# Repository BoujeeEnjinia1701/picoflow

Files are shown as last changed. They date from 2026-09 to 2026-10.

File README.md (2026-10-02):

# PicoFlow

     

**Area:** CleanTech · **TRL:** 3 of 9 (proof of concept on paper) · **Value-engineering target:** about $450 USD · **Difficulty:** 3 of 5

3D-printed Turgo runner in a printed or PVC nozzle housing, driving an off-the-shelf BLDC motor used as a generator, with an MPPT dump-load controller.

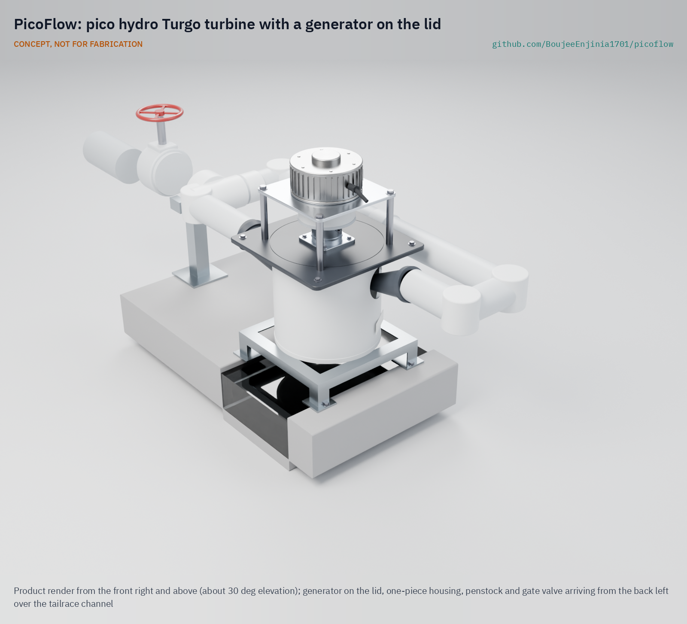
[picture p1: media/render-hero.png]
PicoFlow: pico hydro Turgo turbine with a generator on the lid, product render


[Exploded render](media/render-exploded.png) · [Detail render](media/render-detail.png) · [Interactive 3D model](media/viewer.html) · [Concept blueprint (PDF)](media/concept-blueprint.pdf) · [General arrangement (PDF)](cad/drawings/PCF-DWG-001.pdf) · [Sizing calculations](docs/04-calcs/01-sizing.md) · [Prototype build plan](docs/05-build-plan.md) · [Design decisions](docs/06-design-decisions.md) · [Review note](docs/REVIEW.md)

## Concept rationale

A Turgo runner suits the low heads and debris-laden streams that most households near water actually have. It runs in air above the tailwater, tolerates leaves and sand better than a closed propeller, and keeps its efficiency at part flow, so one runner covers 1 to 3 m of head by changing only the nozzle inserts. Putting the bearings and generator on the lid, above the spray, addresses the main reason cheap low-head units fail: bearings and windings that sit in or near the water.

The design is open and garage-buildable because the households that need it are far from spare-parts supply chains. A 200 mm runner prints on a common desktop printer in about a day, the housing and pipework are standard PVC, and the generator is an off-the-shelf low-speed motor, with a salvaged washing machine motor as the low-cost variant. A local workshop can therefore build, repair and adapt it without depending on a single supplier.

## Burning platform

About 666 million people still had no electricity in 2023, and 85 % of them live in sub-Saharan Africa ([World Bank, Tracking SDG 7: The Energy Progress Report 2025](https://www.worldbank.org/en/topic/energy/publication/tracking-sdg-7-the-energy-progress-report-2025)). Many live in hilly, well-watered areas where a stream runs past the house day and night, and pico hydro turns that flow into continuous power that solar alone cannot match after dark or in the rainy season.

The market has already shown both the demand and the failure mode. In Vietnam, 100,000 to 120,000 cheap low-head propeller units were sold over 10 to 15 years, but probably no more than 30,000 were still running, because most became unusable within 2 to 3 years as lower bearings, seals and generator windings failed ([DFID project R8150, Vietnam country report](https://assets.publishing.service.gov.uk/media/57a08cf340f0b652dd001676/R8150-Vietnam.pdf)). Households paid again and again for power that did not last.

## Where it could be used

### By industry

| Industry | Use |
| --- | --- |
| Rural energy access | Continuous battery charging for lights, phones, radio and small appliances in off-grid homes near streams |
| Agriculture | Power for fence energizers, pump controls, lighting and monitoring on farms with irrigation channels or spring outflows |
| Health and education in remote areas | A second, round-the-clock source beside solar for rural clinics and schools, strongest in the rainy season |
| Tourism and remote huts | Quiet, fuel-free power for mountain huts, lodges and cabins on a stream |
| Environmental monitoring | Local power for stream gauges, water-quality sensors and camera traps at the water's edge |
| Technical training | An inspectable turbine for teaching fluid machinery, power electronics and hydropower siting |

### By country or region

| Country or region | Why it matters there |
| --- | --- |
| Sub-Saharan Africa (for example the highlands of Rwanda, Uganda and eastern DR Congo) | Home to 85 % of the people without electricity ([World Bank, 2025](https://www.worldbank.org/en/topic/energy/publication/tracking-sdg-7-the-energy-progress-report-2025)); many highland homes sit near year-round streams |
| Vietnam (northern uplands) | A proven market for household pico hydro, where most cheap units fail in 2 to 3 years ([DFID R8150](https://assets.publishing.service.gov.uk/media/57a08cf340f0b652dd001676/R8150-Vietnam.pdf)); a durable, repairable unit fits existing habits |
| Nepal | Steep hill streams and a long-standing national program for micro and mini hydro ([AEPC](https://www.aepc.gov.np/pages/minimicro-hydro)); pico units can reach homes beyond a village scheme |
| Peru | A World Bank-supported rural electrification project installed 11,915 solar home systems in isolated areas and prepared studies for 21 small hydropower projects in the country's major basins ([World Bank, 2019](https://www.worldbank.org/en/results/2019/05/13/promoting-rural-electrification-in-peru)); a pico unit could serve scattered mountain homes on a stream beyond those schemes |
| New Zealand and the United Kingdom | High-income off-grid cabins and farms already use commercial pico turbines such as the New Zealand-made PowerSpout ([PowerSpout LH](https://www.powerspout.com/pages/low-head-lh-info)); an open design lowers the cost of a repairable, low-head alternative |

## What sparked the idea

The idea traces back to the Turgo turbine itself. In 1919 the young engineer Eric Crewdson, then a trainee at the English turbine maker Gilkes of Kendal, applied for a patent on a side-entry impulse runner that would run at twice the speed of a Pelton wheel on the same head, with jets striking one side at an angle and discharging from the other; the patent was granted in 1920 ([Gilkes, "100 Years of the Turgo Impulse Turbine"](https://www.gilkes.com/media/1809/100-yrs-of-the-turgo-impulse-rev-4.pdf)). A century on, that higher speed at low head is what lets a small runner drive an off-the-shelf motor directly, without a gearbox, and the University of Bristol's 2013 tests of a Turgo at heads from 3.5 m down to 1 m, which reached 87 % jet-to-mechanical efficiency at 1 m ([Williamson, Stark and Booker, Applied Energy 102](https://research-information.bris.ac.uk/en/publications/performance-of-a-low-head-pico-hydro-turgo-turbine)), showed the principle holds far below its usual range. PicoFlow is an attempt to put Crewdson's runner into a form that a village workshop can print and repair.

## Problem

Remote homes near streams with 1 to 3 m of head have few durable, repairable turbine options: cheap closed units wear out in two or three years, and durable ones cost several times a household budget.

## Concept

3D-printed Turgo runner in a printed or PVC nozzle housing, driving an off-the-shelf BLDC motor used as a generator, with an MPPT dump-load controller.

At 2 m of head and 10 L/s, the TRL 3 sizing calculation (PCF-CAL-001) gives about 86 W into a 12 V battery, or about 2.05 kWh a day, running around the clock, with a 125 mm penstock; pipe, valve and branch losses take about 16 % of the head. The generator sits on the lid above the spray, the dump load keeps the runner from running away when the battery is full, and a hardware clamp holds the DC side below 48 V if the controller fails.

Full design precis: [docs/02-concept.md](docs/02-concept.md)

## Key components

- Printed Turgo runner, 200 mm (PETG prototype, glass-filled nylon for field units), with two opposed 34 mm jets from printed nozzles bolted to the housing
- New low-speed 500 W BLDC motor as generator (a salvaged washing machine motor is the low-cost variant)
- Two sealed flange bearing units above the spray on a stainless shaft
- 125 mm PVC penstock with a slow-closing, full-bore gate valve, forebay screen and 315 mm PVC housing
- Three-phase rectifier
- Open-design MPPT, dump-load and clamp controller for a 12 V battery
- 300 W dump-load resistor and 6.8 ohm, 350 W clamp resistor

The priced bill of materials is in [bom/bom.csv](bom/bom.csv): about $618 for the turbine kit with a new generator, against a value-engineering target of $450; penstock and battery excluded.

## Building the prototype

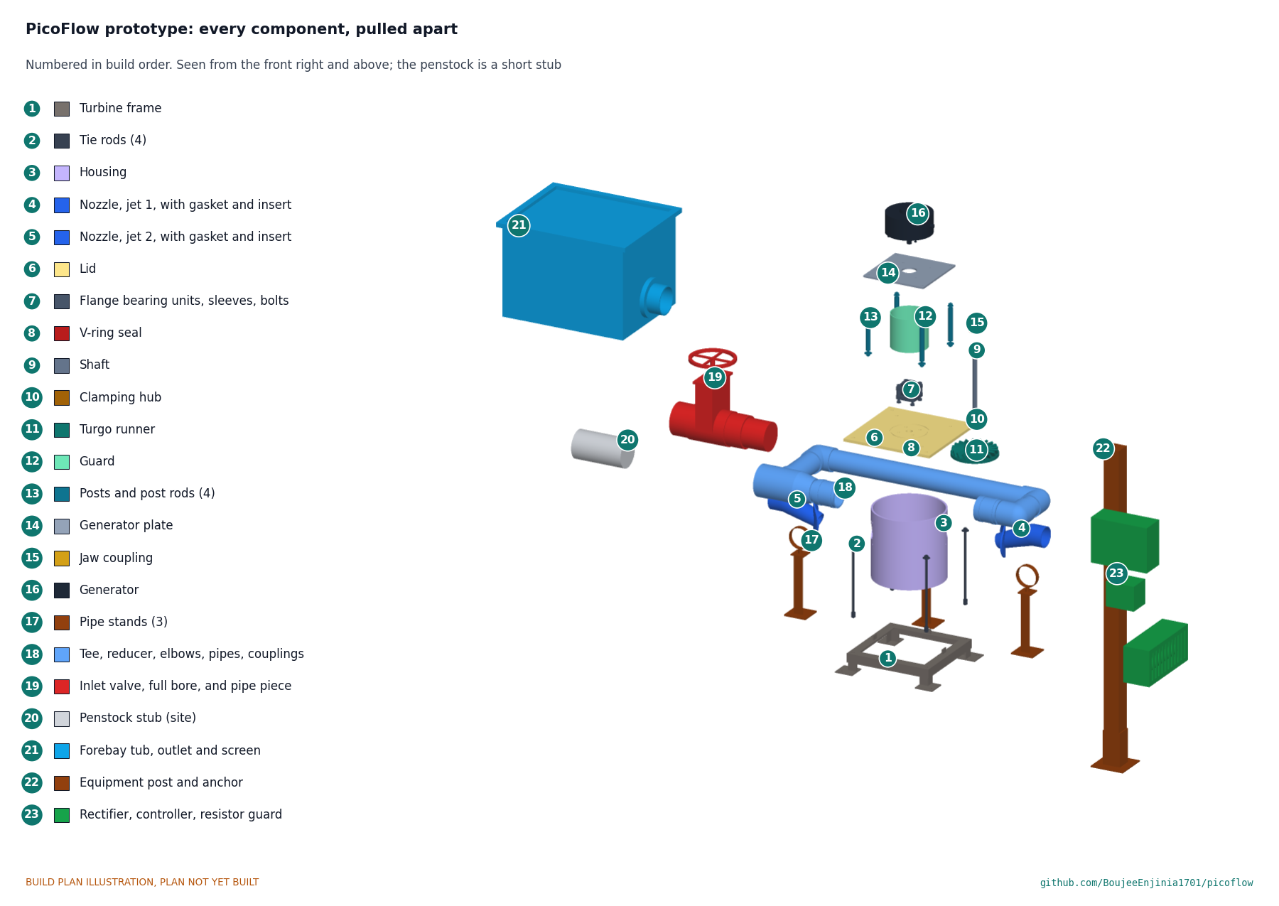
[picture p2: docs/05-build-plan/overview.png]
PicoFlow prototype: every component pulled apart and numbered in build order


The [prototype build plan](docs/05-build-plan.md) (PCF-BLD-001) shows, in pictures, how to make each of the 23 components and put them together in nineteen steps; nothing has been built yet. The made parts are a welded steel frame, a housing cut from sewer pipe, printed nozzles, inserts and runner, a plastic lid, posts, a generator plate, pipe stands, the cut pipework, a forebay and an equipment post; the bearings, generator, fittings, valve and electrics are bought. Writing the plan made the design buildable: tie rods now clamp lid, housing and frame together, flange bearing units replace a machined housing, the nozzles bolt to the housing through gasketed saddles, and the pipework uses standard fittings on three stands (PCF-DDR-003, open for Amish's review). Every picture is drawn from the model, which checks that each part touches what it should and clears what it should not.

## Safety

> Streams and weirs can drown people; install and service only at low flow. The runner and coupling rotate; close the valve and wait for them to stop before opening the housing. With no load and a failed clamp the generator can exceed 60 V DC, so the DC side stays enclosed; the dump load and clamp resistor run hot. Close the gate valve slowly. The 12 V battery needs a BMS and a fuse at the terminal.

## Repository layout

| Folder | Contents |
| --- | --- |
| `docs/` | Problem, concept, requirements, calculations and design decisions |
| `cad/src/` | build123d Python source, the source of truth for all geometry |
| `cad/step/`, `cad/stl/` | Exported models for FreeCAD, other CAD tools and printing |
| `cad/drawings/` | 2D sketches and dimensioned drawings |
| `bom/` | Bill of materials |
| `electronics/` | KiCad schematics and PCB layouts |
| `firmware/` | Microcontroller code |
| `media/` | Renders, perspectives and photos |
| `build-log/` | Dated prototyping notes |

## Documentation

Controlled documents follow the portfolio [documentation standard](.kit/STANDARDS.md). Each carries a document ID (PCF-PRC-001 for the precis), a version and a revision history. Branded PDFs are built with `python .kit/render.py` and attached to GitHub Releases when a document is tagged, for example `PCF-PRC-001/v1.0`.

## Credits

Designed by Amish Chadha. See [CONTRIBUTORS.md](CONTRIBUTORS.md) for roles. To cite this design, use [CITATION.cff](CITATION.cff) (GitHub shows it as "Cite this repository").

AI assistance (Claude) was used to accelerate concept renders, prototype documentation and first-pass sizing calculations. Design direction and all decisions are Amish Chadha's, recorded in this repository's decision records (`docs/decisions/`).

## Licenses

- **Hardware** (CAD, drawings, BOM, electronics): [CERN-OHL-S v2](LICENSE)
- **Software** (firmware, scripts, notebooks): [MIT](LICENSE-SOFTWARE)

A project of the [Design Molecule](https://designmolecule.com) lab.

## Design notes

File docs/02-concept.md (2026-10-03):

---
doc_id: PCF-PRC-001
title: PicoFlow design precis
project: PicoFlow
doc_type: Design precis
version: "0.9"
status: Draft
date: '2026-10-02'
author: Amish Chadha
license: CERN-OHL-S-2.0
revisions:
- version: "0.1"
  date: '2026-09-24'
  author: Amish Chadha
  change: Initial scaffold
- version: "0.2"
  date: '2026-09-25'
  author: Amish Chadha
  change: Populate to TRL 2 (architecture, first-order numbers, safety, media, open questions)
- version: "0.3"
  date: '2026-09-25'
  author: Amish Chadha
  change: TRL 3 update; Amish's 2026-09-25 decisions (PCF-DDR-001), numbers from PCF-CAL-001, 90 mm branches, opposed jets, lowered frame, gate valve, voltage clamp
- version: "0.4"
  date: '2026-09-25'
  author: Amish Chadha
  change: Recommendations accepted by Amish (DDR-002)
- version: "0.5"
  date: '2026-10-01'
  author: Amish Chadha
  change: Constructable design (PCF-DDR-003) and numbers from PCF-CAL-001 v0.3; budget treated as a value-engineering target
- version: "0.6"
  date: '2026-10-01'
  author: Amish Chadha
  change: Full-bore 125 mm inlet valve (N6, option a, decided by Amish 2026-10-01); numbers from PCF-CAL-001 v0.4
- version: "0.7"
  date: '2026-10-01'
  author: Amish Chadha
  change: Clamp resistor 6.8 Ω, 350 W (decided by Amish 2026-10-01; was 8.2 Ω, 300 W); clamp and cost figures from PCF-CAL-001 v0.5
- version: "0.8"
  date: '2026-10-02'
  author: Amish Chadha
  change: "Decisions of 2026-10-02: welding rule, no housing window, polycarbonate or PVC guard, partner selection rule"
- version: "0.9"
  date: '2026-10-02'
  author: Amish Chadha
  change: "Approved follow-up: frame described as steel angle, galvanized or painted after welding"
---

# PicoFlow design precis

PicoFlow is a vertical-shaft pico hydro turbine for 1 to 3 m of head: water from a small forebay runs down a PVC penstock to two opposed printed nozzles, which drive a 200 mm 3D-printed Turgo runner inside an open-bottomed PVC housing. The runner turns a low-speed BLDC motor, used as a generator, that sits on the lid above the spray. An MPPT controller charges a 12 V battery and diverts surplus power to a dump load, and a hardware clamp keeps the DC side below 48 V if everything else fails. The TRL 3 calculation on the constructable design (PCF-CAL-001 v0.3, PCF-DDR-003) gives about 82 W into the battery at 2 m and 10 L/s (1.98 kWh a day), about 26 W at 1 m and about 156 W at 3 m, with a 125 mm penstock (decided by Amish on 2026-09-25, PCF-DDR-002); pipe, valve and branch losses take about 20 % of the head. Value-engineering target: USD 450. Estimated cost of the constructable design: USD 534 for the turbine kit with a new generator (USD 84 over the target), or USD 464 with a salvaged washing machine motor; the penstock and battery are excluded. How to build the prototype is in the build plan, PCF-BLD-001.

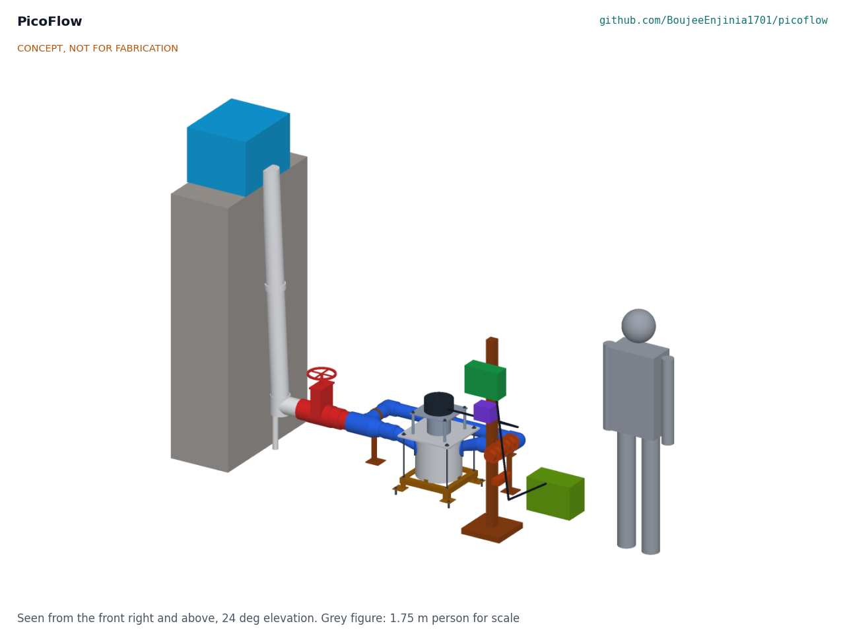
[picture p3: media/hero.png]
Hero render


*Figure 1. PicoFlow at a weir or rock step set for 2.0 m of gross head, with a 1.75 m person for scale. The penstock is drawn short; real sites typically need 10 to 30 m of pipe. Kit parts are colored; the site is grey.*

## How it works

1. **Intake.** A small forebay (a plastic tub or masonry box) at the top of the drop settles sand and passes water through a 6 mm screen. Surplus water spills over the forebay and carries leaves away, so the screen cleans itself.
2. **Penstock.** A 125 mm PVC pipe (decided 2026-09-25, PCF-DDR-002; 110 mm lost about 24 % of the head) carries about 10 L/s down 1 to 3 m of head. Drainage-grade pipe is allowed (decided 2026-09-25) because the static pressure is at most about 29 kPa (4.2 psi) and a multi-turn gate valve at the bottom cannot close in under about 10 s, which keeps the surge to about 34 kPa peak (PCF-CAL-001 section 9).
3. **Nozzles.** A 125 x 90 mm reducing tee splits the flow into two 90 mm branches. One runs straight on through a reducer to its nozzle; the other runs around the housing, so the two jets strike the runner on opposite sides and their radial forces cancel. Each printed nozzle is bolted to the housing wall through a gasketed saddle and joined to its pipe by a flexible coupling; a swappable insert (20 to 45 mm bore) sets the jet, 34 mm at the design point. The jets strike the runner from above at 20 degrees to the runner plane.
4. **Runner.** A printed Turgo runner, 200 mm outside diameter and 150 mm pitch diameter, with 20 buckets, turns at about 318 rpm at the design point. The water leaves the far side of the buckets and falls out of the open bottom of the housing into the tailrace, so nothing floods the runner.
5. **Shaft and bearings.** A 20 mm stainless shaft runs up through the lid into two sealed flange bearing units (UCF204 class) stacked on the lid, above the spray, and drives the generator through a jaw coupling inside a guard.
6. **Generator.** A new low-speed BLDC motor (about 500 W rated, about 10 rpm per volt; decided 2026-09-25) produces three-phase AC, about 28 V DC after the rectifier at the design point. Its mounting plate also accepts a salvaged direct-drive washing machine motor.
7. **Power electronics.** A three-phase bridge rectifies the output. The open-design controller (the TRL 3 design, decided 2026-09-25) runs a buck converter that holds the runner at its best speed (maximum power point tracking, MPPT) and charges the 12 V battery. When the battery is full or disconnected it switches the output into a 300 W dump load. Separately, a comparator on the DC bus switches a 6.8 Ω, 350 W clamp resistor across the bus at 48 V and releases it at 40 V, whatever the microcontroller is doing.

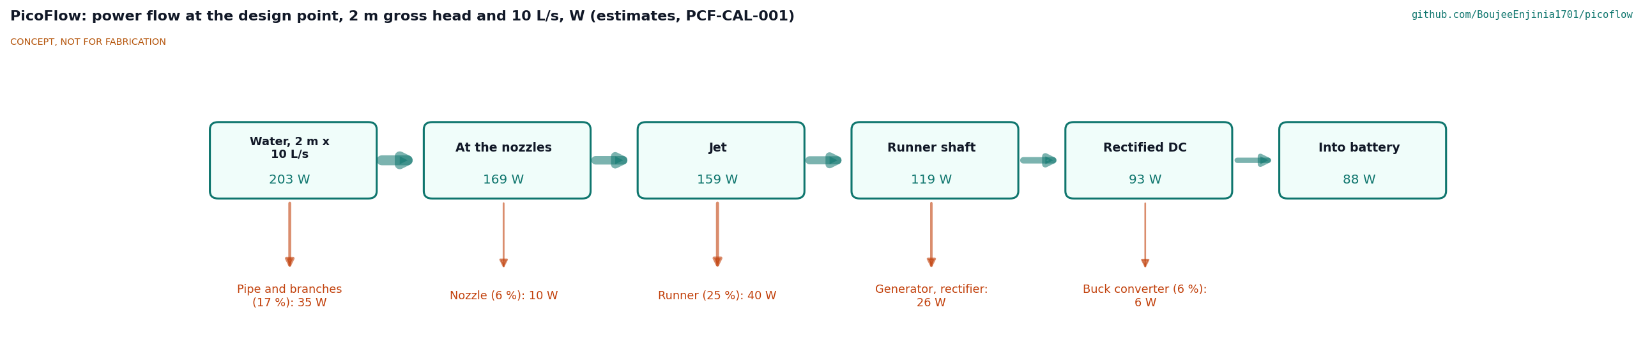
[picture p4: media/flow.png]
Power flow


*Figure 2. Power flow at the design point (2.0 m gross head, 10 L/s), from PCF-CAL-001. All values are estimates.*

## Main components

Numbers match the exploded view (Figure 3), the general arrangement drawing PCF-DWG-001 and `bom/bom.csv`.

| # | Component | Choice | Notes |
| --- | --- | --- | --- |
| 1 | Turgo runner | 200 mm OD, 150 mm pitch diameter, 20 buckets; PETG for the prototype, glass-filled nylon for field units (decided 2026-09-25) | About 525 g, about 21 h to print (R9) |
| 2 | Shaft and hub | 20 mm 316 stainless shaft, 294 mm, clamping hub screwed to the runner | |
| 3 | Bearings, motor mount, guard | Two UCF204-class flange bearing units on the lid; four posts carry an 8 mm generator plate; 160 mm pipe guard over the bearings and coupling | Bearings above the spray (R11); L10 about 8.0 x 10^6 h |
| 4 | Coupling | Jaw coupling with elastomer spider | Inside the guard |
| 5 | Generator | New low-speed BLDC, about 500 W rated, about 10 rpm/V (decided); salvaged washing machine motor as the low-cost variant | About 7 kg |
| 6 | Housing and lid | 315 mm PVC sewer pipe, 303 mm long, open bottom at 80 mm above tailwater; 400 x 400 mm HDPE lid with a groove that locates the housing; four tie rods clamp lid, housing and frame | |
| 7 | Nozzle manifold and nozzles | 125 x 90 mm reducing tee and reducer, 90 mm branches, three elbows, flexible couplings, two printed nozzles with saddles and swappable inserts, opposed jets | Inserts 20 to 45 mm (R2, R10); 34 mm at the design point |
| 8 | Inlet valve | Full-bore 125 mm PVC-U multi-turn gate valve with solvent-weld sockets, joined to the tee by a short piece of penstock pipe | Slow closing (R17); full bore decided by Amish, 2026-10-01 (PCF-DEC-001) |
| 9 | Penstock | 125 mm PVC (SN8), about 20 m, drainage grade allowed, support every 2 to 3 m | Site-dependent; excluded from kit cost; 125 mm decided 2026-09-25 |
| 10 | Forebay and intake screen | Plastic tub or masonry box, 6 mm stainless mesh, overflow lip | Keep the screen clear (surge risk if a nozzle plugs) |
| 11 | Turbine frame | 40 mm bare steel angle, galvanized or painted after welding, 380 mm welded square, short legs and foot plates, anchored to a pad over the tailrace | Nozzles 280 mm above tailwater (R13) |
| 12 | Equipment post | Treated timber post on a base plate | Keeps electronics out of spray and flood |
| 13 | Rectifier | Three-phase bridge, 35 A, 1,000 V, on a heat sink | |
| 14 | MPPT, dump-load and clamp controller | Microcontroller, synchronous buck converter, MOSFET dump-load switch, independent comparator clamp, IP65 box rated for 100 V DC | Open design (decided); off-the-shelf unit for first bench tests only |
| 15 | Dump-load and clamp resistors | 300 W, 12 V heating element or wire-wound resistor; 6.8 Ω, 350 W (or higher rated) aluminium-clad clamp resistor; vented guard | Both run hot |
| 16 | Wiring, fuse and isolator | 4 mm² cable, 20 A fuse at the battery, DC isolator rated 100 V, cable glands | |
| 17 | Battery | 12 V (decided), about 50 Ah LiFePO4 with BMS, or an existing lead-acid battery | Household item; excluded from kit cost |
| 18 | Pipe stands | Three steel angle stands with 90 mm pipe clips | Carry the branch pipework |
| 19 | Fixings | Tie rods, post rods, bolts, nuts, washers, heat-set inserts, anchors | |

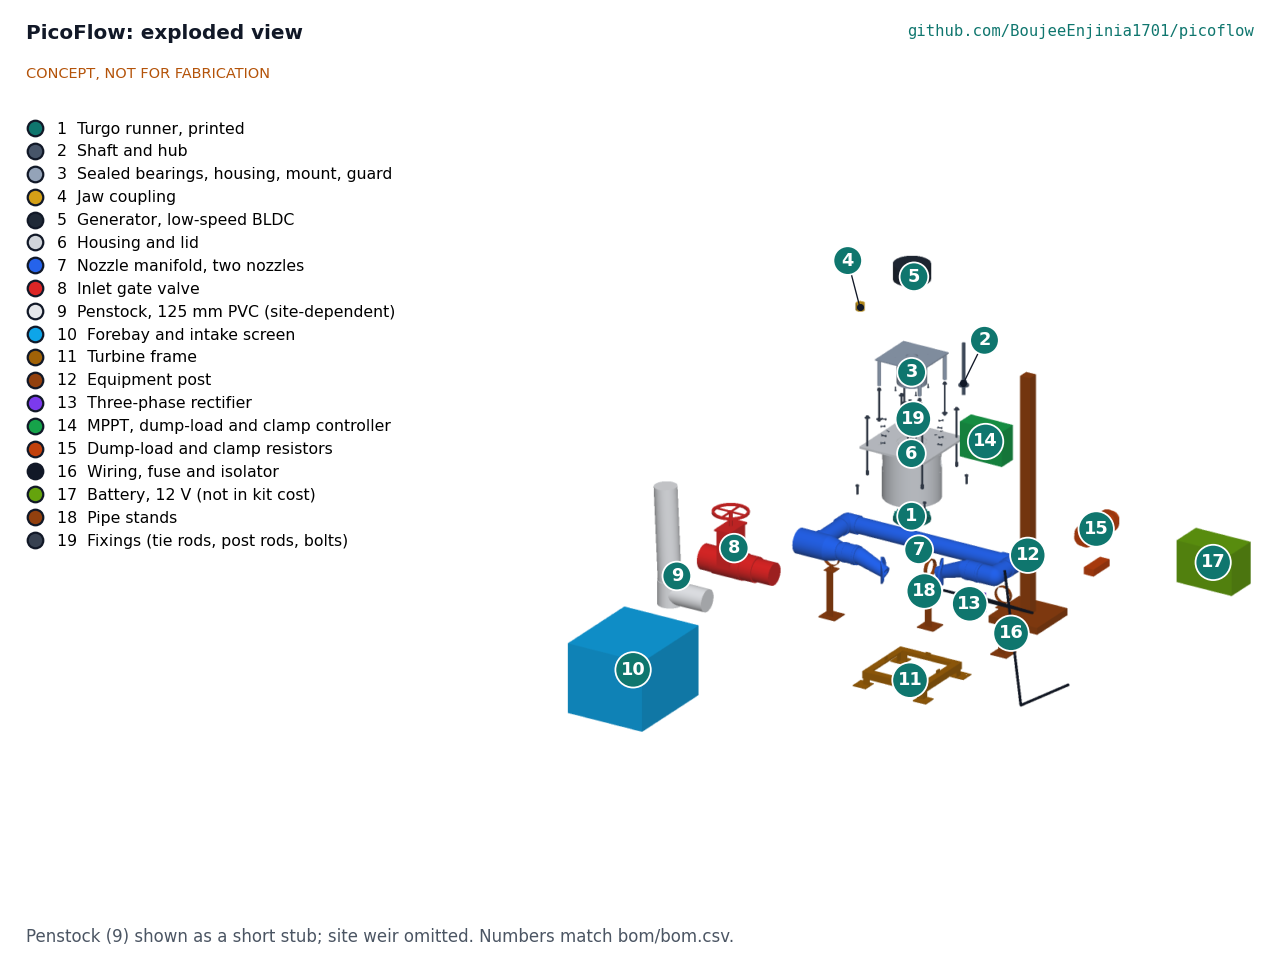
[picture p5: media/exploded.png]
Exploded view


*Figure 3. Exploded view with numbered callouts matching the BOM. The penstock is shown as a short stub and the site weir is omitted.*

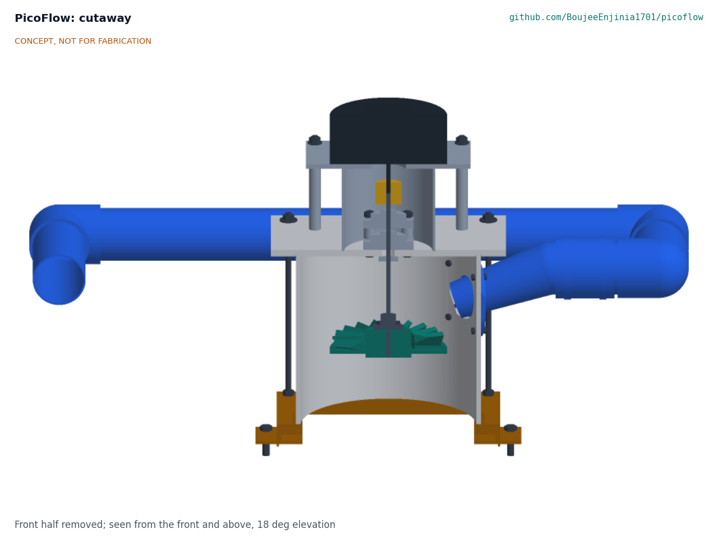
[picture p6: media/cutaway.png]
Cutaway


*Figure 4. Cutaway of the turbine unit: opposed nozzles, runner inside the open-bottomed housing, shaft, bearing housing, guarded coupling and generator above the lid.*

## Key numbers

The numbers below are calculated in PCF-CAL-001 (script `docs/04-calcs/sizing.py`), which lists every assumption. They replace the TRL 2 first-order estimates. The general arrangement is drawing PCF-DWG-001 (`cad/drawings/PCF-DWG-001.pdf`), generated from `cad/src/model.py`.

### Design point: 2.0 m gross head, 10 L/s

| Quantity | Value | Basis |
| --- | --- | --- |
| Gross hydraulic power | 203.2 W | ρ g Q H, 10.36 L/s with 34 mm inserts |
| Pipe, valve and branch loss | 17.0 % of head | 20 m of 125 mm PVC, fittings, full-bore 125 mm valve, 90 mm branches |
| Net head at the nozzles | 1.66 m | |
| Jet velocity, jet size | 5.53 m/s, two 34 mm jets | Velocity coefficient 0.97 |
| Best runner speed, torque | 324 rpm, 3.51 N·m | Bucket speed 0.46 of jet speed; runner 75 % |
| Rectified DC | 93.4 W at 28.2 V | Generator and rectifier 78.5 % |
| **Into the battery** | **87.8 W, 6.46 A at 13.6 V** | Buck converter 94 % |
| Water-to-wire efficiency | 43.2 % | R5 (40 %) met |
| Daily energy | 2.11 kWh | R6 (1.8 kWh) met |

At exactly 10 L/s the output is 85.6 W, 5.6 W over R3, with 43.6 % water to wire and 2.05 kWh a day. The full-bore inlet valve, chosen by Amish on 2026-10-01 (PCF-DEC-001), loses 0.007 m of head; the 90 mm valve with its reducer and expander lost 0.081 m and left 81.7 W, 1.7 W over R3.

### Across the head range

With the design-point inserts, flow rises with head. The bus stays above the 15 V the buck converter needs, so the 12 V battery charges across the whole range.

| Gross head | Flow | Best speed | Bus under load | Into battery | Requirement |
| --- | --- | --- | --- | --- | --- |
| 1.0 m | 7.3 L/s | 229 rpm | 20.1 V | 27.8 W | R4 (20 W) met |
| 2.0 m | 10.4 L/s | 324 rpm | 28.2 V | 87.8 W | R3 (80 W) met |
| 3.0 m | 12.7 L/s | 398 rpm | 34.0 V | 165.4 W | |

At 1.0 m the inserts pass at most about 11.5 L/s, which meets R2 as restated on 2026-09-25 (5 to 10 L/s at 1.0 m, 5 to 15 L/s from 2.0 m).

### Runaway and the voltage clamp

With no load, the runner would reach about 795 rpm at 3.0 m, and the generator about 80 V DC open circuit, above the 60 V extra-low voltage limit. The hardware clamp prevents this: in the worst case (3.0 m, 15 L/s) the 6.8 Ω clamp resistor holds the runner at about 426 rpm and the bus at about 36.7 V, so the bus stays at or below 48 V. That equilibrium is 3.3 V below the clamp's 40 V release point, so the clamp cycles as intended; with the earlier 8.2 Ω resistor it settled at 40.1 V and stayed switched in, which is why Amish chose 6.8 Ω on 2026-10-01 (PCF-CAL-001 section 6). Only a double fault (load and clamp) lets the voltage rise to about 80 V, and the DC side is enclosed and rated for 100 V for that case. The runner rim reaches only about 8.1 m/s at runaway, so the printed runner does not burst; the generator's overspeed rating is still to be confirmed.

### Setting height, loads, mass and life

- **Setting height.** The housing stands on the frame 80 mm above the pad, so the nozzle centerline is 280 mm above normal tailwater (R13 met) and the runner underside is 199 mm above it. The setting height costs 12.3 % of the site drop at the design point, down from about 18 % at TRL 2.
- **Bearing loads** are small: with one jet closed at 3.0 m and 15 L/s, 43 N radial and 105 N axial, giving an L10 life of about 7.1 x 10^6 h. Seal wear and water ingress, not fatigue, will set bearing life. The printed runner's life under sandy water is unknown (R12 at risk).
- **Mass:** turbine unit (items 1 to 6 and 11, with their fixings) 24.5 kg, with the 7 kg generator the heaviest item; the manifold, nozzles and full-bore valve add 9.8 kg and are carried separately (the valve alone about 5.5 kg) (R14; definition confirmed by Amish, 2026-09-25).
- **Surge:** closing the gate valve over 10 s at 3.0 m adds 0.48 m of head; an instant stop would add about 36 m, which is why a quarter-turn ball valve is not allowed.

### Cost

Value-engineering target: USD 450 (a hypothetical control target, not a limit; Amish, 2026-10-01). Estimated cost of the constructable design: USD 618 (USD 168 over the target); the 6.8 Ω, 350 W clamp resistor added USD 4 and the full-bore valve added USD 80 of that, an estimate to be quoted. Cost drivers and savings worth trying are in the design decisions register (PCF-DEC-001).

| Group | Cost | Against the target |
| --- | --- | --- |
| Turbine kit with a new generator (items 1 to 8, 10 to 16, 18, 19) | USD 618.00 | USD 168 over |
| Turbine kit with a salvaged washing machine motor | USD 548.00 | USD 98 over; documented low-cost variant |
| Penstock, 20 m of 125 mm (item 9, excluded) | USD 140.00 | Site-dependent |
| Battery, 12 V 50 Ah LiFePO4 (item 17, excluded) | USD 160.00 | Often already owned |

For comparison, cheap low-head propeller units sold in Vietnam cost $20 to $90, but most last only 2 to 3 years ([DFID R8150](https://assets.publishing.service.gov.uk/media/57a08cf340f0b652dd001676/R8150-Vietnam.pdf)). PicoFlow's case rests on durability, repair and output per dollar over several years, not on first cost.

## Key design choices

Amish decided the TRL 2 review items on 2026-09-25 by accepting every recommendation (PCF-DDR-001), and later that day accepted the TRL 3 recommendations too (PCF-DDR-002).

- **Turgo rather than propeller at 1 to 3 m.** Decided 2026-09-25. A Turgo runs in air, tolerates debris, keeps its efficiency at part flow, and has reached 87 % at 1 m in the lab. Its limit is flow: it suits streams of about 5 to 15 L/s (about 10 L/s at 1 m) rather than the larger flows a propeller such as the PowerSpout LH uses (14 to 55 L/s ([PowerSpout](https://www.powerspout.com/pages/low-head-lh-info))). Confirming that the first target sites are in this range is part of open item O1.
- **Vertical shaft with the generator on the lid.** Decided 2026-09-25.
- **Two jets, opposed.** Decided 2026-09-25 (two jets). Two 34 mm jets keep the jet-to-pitch ratio at 0.23; placing them on opposite sides, a TRL 3 layout choice, cancels their radial forces, and one can be closed in the dry season.
- **Generator.** Decided 2026-09-25: a new low-speed BLDC for the prototype, with a mount that also takes a salvaged direct-drive washing machine motor.
- **Runner material.** Decided 2026-09-25: PETG for the first prototype, glass-filled nylon for field units.
- **Battery voltage.** Decided 2026-09-25: 12 V.
- **Controller.** Decided 2026-09-25: the open-design MPPT, dump-load and clamp board is the TRL 3 design; an off-the-shelf diversion controller is only for the first bench tests (TRL 4, on hold).
- **Drainage pipe for the penstock.** Decided 2026-09-25: allowed with a slow-closing valve and a surge check. The check is in PCF-CAL-001 and the multi-turn gate valve meets R17.
- **Budget.** Decided 2026-09-25: USD 450, with the salvaged-motor variant documented; since 2026-10-01 treated as a value-engineering target, not a limit.
- **90 mm branches.** A TRL 3 sizing result: with the 125 mm penstock, 63 mm branches would lose 27 % of the head instead of 17 %.
- **125 mm penstock.** Decided 2026-09-25 (PCF-DDR-002, N1): cuts pipe and branch loss from 24 % to 17 % of head. The penstock is outside the kit budget; 20 m costs about $140 instead of $100.

Decided by Amish, 2026-09-25 (PCF-DDR-002): the 125 mm design-point penstock (N1), R4 relaxed to 20 W (N2), R2 stated as 5 to 10 L/s at 1.0 m and 5 to 15 L/s from 2.0 m (N3), the R14 definition confirmed (N4) and the $2 cost margin accepted (N5). Still open: the first site type, region and partner (O1), the inlet valve bore against the 125 mm penstock (N6) and the design-for-construction changes of PCF-DDR-003; all are listed in the design decisions register (PCF-DEC-001).

## Safety

> **Safety:** PicoFlow combines moving water at a weir, a spinning runner, a generator that can exceed 60 V DC if both the load and the clamp fail, resistors that run hot, and a lithium battery. Treat each as a hazard at every stage, including site survey.

- **Water and the site.** Weirs, rock steps and streams in flood can drown people, especially children. Install and service only at low flow, never stand on a weir crest, keep the intake and tailrace fenced or covered where children play, and site the turbine above normal flood level. Close the intake before entering the stream. The runner is only 199 mm above normal tailwater, so check flood levels before siting.
- **Rotating parts.** The runner is enclosed in the housing, and the bearings and coupling are inside a guard under the generator plate. Always close the valve and wait for the runner to stop before opening the housing or removing the guard; a runner turning at 300 to 400 rpm can still cut fingers. The housing has no window while the printed runner's life is unproven, and a clear guard must be polycarbonate, never acrylic.
- **Welding.** The frame and pipe stands are welded from bare steel and galvanized or painted afterwards; never weld galvanized steel, which gives off zinc fumes.
- **Runaway voltage.** The hardware clamp keeps the DC bus at 48 V or less, but a double fault can reach about 80 V DC at 3 m head. The DC side must stay enclosed and rated for at least 100 V.
- **Dump load and clamp heat.** The 300 W dump load and the 350 W clamp resistor can exceed 200 °C in still air. Mount them in a vented metal guard, away from timber, dry grass and roofs, or immerse the dump load in a water tank with a thermal cut-out.
- **Lithium battery.** A LiFePO4 battery is less prone to thermal runaway than other lithium chemistries but can still deliver hundreds of amperes into a short circuit. Use a battery with a BMS, a 20 A fuse within 300 mm of the battery terminal, charge-temperature limits from the BMS, and a dry, ventilated, non-combustible location. Lead-acid batteries vent hydrogen while charging and need ventilation.
- **Water hammer.** Use only the multi-turn gate valve and close it over at least 10 s. Never fit a quarter-turn ball valve: an instant stop on a 20 m penstock could add about 35 m of head and burst drainage pipe. Keep the screen clear, because a nozzle plugged all at once could add about 18 m.
- **Environment and permits.** Leave enough water in the stream for fish and downstream users (R16), screen the intake, and check local water-use rules before building.

## Open questions (TRL 4 is on hold)

- Measure the chosen generator's constant (rpm per volt), resistance, losses at 200 to 400 rpm and overspeed rating.
- Confirm the runner efficiency of a printable bucket shape against the Bristol low-head results.
- Confirm the drainage pipe joint rating with the supplier.
- Check PETG and nylon creep, water uptake and sand erosion under continuous duty (R12).
- Choose the first site type, region and partner (O1). Selection rule decided 2026-10-02: hilly off-grid communities with streams of 5 to 15 L/s and 1 to 3 m of head, confirmed by dry-season flow measurements; first candidate type to approach, a micro-hydro NGO such as Practical Action's energy programmes in Nepal or Peru. Nothing is agreed.

Concept media: [blueprint sheet](../media/concept-blueprint.pdf), [interactive 3D model](../media/viewer.html).

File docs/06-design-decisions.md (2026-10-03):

---
doc_id: PCF-DEC-001
title: PicoFlow design decisions register
project: PicoFlow
doc_type: Design decisions register
version: "0.5"
status: Draft
date: '2026-10-02'
author: Amish Chadha
license: CERN-OHL-S-2.0
revisions:
- version: "0.1"
  date: '2026-10-01'
  author: Amish Chadha
  change: Register opened with the open decisions from the review notes, PCF-DDR-001 to 003 and the build plan work
- version: "0.2"
  date: '2026-10-01'
  author: Amish Chadha
  change: Open decision 2 (inlet valve bore, N6) decided by Amish as recommended and moved to Decisions made; open items renumbered; clamp resistor added as a proposed item; value engineering updated for the full-bore valve
- version: "0.3"
  date: '2026-10-01'
  author: Amish Chadha
  change: Amish accepted the recommendation of open item 8 (clamp resistor, option b, 6.8 Ω, 350 W); moved to Decisions made; value engineering updated (line 15 re-priced)
- version: "0.4"
  date: '2026-10-02'
  author: Amish Chadha
  change: "Amish approved the recommendations for all open decisions 1 to 7 on 2026-10-02 (PCF-DDR-003 accepted; welded then galvanized frame; no window; polycarbonate or PVC guard); moved to decisions made"
- version: "0.5"
  date: '2026-10-02'
  author: Amish Chadha
  change: "Approved follow-ups carried out (BOM lines 11 and 18 coating wording, making sketches, appearance model); valve quote still to get"
---

# PicoFlow design decisions register

Every design decision still to be made, and every decision made, in one place. Each decision is argued in full in its decision record under `docs/decisions/`; this register is the index Amish works from. The build plan (`docs/05-build-plan.md`) describes the design as it stands and does not list open decisions.

## Open decisions

None. All open decisions were decided on 2026-10-02.

## To confirm when parts are bought

| # | What to confirm | Why it matters | Source |
| --- | --- | --- | --- |
| 1 | Generator: rpm per volt, losses and resistance at 200 to 400 rpm, overspeed rating at about 800 rpm, face screw circle and spigot, and a shaft at least 50 mm long | The calculation assumes 10 rpm/V; the plate holes and coupling position follow the face and shaft | PCF-CAL-001; PCF-DDR-003, P7 |
| 2 | Flange bearing units: 86 mm square, 64 mm bolt pitch, about 33 mm tall, 12.8 kN load rating | They set the lid holes, sleeve length and coupling height | PCF-DDR-003, P3 |
| 3 | Socket depths and centre-to-mouth sizes of the tee, reducer and elbows | The five pipe cut lengths assume 45 mm sockets and 70 mm elbow centre to mouth | PCF-DDR-003, P10 |
| 4 | The 90 mm flexible couplings fit the 90 mm printed spigot snugly | The spigot is printed; its outside may need sanding or a wrap of tape | PCF-DDR-003, P5 |
| 5 | Drainage pipe joints are good for 50 kPa | The surge check (R17) assumes it | PCF-CAL-001, section 9 |
| 6 | Full-bore 125 mm gate valve: socket depth (70 mm assumed), length over the sockets (330 mm), bore about 117 mm, mass (about 5.5 kg), price (USD 115 assumed), and that it takes about ten turns to close | Sets the pipe piece length, the valve loss and the pipework mass, and enforces the 10 s closure (R17) | PCF-CAL-001 v0.4; PCF-DDR-001, D8; decision of 2026-10-01 |
| 7 | Forebay tub size and wall stiffness for a 125 mm tank connector | The outlet hole and screen frame follow the tub | PCF-DDR-003, P13 |

## Value engineering

Value-engineering target: USD 450 (a hypothetical control target, not a limit). Estimated cost of the constructable design: USD 618 for the turbine kit with a new generator (USD 168 over the target); USD 548 with a salvaged washing machine motor (USD 98 over the target). The penstock (about USD 140 for 20 m) and the battery (about USD 160) are outside the kit, as decided with the budget. Main cost drivers and savings worth trying:

- The largest lines are the full-bore inlet valve (USD 120, an estimate), the generator (USD 110), the nozzle manifold (USD 50), the controller (USD 43), the bearing units, plate, posts and guard (USD 43) and the housing and lid (USD 35). The 6.8 Ω, 350 W clamp resistor (decided 2026-10-01) raised line 15 from USD 28 to USD 32, an indicative price to be quoted.
- Making the design constructable added USD 86: fixings (USD 28), pipe stands (USD 15), flexible couplings and the reducer (USD 12), flange bearing units and plate (USD 10), valve fittings (USD 8, since replaced by the full-bore valve, so the construction additions still in the estimate are USD 78), the forebay tank connector and screen frame (USD 8), and smaller items (USD 5).
- Savings worth trying: a salvaged washing machine motor (about USD 70 less, already the documented variant); a 6 mm steel generator plate instead of 8 mm aluminium (a few dollars, about 0.6 kg heavier); timber pipe stands; buying fixings as one bulk pack. The full-bore valve (decided 2026-10-01) raised line 8 from USD 40 to USD 120 to recover 3.9 W at the design point, about USD 21 per watt; no published price was found for a 125 mm PVC-U gate valve, so getting real quotes is the first saving to try, and a cheaper full-bore valve of the same kind would bring most of the USD 80 back.

## Decisions made

| Date | Decision | Decided by | Record |
| --- | --- | --- | --- |
| 2026-09-25 | TRL 2 review items D1 to D10: budget USD 450 with the salvaged-motor variant documented, new low-speed BLDC generator, open-design controller (off-the-shelf only for first bench tests), 12 V battery, PETG then glass-filled nylon runner, vertical shaft, two jets, drainage pipe with a slow-closing valve, problem wording, Turgo | Amish: "proceed with all of your recommendations across all batches. Make sure we don't proceed to TRL 4 on any of them." | PCF-DDR-001 |
| 2026-09-25 | TRL 3 items N1 to N5: 125 mm design-point penstock, R4 relaxed to 20 W, R2 stated per head, R14 turbine-unit definition, USD 2 cost margin accepted | Amish: "i accept all your recommendations, go with them across all repos." | PCF-DDR-002 |
| 2026-09-30 | Make the design physically buildable while drawing the build plan | Amish: "If you are realising that the design cannot be built as per concept - fix the design assumptions to match and be physically feasible as you draw the illustrations." | PCF-DDR-003 (changes accepted on 2026-10-02, below) |
| 2026-09-30 | Outstanding decisions are kept in this register, not in the build plan | Amish: "don't log outstanding decisions in this build plan - that is not the place for it. that should be in a separate design document logged and named as such" | This register |
| 2026-10-01 | Inlet valve bore (N6, open decision 2 in register v0.1): option (a), a full-bore valve matched to the 125 mm penstock, re-priced. A 125 mm PVC-U gate valve with solvent-weld sockets replaces the 90 mm valve, reducer and expander: 85.6 W at exactly 10 L/s, 5.6 W over R3; line 8 USD 120 | Amish: "picoflow - i agree with the recommendation" | PCF-DDR-003, A2; PCF-CAL-001 v0.4 |
| 2026-10-01 | The budget is a value-engineering target, not a limit | Amish: "the budgets are a hypothethical control target to ensure we are thinking along a value engineering lens. its ok to ensure wording reflects that the hypothesis budget was x - the real cost being accrued is y" | This register, Value engineering |
| 2026-10-01 | Clamp resistor (R8, open item 8 in register v0.2): option (b), a 6.8 Ω aluminium-clad clamp resistor rated 350 W or more replaces the 8.2 Ω, 300 W one. In the worst case (3.0 m, 15 L/s) the clamp now settles the bus at 36.7 V, 3.3 V below its 40 V release, so it cycles as intended (the 8.2 Ω resistor settled at 40.1 V); 339 W at the 48 V switch-on point, inside the 350 W rating. BOM line 15 USD 32 (+USD 4) | Amish: "I approve of your recommendations for PicoFlow and GravitySort" | PCF-CAL-001 v0.5, section 6 |
| 2026-10-02 | Design for construction accepted: the changes P1 to P14 of PCF-DDR-003 and their knock-on changes, as made; P11's valve fittings are already replaced by the full-bore valve decided on 2026-10-01 | Amish: "i approve your recommendations for all 555 open decisions." | PCF-DDR-003, A1 and Tables 1 and 2 |
| 2026-10-02 | Frame (option a): welded by a local fabricator from bare steel, then hot-dip galvanized or painted; never welded after galvanizing | Amish: "i approve your recommendations for all 555 open decisions." | PCF-DDR-003, A3 |
| 2026-10-02 | First site type, region and partner: kept open under the portfolio rule, chosen as hilly off-grid communities with streams of 5 to 15 L/s and 1 to 3 m of head, confirmed by dry-season flow measurements. First candidate type to approach: a micro-hydro NGO, for example Practical Action's energy programmes in Nepal or Peru | Amish: "i approve your recommendations for all 555 open decisions." | PCF-DDR-001 and 002, O1 |
| 2026-10-02 | Housing (option a): the one-piece pipe is kept; the runner is inspected by lifting the lid | Amish: "i approve your recommendations for all 555 open decisions." | REVIEW 2026-09-26, item 1 |
| 2026-10-02 | Inspection window (option a, changed from b): no window in the kit; kept as a later teaching option in impact-rated polycarbonate, only after the runner has passed its life test | Amish: "i approve your recommendations for all 555 open decisions." | REVIEW 2026-09-26, item 2 |
| 2026-10-02 | Guard: a clear guard (option b) only if the clear tube is polycarbonate, never acrylic; otherwise the 160 mm PVC guard stays, and the spider is checked with the turbine stopped and the plate off | Amish: "i approve your recommendations for all 555 open decisions." | REVIEW 2026-09-26, item 3; PCF-DDR-003, P9 |
| 2026-10-02 | Render layout choices (rectifier box loose beside the unit; tailwater 20 mm below the channel edge) accepted as render choices | Amish: "i approve your recommendations for all 555 open decisions." | REVIEW 2026-09-26, items 5 and 6 |
| 2026-10-02 | Follow-ups of the open-decision sign-off that need BOM, drawing or appearance model work are carried out: frame and pipe stand wording and making sketches (bare steel, galvanized or painted after welding); appearance model without the housing window and split, with a PVC guard. Real quotes for the full-bore 125 mm valve and the photoreal renders are still to do | Amish: "APPROVED CHANGES, COMPLETE THESE" | [REVIEW.md](REVIEW.md), session 2026-10-02 (approved follow-ups carried out) |

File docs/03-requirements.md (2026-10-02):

---
doc_id: PCF-REQ-001
title: PicoFlow requirements
project: PicoFlow
doc_type: Requirements
version: "0.7"
status: Draft
date: '2026-10-01'
author: Amish Chadha
license: CERN-OHL-S-2.0
revisions:
- version: "0.1"
  date: '2026-09-24'
  author: Amish Chadha
  change: Initial scaffold
- version: "0.2"
  date: '2026-09-25'
  author: Amish Chadha
  change: First measurable requirements for TRL 2, with status against the concept estimates
- version: "0.3"
  date: '2026-09-25'
  author: Amish Chadha
  change: Apply Amish's 2026-09-25 decisions (PCF-DDR-001), R15 to $450, add R17 penstock surge, status from PCF-CAL-001
- version: "0.4"
  date: '2026-09-25'
  author: Amish Chadha
  change: Recommendations accepted by Amish (DDR-002)
- version: "0.5"
  date: '2026-10-01'
  author: Amish Chadha
  change: Status from PCF-CAL-001 v0.3 on the constructable design (PCF-DDR-003); R15 reported against the value-engineering target
- version: "0.6"
  date: '2026-10-01'
  author: Amish Chadha
  change: Status from PCF-CAL-001 v0.4 with the full-bore inlet valve (N6, option a, decided by Amish 2026-10-01)
- version: "0.7"
  date: '2026-10-01'
  author: Amish Chadha
  change: R8 and R15 status from PCF-CAL-001 v0.5 with the 6.8 Ω, 350 W clamp resistor (decided by Amish 2026-10-01)
---

# PicoFlow requirements

These requirements were set at TRL 2 and checked by calculation at TRL 3 in PCF-CAL-001 v0.5, on the constructable design of PCF-DDR-003 with the full-bore inlet valve decided by Amish on 2026-10-01 (PCF-DEC-001). The status column gives the TRL 3 result; "not verifiable at TRL 3" means a bench or site test is needed. Decisions of 2026-09-25 are recorded in PCF-DDR-001 (the value-engineering target in R15 is USD 450, and R17 was added for the drainage-grade penstock) and PCF-DDR-002 (125 mm design-point penstock, R2 stated per head, R4 relaxed to 20 W, R14 definition confirmed, R15 margin accepted). Targets are still not validated with users or at a site.

The **design point** used throughout is 2.0 m of gross head (forebay water surface to nozzle centerline) and 10 L/s through two nozzles, with a 20 m run of 125 mm PVC penstock (decided by Amish, 2026-09-25, PCF-DDR-002).

| ID | Requirement | Target | Verification (TRL 3 or later) | Status (PCF-CAL-001) |
| --- | --- | --- | --- | --- |
| R1 | Operating head range | Generates from 1.0 to 3.0 m gross head with the same runner, changing only nozzle inserts | Performance calculation across the range | Met; DC bus 20.1 V at 1.0 m |
| R2 | Flow range | 5 to 10 L/s at 1.0 m and 5 to 15 L/s from 2.0 m gross head, through interchangeable nozzle inserts, one or two jets | Nozzle sizing calculation | Met; 1.3 to 11.5 L/s at 1.0 m, 1.9 to 16.4 L/s at 2.0 m |
| R3 | Output at the design point | 80 W or more DC into the battery at 2.0 m and 10 L/s | Efficiency chain calculation; later bench test | Met, 85.6 W at exactly 10 L/s (5.6 W margin); 87.8 W with the 34 mm inserts |
| R4 | Output at the lowest head | 20 W or more DC into the battery at 1.0 m and 7 L/s | Efficiency chain calculation | Met, 26.8 W |
| R5 | Water-to-wire efficiency | 40 % or more at the design point, from gross hydraulic power to DC into the battery | Calculation; later test | Met, 43.6 % at 10 L/s |
| R6 | Daily energy | 1.8 kWh or more per day at the design point, running 24 h | Calculation | Met, 2.05 kWh at 10 L/s |
| R7 | Battery charging and load control | Charges a 12 V nominal battery; holds the runner within 10 % of its best speed while charging; diverts 100 % of output to the dump load within 1 s when the battery is full or disconnected | Controller design review; later bench test | Not verifiable at TRL 3; dump load 1.64 times the largest output |
| R8 | Runaway and touch voltage | Every part survives indefinite runaway at 3.0 m head with no damage; no exposed conductor above 60 V DC in any state, including runaway | Speed and voltage calculation; design review | Met by calculation: hardware clamp keeps the bus at 48 V or less (6.8 Ω clamp resistor, worst-case equilibrium 36.7 V, 3.3 V below the 40 V release); 79.5 V only on a double fault, inside the enclosed 100 V DC side; generator overspeed rating to confirm |
| R9 | Printable parts | Runner and nozzles print on a 220 x 220 x 250 mm build volume in PETG or nylon; runner prints in 24 h or less | Model check; slicer estimate | Met (estimate); runner 200 x 200 x 50 mm, about 21 h; nozzle 167 x 130 x 244 mm |
| R10 | Debris tolerance | Intake screen aperture 6 mm or less; smallest nozzle 20 mm or more; screen self-cleans by overflow | Design review | Met by design |
| R11 | Serviceability | Runner or nozzle inserts replaced with hand tools in 30 min or less; bearings in 60 min or less; bearings and generator above the spray zone | Design review; later timed trial | Not verifiable at TRL 3; bearings above the spray by layout |
| R12 | Service life | Bearing L10 life 20,000 h or more; runner 1 year (8,760 h) or more before replacement | Bearing life calculation; material review | **At risk**; bearings about 7.1 x 10^6 h, printed runner life unknown |
| R13 | Setting height | Nozzle centerline 0.3 m or less above normal tailwater, so little head is lost below the jet | Model check | Met, 280 mm in the model |
| R14 | Portability | Heaviest single item 15 kg or less; turbine unit (items 1 to 6 and 11) 25 kg or less, carried to site by two people | Mass estimate | Met, 24.5 kg with its fixings; generator 7.0 kg; full-bore valve about 5.5 kg, carried with the pipework (definition confirmed by Amish, PCF-DDR-002) |
| R15 | Cost | Turbine kit (all items except penstock and battery) against a USD 450 value-engineering target, a hypothetical control target rather than a limit (Amish, 2026-10-01); salvaged-motor variant documented | Priced BOM (`bom/bom.csv`) | Over the USD 450 value-engineering target by USD 168: USD 618 with a new generator; USD 548 with a salvaged motor (PCF-CAL-001 v0.5) |
| R16 | Stream protection | Takes no more than half of the dry-season stream flow and returns all water to the same stream; intake passes fish-safe overflow | Site survey; design review | Not verifiable at TRL 3 (site-dependent) |
| R17 | Penstock surge | Peak pressure at the valve (static plus surge) 50 kPa or less at 3.0 m head, with a valve that cannot close in under 10 s | Surge calculation | Met, 33.5 kPa with a multi-turn gate valve |

## Requirements not met or at risk

No requirement is not met by calculation on the constructable design (PCF-CAL-001 v0.5):

- **R2** is stated per head (5 to 10 L/s at 1.0 m, 5 to 15 L/s from 2.0 m), because 15 L/s at 1.0 m would need 55 mm jets on a 150 mm pitch circle.
- **R3 and R5** are met (85.6 W at exactly 10 L/s, 43.6 %) with the full-bore 125 mm inlet valve that Amish chose on 2026-10-01 (PCF-DEC-001). The margin on R3 is 5.6 W, up from 1.7 W with the 90 mm valve and its reducer and expander; it still depends on the runner reaching about 70 % or more against the assumed 75 %.
- **R4** was relaxed from 30 W to 20 W; the calculation gives 26.8 W.
- **R12 (runner life) remains at risk.** Only a TRL 4 test can close it.
- **R15** is reported against the value-engineering target (Amish, 2026-10-01): the constructable kit is USD 618, USD 168 over the USD 450 target; the full-bore valve added USD 80 of that and the 6.8 Ω, 350 W clamp resistor USD 4 (an estimate, to be quoted). Cost drivers and savings worth trying are in PCF-DEC-001.

## Budget scope

The USD 450 value-engineering target covers the turbine kit: runner, shaft, bearings, coupling, generator, housing, manifold and nozzles, valve, forebay and screen, frame, equipment post, rectifier, controller, dump-load and clamp resistors, wiring, pipe stands and fixings. The penstock and the household battery are site- and household-specific and are costed separately (decided by Amish, 2026-09-25, PCF-DDR-001 D1).

## Assumptions

The full list is in PCF-CAL-001 section 2. The main ones are:

- Penstock: 125 mm drainage PVC, SN8 (117.6 mm bore), 20 m, with a rounded entrance, screen, two bends and a full-bore 125 mm gate valve; branches 90 mm.
- Nozzle velocity coefficient 0.97.
- Runner jet-to-shaft efficiency 75 % for a first printed design, below the 87 to 91 % reached in laboratory work on an optimized low-head Turgo ([Williamson et al., 2013](https://research-information.bris.ac.uk/en/publications/performance-of-a-low-head-pico-hydro-turgo-turbine)).
- Generator about 10 rpm per volt of rectified DC, 12 W fixed loss at 340 rpm, 0.8 Ω; rectifier 1.6 V drop; buck converter 94 %.
- Drainage pipe joints good for 50 kPa, to be confirmed with the supplier.

> **Safety:** R8 and R17 are safety requirements. They are met on paper only; neither the clamp nor the pipe rating has been tested.

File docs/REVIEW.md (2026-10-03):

# Review note: PicoFlow

## Session 2026-09-25: /populate to a strong TRL 2 (overnight batch run)

### What was done

- `docs/01-problem.md` (PCF-PRB-001 v0.2): problem, users, site context, constraints, out of scope, prior work with inline sources (World Bank SDG 7 report 2025, DFID R8150 Vietnam report, PowerSpout TRG, LH and DIY rotor pages, Williamson et al. 2013, Benzon et al. 2016, University of Bristol), open questions. There was no co-design checklist to keep.
- `docs/03-requirements.md` (PCF-REQ-001 v0.2): 16 measurable requirements (R1 to R16) with targets, verification and an estimated status column, plus a list of requirements not met.
- `docs/02-concept.md` (PCF-PRC-001 v0.2): how it works, 17 numbered components, design point and head-range numbers, runaway voltage, loads, mass, setting height, cost, design choices, safety section, open questions.
- `cad/src/concept_media.py`: massing model of the turbine unit (runner, shaft, bearing housing, coupling, generator, housing, two-nozzle manifold, valve, frame), the site (2.2 m weir, forebay, penstock) and the electrics (post, rectifier, controller, dump load, wiring, battery), each with a BOM number. A custom exploded view leaves the weir out and draws the penstock as a stub so the parts read clearly.
- `media/`: `hero.png` (1.75 m figure), `concept-blueprint.png`, `.pdf` and `.svg`, `cutaway.png`, `exploded.png` (callouts 1 to 17), `flow.png` (power flow at the design point, estimates), `model.glb` and `viewer.html`.
- `bom/bom.csv`: 17 lines with indicative USD costs, numbered to match the exploded view; `bom/bom-notes.md` gives the kit totals and exclusions.
- `README.md`: hero image and links line before "## Problem"; problem, concept, key components and a safety note brought in line with the concept.
- `project.yaml`: `problem` reworded (see decision 9). Budget, TRL, name, slug, area, licenses and pitch unchanged.
- `docs/pdf/`: branded PDFs of the three controlled documents.

### Key results (estimates, to be checked at TRL 3)

| Quantity | Estimate | Requirement |
| --- | --- | --- |
| Design point | 2.0 m gross head, 10 L/s, 196 W hydraulic | |
| Jets | two, about 33 mm, at about 5.8 m/s | |
| Runner | 200 mm OD, 150 mm pitch, about 340 rpm, about 3.5 N·m | R9 met |
| Into the 12 V battery | about 90 W (about 46 % water to wire) | R3, R5 met, thin margin |
| Daily energy | about 2.2 kWh | R6 met |
| Output at 1.0 m / 3.0 m | about 30 W / about 165 W | R4 at risk |
| Runaway at 3.0 m | about 750 to 830 rpm, about 75 to 83 V DC open circuit | **R8 not met** |
| Nozzle height above tailrace | about 0.44 m (target 0.3 m) | **R13 not met** |
| Turbine unit mass | about 20 kg | R14 met |
| Kit cost, new generator | about $424 (penstock and battery excluded) | **R15 not met, about 21 % over** |
| Kit cost, salvaged washing machine motor | about $354 | About at budget |

Requirements not met or at risk: **R8** (touch voltage at runaway), **R13** (setting height), **R15** (cost), **R4** (30 W at 1 m, at risk), **R12** (printed runner life, at risk). R7 (controller behavior) and R16 (stream protection) are unverified or site-dependent.

### Proposed, awaiting Amish

Items 1 to 10 were later decided by Amish, 2026-09-25: go with recommendation (PCF-DDR-001, D1 to D10). Item 11 has no recommendation and stays proposed, awaiting Amish (O1).

1. **Budget.** The kit is about $424 with a new generator against `budget_usd: 350`. Options: (a) keep $350 and make the salvaged washing machine motor the baseline (about $354); (b) raise `budget_usd` to $450; (c) keep $350 and cut elsewhere (printed housing, cheaper valve), which is unlikely to close $74 alone. Recommendation: (b) for the prototype, so the reference build uses a repeatable generator, with (a) documented as the low-cost variant. `project.yaml` is unchanged.
2. **Generator.** A: new low-speed BLDC with a shaft (recommended for the prototype). B: salvaged direct-drive washing machine motor. C: e-bike hub motor with the runner on the disc flange.
3. **Controller.** A: open-design MPPT and dump-load board. B: off-the-shelf diversion controller. Recommendation: B for first bench tests, A as the TRL 3 design.
4. **Battery voltage.** 12 V (recommended; charges across 1 to 3 m with a buck converter) or 24 V (needs buck-boost at 1 m).
5. **Runner material.** PETG for the prototype, glass-filled nylon for field units (recommended), or nylon from the start.
6. **Layout.** Vertical shaft with the generator on the lid (recommended) or horizontal shaft.
7. **Two jets** (recommended) or one.
8. **Penstock pipe class.** Allow non-pressure drainage pipe with a slow-closing valve and a surge check (recommended), or require pressure pipe.
9. **Problem wording in `project.yaml`.** "No simple turbine option" is contradicted by the 100,000 or more cheap low-head units sold in Vietnam (DFID R8150). Changed to "few durable, repairable turbine options", which keeps the meaning. Revert if preferred.
10. **Turgo versus propeller.** The pitch's Turgo is kept. At sites with much more than 15 L/s a propeller may be better; confirm the target site type.
11. **First site type, region and partner** for co-design and a site survey.

### Safety concerns

- Drowning and flood risk at weirs and streams during survey, installation and service.
- Runaway voltage above 60 V DC if the load and dump load both fail (R8); needs a hardware clamp and a DC side rated and enclosed for 100 V.
- Exposed coupling between lid and generator; needs a guard.
- Dump-load resistor surface temperatures above 200 °C; fire risk near timber or grass.
- Battery short-circuit current (LiFePO4) or hydrogen venting (lead-acid); fuse at the terminal, BMS, ventilation.
- Water hammer from fast valve closure on a long penstock.
- Stream diversion effects on fish and downstream users; permits.

### Problems and notes

- The hero and blueprint show a short, steep penstock at a weir so the figure stays compact; typical sites need 10 to 30 m of pipe at a gentler slope. The caption says so.
- The massing model's frame height (0.44 m to the nozzles) is the reason R13 fails; it was left as drawn so the gap is visible.
- The legacy `cad/src/model.py` placeholder is untouched (TRL 3 work).
- The portfolio's SwapCell 48 V pack is not used; a 12 V household battery fits this design better.
- Suggestion, not added to the repo: a co-design checklist (site survey, users, flow records through a dry season) in PCF-PRB-001, like the one in SunSpoke.

### Recommended next step

Review this note and the media, then decide items 1 to 4. If approved, run `/advance-trl3` to size the runner and nozzles by calculation, confirm the generator constant, design the runaway clamp, lower the frame, and produce the parametric model and drawing sheet.

## Session 2026-09-25: TRL 3

Amish approved all TRL 2 recommendations on 2026-09-25 ("proceed with all of your recommendations across all batches. Make sure we don't proceed to TRL 4 on any of them."). This session took PicoFlow to TRL 3 and stopped there.

### What was done

- `docs/decisions/0001-trl2-review-decisions.md` (PCF-DDR-001 v0.1): decisions D1 to D10 recorded as "Decided by Amish, 2026-09-25: go with recommendation"; O1 left open; new TRL 3 items N1 to N5 proposed.
- `docs/04-calcs/01-sizing.md` (PCF-CAL-001 v0.1) and `docs/04-calcs/sizing.py`: first-principles hydraulics (Darcy-Weisbach with fittings, per-branch flow split), power chain with a generator loss model, head and flow range, sensitivity, runaway and clamp sizing, bearing life, print time, mass, penstock surge, dump load and cost. The script prints every quoted number and writes `docs/04-calcs/results.json`.
- `cad/src/model.py`: parametric build123d model of the turbine unit (runner, shaft, bearing housing with posts, plate and coupling guard, coupling, generator, housing and lid, 90 mm manifold with opposed nozzles, gate valve, penstock stub, frame). Exports `cad/step/picoflow-turbine-assembly.step` and `.stl` plus the runner, manifold, housing and bearing mount separately.
- `cad/src/sheets.py` and `cad/drawings/PCF-DWG-001.svg`, `.pdf`, `.png`: turbine unit general arrangement, Rev P1, scale 1:10, with main dimensions and a parts list; marked "CONCEPT, NOT FOR FABRICATION" and "PRELIMINARY, NOT FOR FABRICATION". The concept sheet keeps PCF-DWG-010, so DWG-001 was the next free number.
- `bom/bom.csv` and `bom/bom-notes.md`: every line priced with a supplier or supplier type; kit $448.00 against $450.
- `cad/src/concept_media.py`: now builds the turbine from `model.py` and reads the flow values and key figures from `results.json`; the weir is set for exactly 2.0 m of gross head. All media in `media/` refreshed and checked by eye; no `_views` folders left.
- `docs/01-problem.md`, `docs/02-concept.md`, `docs/03-requirements.md` moved to v0.3; `project.yaml` (`trl: 3`, `trl_target: 3`, `budget_usd: 450`, evidence list) and `README.md` updated. PDFs rebuilt in `docs/pdf/`.

### Requirements at TRL 3 (PCF-CAL-001)

17 requirements: 8 met, 4 not met, 2 at risk, 3 not verifiable at TRL 3.

| Status | Requirements |
| --- | --- |
| **Not met** | **R2** flow range at 1.0 m (10.5 L/s maximum, not 15); **R3** 77.2 W against 80 W; **R4** 23.9 W against 30 W at 1.0 m; **R5** 39.5 % against 40 % |
| At risk | R12 printed runner life (bearings fine, about 1.1 x 10^7 h); R15 $448.00 against $450, $2 margin |
| Not verifiable at TRL 3 | R7 controller behavior; R11 service times; R16 stream protection |
| Met | R1, R6 (1.85 kWh, thin), R8 (clamp holds 48 V; generator overspeed to confirm), R9 (about 21 h print), R10, R13 (280 mm), R14 (22.2 kg), R17 (34.7 kPa) |

Key numbers: pipe and branch losses 23.6 % of head (TRL 2 assumed 10 %); two 34 mm jets; 311 rpm and 3.23 N·m; 82.1 W rectified at 27.1 V; 77.2 W into the battery; 146.4 W at 3.0 m; runaway 764 rpm and 76.4 V open circuit at 3.0 m, clamped to 37 to 48 V by an 8.2 Ω, 300 W resistor; surge 0.59 m with a 10 s closure versus 44 m for an instant stop.

The main design changes at TRL 3, all within sizing scope: branches 63 to 90 mm, jets moved to opposite sides, frame legs cut to 80 mm (nozzles 440 to 280 mm above tailwater), quarter-turn valve replaced by a multi-turn gate valve, independent voltage clamp added, coupling guard added.

### Decisions recorded (PCF-DDR-001)

D1 budget $450 with the salvaged-motor variant documented; D2 new low-speed BLDC; D3 open-design controller as the TRL 3 design, off-the-shelf unit for first bench tests only; D4 12 V; D5 PETG prototype, glass-filled nylon for field units; D6 vertical shaft; D7 two jets; D8 drainage pipe with a slow-closing valve and surge check; D9 problem wording kept; D10 Turgo. All: "Decided by Amish, 2026-09-25: go with recommendation."

### Still awaiting Amish

N1 to N5 below were decided later on 2026-09-25 (PCF-DDR-002); only O1 remains open.

- **O1.** First site type, region and co-design partner, including confirmation that target sites carry about 5 to 15 L/s (Turgo range). No recommendation; partners are picked per area later.
- **N1.** Design-point penstock 125 mm instead of 110 mm for a 20 m run: 84.3 W and 43.0 %, meeting R3 and R5; costs more but sits outside the kit budget. Recommendation: 125 mm. Decided by Amish, 2026-09-25: go with recommendation (PCF-DDR-002).
- **N2.** R4: relax to 20 W at 1.0 m and 7 L/s, or keep 30 W as not met. Recommendation: relax to 20 W. Decided by Amish, 2026-09-25: go with recommendation (PCF-DDR-002).
- **N3.** R2: state the flow range as 5 to 10 L/s at 1.0 m and 5 to 15 L/s from 2.0 m. Recommendation: yes. Decided by Amish, 2026-09-25: go with recommendation (PCF-DDR-002).
- **N4.** R14: confirm "turbine unit" means items 1 to 6 and 11 (22.2 kg). Counting the manifold and valve gives 27.4 kg, which fails 25 kg. Recommendation: confirm. Decided by Amish, 2026-09-25: go with recommendation (PCF-DDR-002).
- **N5.** R15: accept the $2 margin or trim cost. Recommendation: accept, and firm prices with quotes before any build. Decided by Amish, 2026-09-25: go with recommendation (PCF-DDR-002).

### Safety concerns

- Drowning and flood risk at weirs and streams; the runner sits only 210 mm above normal tailwater, so flood levels must be checked at siting.
- Double-fault runaway (load and clamp) reaches about 76 V DC at 3 m; keep the DC side enclosed and rated for 100 V; confirm the generator's overspeed rating.
- Water hammer: a quarter-turn valve or a suddenly plugged nozzle could add 22 to 44 m of head to drainage pipe rated (assumed) for 50 kPa. Only the multi-turn gate valve is allowed; keep the screen clear. The 50 kPa rating is an assumption to confirm with the supplier.
- Dump load and clamp resistor surfaces above 200 °C; fire risk.
- Coupling guard added; still close the valve and wait for the runner to stop before service.
- LiFePO4 battery short-circuit current; fuse at the terminal and a BMS.

### Other notes

- No TRL 4 material exists in the repo (`build-log/` holds only its README, and `electronics/` and `firmware/` are empty). The TRL change was not written to the build log because build-log entries are TRL 4 evidence and are on hold.
- Citations: the TRL 2 review did not flag any unchecked citations, and no new external sources were added at TRL 3. The pipe joint rating (50 kPa) and generator constants are stated as assumptions, not sourced facts.
- The exploded view labels sit over the small coupling (item 4), which is hard to see; acceptable for concept media.

### Recommended next step

TRL 4 is on hold by Amish's instruction. The next step is for Amish to decide N1 to N5 and O1; if N1 to N3 are accepted, a short document update (PCF-REQ-001 and PCF-PRC-001) closes R2, R3 and R5 on paper, still at TRL 3.

For reference only, TRL 4 would need: a chosen generator with measured constants and overspeed rating; a printed runner and nozzles; a lab rig with a head tank or pump giving 1 to 3 m and 5 to 15 L/s; controller and clamp hardware; a lab test report (TST, `environment: lab`) covering output, efficiency, clamp response and runaway; and build log entries. None of this has been started.

## Session 2026-09-25: recommendations accepted

Amish wrote on 2026-09-25, in chat: "i accept all your recommendations, go with them across all repos." Every item with a recommendation is now "Decided by Amish, 2026-09-25: go with recommendation" and recorded in `docs/decisions/0002-recommendations-accepted.md` (PCF-DDR-002 v0.1). TRL stays at 3.

### Decisions applied and what changed

| Item | Decision | Before | After |
| --- | --- | --- | --- |
| N1 | 125 mm design-point penstock | 110 mm; loss 23.6 %; 77.2 W; 39.5 %; 1.85 kWh/day; 34 mm inserts | 125 mm SN8; loss 17.0 %; 82.8 W; 43.2 %; 1.99 kWh/day; 33 mm inserts |
| N2 | R4 relaxed | 30 W target; 23.9 W, not met | 20 W target; 26.3 W, met |
| N3 | R2 stated per head | 5 to 15 L/s at every head; not met at 1.0 m | 5 to 10 L/s at 1.0 m, 5 to 15 L/s from 2.0 m; met (1.3 to 11.3 and 1.9 to 16.1 L/s) |
| N4 | R14 definition confirmed | Met, definition to confirm | Met, items 1 to 6 and 11 (22.2 kg) |
| N5 | $2 cost margin accepted | R15 at risk | R15 met; quotes before any build (TRL 4, on hold) |

Side effects of N1, from PCF-CAL-001 v0.2: runaway at 3.0 m 764 to 795 rpm and 76.4 to 79.5 V open circuit; worst-case clamped bus 37.2 to 39.6 V (still under the 40 V release, margin now 0.4 V); dump-load margin 1.90 to 1.68 times; bearing L10 1.1 x 10^7 to 8.7 x 10^6 h; surge peak 34.7 to 33.3 kPa; penstock cost (excluded) $100 to $140. Kit cost unchanged at $448.00 against `budget_usd: 450` (no budget change).

Files changed: `docs/03-requirements.md` (PCF-REQ-001 v0.4), `docs/04-calcs/01-sizing.md` (PCF-CAL-001 v0.2) and `sizing.py`, `results.json`, `docs/02-concept.md` (PCF-PRC-001 v0.4), `docs/01-problem.md` (PCF-PRB-001 v0.4), `docs/decisions/0001-trl2-review-decisions.md` (PCF-DDR-001 v0.2), new PCF-DDR-002, `cad/src/model.py` (`penstock_od` 125, `jet_d` 33) with STEP and STL re-exported, `cad/src/sheets.py` (PCF-DWG-001 Rev P1 to P2), `cad/src/concept_media.py` labels, `bom/bom.csv`, `bom/bom-notes.md`, `README.md`, `project.yaml` (evidence list only). All media, drawings and PDFs regenerated with designmolecule.com in the footers.

README: the four write-up sections (Concept rationale, Burning platform, Where it could be used, What sparked the idea) were added before "## Problem". The inspiration point is Eric Crewdson's Turgo patent (applied 1919, granted 1920), cited to Hydropower & Dams International.

### Requirement status (PCF-CAL-001 v0.2)

17 requirements: 0 not met, 1 at risk, 3 not verifiable at TRL 3, 13 met.

| Status | Requirements |
| --- | --- |
| Not met | None |
| At risk | R12 printed runner life (bearings fine) |
| Not verifiable at TRL 3 | R7 controller behavior; R11 service times; R16 stream protection |
| Met | R1, R2, R3 (82.8 W, 2.8 W margin), R4 (26.3 W), R5 (43.2 %), R6, R8, R9, R10, R13, R14, R15 ($2 margin accepted), R17 |

### Still awaiting Amish

- **O1.** First site type, region and co-design partner (no recommendation).
- **N6 (new).** Inlet valve bore: the BOM's 90 mm gate valve on the 125 mm penstock needs a reducer and expander that the calculation does not yet include and that could erode the 2.8 W margin on R3. Recommendation: add the reducer losses to PCF-CAL-001 first; move to a full-bore valve only if R3 then fails.

### Cross-repo actions

None. No PicoFlow recommendation depends on another repo.

### Safety

No safety requirement changed status. The double-fault open-circuit voltage rises to about 80 V DC at 3.0 m, still inside the enclosed 100 V DC side. The clamp margin below its 40 V release is now 0.4 V in the worst case; a 6.8 Ω clamp resistor is noted in PCF-CAL-001 as the option if measured generator constants are less favorable.

### TRL 4

TRL 4 remains on hold by Amish's instruction. Firming prices with quotes (N5), measuring runner efficiency and generator constants, and any build or test were not started.

## Session 2026-09-26: sources strengthened

Amish asked on 2026-09-26 to fix the weaker sources in the README. Changes (README only; no controlled document changed):

- What sparked the idea: the trade-press source (Hydropower & Dams International) was replaced by Gilkes' own history, "100 Years of the Turgo Impulse Turbine", which gives the 1919 application, the 1920 grant to Eric Crewdson, twice Pelton speed at the same head and the side-entry jet. Crewdson is now described as a trainee at Gilkes, as the source says, rather than naming the later company title. The Bristol paper (Williamson, Stark and Booker, Applied Energy 102, 2013) was rechecked and its test range (3.5 m down to 1 m, 87 % at 1 m) is now stated. INSPIRATIONS.md line updated to the new source.
- By country or region: "Andean South America (Peru, Bolivia)" had no source and was replaced by a Peru row citing the World Bank's 2019 results note on rural electrification (11,915 solar home systems in isolated areas; studies for 21 small hydropower projects).
- Burning platform: the Vietnam figure now follows the DFID R8150 wording ("doubtful whether there are more than 30,000" still running).
- Kept and rechecked: World Bank Tracking SDG 7 2025 (666 million, 85 %), DFID R8150, AEPC. The PowerSpout page (the maker's own) was kept but could not be refetched in this session.

## Session 2026-09-26: product appearance model and photoreal renders

Amish chose PicoFlow on 2026-09-26 for the first batch of product renders. This session added an appearance model for photoreal renders; no controlled document, the BOM or `cad/src/model.py` changed.

### What was added

- `cad/src/product_model.py`: `product_parts()` (47 parts: 33 shell, 5 internal, 5 accessory and 4 context, including the clear window, guard and tailwater), `TITLE` and three `RENDER_VIEWS` (hero, exploded, detail). All main dimensions and interfaces come from `PARAMS`, `_derived()` and `build_parts()` in `model.py`.
- Finished-product detail: filleted HDPE lid with corner bolts; aluminium bearing housing with bearing-seat rings, a filleted flange, cap screws and a grease nipple; stainless posts with nuts under a filleted generator plate; a two-hub jaw coupling with an orange elastomer spider; a finned BLDC generator with end caps, a rating label, a cable gland and lead; the tee, 90 mm branches, elbows and socket couplers; printed nozzles with separate 33 mm metal inserts; a gate valve with bonnet and handwheel; the frame drawn as galvanized angle on foot plates with anchor bolts.
- Context (group "context"): the model.py penstock stub on a pipe saddle, the concrete edges of the tailrace channel under the frame and the tailwater surface.
- README hero image now points to `media/render-hero.png`, with a link to `media/render-exploded.png`. The render files are produced separately.

### Differences from model.py (each Proposed, awaiting Amish)

1. **Housing split into two halves.** The model has one 315 mm pipe section. The appearance model splits it on the Y = 0 plane into front and back halves joined by bolted vertical seam flanges, so the exploded view can show the runner. Recommendation: keep the one-piece pipe for the kit (cheaper, no seam to seal); adopt the split only if runner inspection without lifting the lid is wanted.
2. **Clear inspection window.** A bolted polycarbonate window (about 180 x 200 mm) in the front of the housing shows the runner. It is not in the model or the BOM. Recommendation: adopt it as an optional part; it helps fault finding and teaching, adds a few dollars and needs a guard against impact from debris.
3. **Clear coupling guard.** The BOM gives a 110 mm coupling guard without a material; the renders show clear polycarbonate. Recommendation: accept, since a clear guard lets the owner check the spider without removing it.
4. **Nozzle entry holes in the housing.** The massing model lets the nozzles overlap the housing wall; the appearance model cuts clearance holes. Recommendation: accept; the holes are implied by the design.
5. **Rectifier box position.** The rectifier (BOM 13) is not in model.py and is installed on the equipment post; the exploded view shows it loose beside the unit. Recommendation: accept as a render layout only.
6. **Tailwater drawn 20 mm below the channel edge.** In model.py Z = 0 is both normal tailwater and the top of the pad under the frame. The render draws the water surface 20 mm lower so it reads as a surface. Recommendation: accept as an appearance choice; the setting height (R13) is unchanged.

### Status

This is an appearance model only: no tolerances, fabrication detail or TRL 4 work. `trl` stays 3 in `project.yaml`, and TRL 4 remains on hold by Amish's instruction.

## Session 2026-09-27: kit 1.5.0 and image quality

- Kit 1.5.0 synced: STANDARDS v1.5 (sections 12 to 15: product renders, storefront images and image quality, public release, authorship and signing), `.kit/cards.py`, `.kit/image_qc.py`, `.kit/release_gate.py`, issue templates, and the `/render-product` and `/release` commands. `CLAUDE.md` now matches `.kit/CLAUDE.md`.
- Every `media/render-*.png` recaptioned from its original render with the new layout: the title, concept label and repository sit in a band above the render and the view note in a band below it, each line wrapped to the image width, so no text overlaps other text or the render or runs off the image. `media/card.png` and `media/social-preview.png` regenerated with the same rules.
- `python .kit/image_qc.py` and `python .kit/release_gate.py` pass. trl stays 3.

## Session 2026-10-01: kit 1.7.0, design for construction and the prototype build plan

Amish approved the build plan format on 2026-09-30 and asked for it across all repos, with outstanding decisions kept in a separate register. This session installed kit 1.7.0, made the PicoFlow design constructable and wrote the illustrated build plan. Nothing was built; TRL stays 3.

### What was done

- Kit 1.7.0 installed (`.kit/`, `.claude/commands/`); `CLAUDE.md` now matches `.kit/CLAUDE.md`.
- `cad/src/model.py` rewritten as separate components (frame, tie rods, housing, nozzles, gaskets, inserts, lid, bearing units, sleeves, V-ring, shaft, hub, runner, guard, posts, plate, coupling, generator, pipework, valve and fittings, stands, forebay, equipment post, electrics and every fixing) with 69 constructability checks (`python cad/src/model.py --check`, all pass) and a clean all-pairs overlap scan. STEP and STL re-exported, including the nozzle, insert pair and saddle gaskets for printing and cutting.
- `docs/decisions/0003-design-for-construction.md` (PCF-DDR-003 v0.1, Draft): every change, made under Amish's 2026-09-30 instruction to make the design physically buildable; open for his review.
- `docs/05-build-plan.md` (PCF-BLD-001 v0.1) and `cad/src/build_plan_media.py`: overview, 14 making sketches (PCF-DWG-101 to 114), 12 joint close-ups, 19 step pictures, a lid hole layout, a full-size nozzle hole template (PNG and PDF) and a block wiring diagram.
- `docs/06-design-decisions.md` (PCF-DEC-001 v0.1): open decisions, items to confirm when parts are bought, value engineering and decisions made.
- `docs/04-calcs/sizing.py` and PCF-CAL-001 v0.3, PCF-REQ-001 v0.5, PCF-PRC-001 v0.5, `bom/bom.csv` (lines 2, 3, 7, 8, 10, 11, 12 respecified; lines 18 and 19 added), `bom/bom-notes.md`, PCF-DWG-001 Rev P3, concept media regenerated, `project.yaml` (`design_state: constructable`, evidence), README (links line and "Building the prototype").

### Design changes made for construction (PCF-DDR-003)

| # | Change |
| --- | --- |
| P1 | Frame: a 380 mm welded square of 40 x 40 x 4 mm angle (was a 420 mm massing frame the housing did not rest on), with legs, foot plates, anchors and pipe stops |
| P2 | Four M10 tie rods clamp lid, housing and frame; a groove under the lid locates the housing (housing cut to 303 mm) |
| P3 | Two UCF204-class flange bearing units on spacer sleeves, bolted through the lid, and a V-ring seal, in place of an unmachinable bearing housing |
| P4 | Runner fixed by a bought clamping hub and four M5 screws into heat-set inserts |
| P5 | Printed nozzles with a horizontal spigot, a 20 degree bend and a gasketed saddle bolted to the housing; wall holes cut from a template; flexible couplings to the pipe |
| P6 | Nozzle exit moved from 85 to 115 mm before the strike point and the runner lowered 11 mm, so the runner lifts out past the nozzle tips; nozzle height unchanged at 280 mm |
| P7 | Generator sits on its plate, four M6 screws (was floating 5 mm above it) |
| P8 | Posts are 20 x 2 mm tubes on M10 rods, moved to 125 mm so the washers clear the housing |
| P9 | Guard is a 160 mm PVC pipe in a groove on the lid, covering both bearings and the coupling |
| P10 | Penstock on the jet 2 line into the run of a 125 x 90 reducing tee; standard fittings with socket depths allowed for; jet 1's far corner moved from 330 to 460 mm |
| P11 | Reducer, expander and nipples join the 90 mm valve into the 125 mm line; their loss is now in the calculation |
| P12 | Three pipe stands (new BOM line 18) |
| P13 | Forebay tank connector and screen frame |
| P14 | Fixings listed (new BOM line 19); generator plate 8 mm, foot plates 5 mm and post tube 20 x 2 mm to keep R14 |

### Key results (PCF-CAL-001 v0.3)

- Design point: 82.5 W into the battery with the 34 mm inserts (was 33 mm), 81.7 W at exactly 10 L/s, 41.4 % water to wire, 1.98 kWh a day. Pipe, valve and branch loss 20.3 % of head (17.0 % in v0.2, which took the valve as full bore). **The margin on R3 is now 1.7 W.**
- Clamped bus 38.7 V at most (R8); surge peak 33.4 kPa (R17); bearing L10 8.0 x 10^6 h; turbine unit 24.5 kg with fixings (R14, 0.5 kg margin).
- Requirements: none not met, R12 at risk, R7, R11, R16 not verifiable at TRL 3, 12 met, and R15 reported against its value-engineering target: USD 534, USD 84 over the USD 450 target (USD 464 with a salvaged motor).

### Proposed, awaiting Amish

All listed in `docs/06-design-decisions.md`: accept PCF-DDR-003 (recommended); inlet valve bore N6, now quantified (full bore gives 85.6 W; recommended); welded frame (recommended); O1 site and partner; and the four appearance items from the 2026-09-26 render session (split housing, inspection window, clear guard, render layout).

### Safety

No safety requirement changed status. The build plan carries safety stops S1 to S7 (stream work, lid and plate closure, wiring, first water, opening for service). The clamp margin below its 40 V release is now 1.3 V in the worst case.

### Stale outputs

The design changed visibly (frame, bearings, guard, nozzles, pipework). The photoreal renders `media/render-*.png`, `media/card.png`, `media/social-preview.png` and the appearance model `cad/src/product_model.py` still show the concept and need regenerating on Amish's Mac. The `render-*.png` files are not in this cloud copy, so the README hero and render links point at files made there.

### Recommended next step

Amish reviews PCF-DDR-003 and decides the open items in PCF-DEC-001, starting with the valve bore. Then refresh the product renders on the Mac. TRL 4 (building and testing to this plan) stays on hold.

## Session 2026-10-01: inlet valve bore decided (full bore)

Amish decided open decision 2 of the design decisions register (inlet valve bore, N6) on 2026-10-01. He was told the R3 output margin had dropped to 1.7 W and that the recommendation was a full-bore inlet valve, and replied: "picoflow - i agree with the recommendation". Option (a) is now the design: a full-bore valve matched to the 125 mm penstock, re-priced. Only this item is decided; acceptance of PCF-DDR-003 (A1), the welded frame and the other open items stay open. Nothing was built; TRL stays 3.

### What was done

- `cad/src/model.py`: the 90 mm gate valve, reducer, expander and nipples are replaced by a full-bore 125 mm PVC-U gate valve with solvent-weld sockets for 125 mm pipe (assumed type, catalogue class, to confirm: PN10, multi-turn handwheel with a non-rising stem, 330 mm over the sockets, 70 mm deep sockets, 200 mm handwheel about 300 mm above the pipe centre line, about 5.5 kg). It sits 60 mm clear of the tee, joined to it by a 175 mm piece of the penstock pipe; the penstock goes straight into its upstream socket. Five checks added (pipe piece in the tee and the valve, penstock in the valve, valve clear of the tee and of the pad): 74 of 74 pass. STEP and STL re-exported. The five 90 mm branch cut lengths are unchanged; the new cut length is the 175 mm pipe piece.
- `docs/04-calcs/sizing.py` and PCF-CAL-001 v0.4: valve loss coefficient 0.15 on the penstock velocity head (the v0.3 90 mm arrangement is kept as a printed comparison); the design insert is now read from the model (34 mm) rather than rounded from the exact bore, which with the full-bore valve is 33.3 mm; the clamp check now uses the 8.2 Ω resistor in the BOM and also reports the largest E12 value that keeps the clamp cycling. Every number rerun.
- `bom/bom.csv` line 8 and `bom/bom-notes.md`: re-priced with a stated basis (below).
- PCF-REQ-001 v0.6, PCF-PRC-001 v0.6 (`docs/02-concept.md`) and `README.md`: figures updated.
- PCF-BLD-001 v0.2 (`docs/05-build-plan.md`): change table row, section 3.14 rewritten as "Inlet valve and its pipe piece" with a new joint picture (Figure 28, `joint-13.png`; later figures renumbered), the bought-parts list, step 17, pipework dry fit wording, cost line and "Where the numbers come from".
- Pictures regenerated with `cad/src/build_plan_media.py`: `docs/05-build-plan/overview.png`, `step-17.png`, new `joint-13.png`, and `cad/drawings/PCF-DWG-112` (the pipework sketch shows the valve and its note now names the pipe piece). The script gained `STEPS` and `JOINTS` filters, like the existing `SHEETS`, so one picture can be redrawn. No other joint or step picture shows the valve.
- PCF-DWG-001 moved to Rev P4 (parts list item 8: "Inlet gate valve, 125 mm full bore"). Concept media regenerated (`media/hero.png`, `concept-blueprint`, `cutaway.png`, `exploded.png`, `flow.png`, `model.glb`).
- PCF-DEC-001 v0.2: item 2 moved to Decisions made (2026-10-01, Amish's words, record PCF-DDR-003 A2); open items renumbered 1 to 7; a new proposed item 8 (clamp resistor, below); item 6 to confirm now covers the full-bore valve; Value engineering updated. PCF-DDR-003 v0.2 records that Amish accepted A2 (a) on 2026-10-01; A1 and A3 stay open.

### Key results (PCF-CAL-001 v0.4)

- Valve loss 0.007 m at the design point (0.081 m with the 90 mm valve and its fittings).
- **R3: 85.6 W into the battery at exactly 10 L/s, a 5.6 W margin (was 81.7 W and 1.7 W).** With the 34 mm design inserts: 87.8 W at 10.36 L/s. Water to wire 43.6 % at 10 L/s (43.2 % with the inserts); 2.05 kWh a day at 10 L/s. Pipe, valve and branch loss 16.3 % at 10 L/s.
- R4 26.8 W; surge peak 33.5 kPa (R17); bearing L10 7.1 x 10^6 h; dump load margin 1.64 times (R7).
- Mass (R14): turbine unit unchanged at 24.5 kg. The pipework carried separately is now 9.8 kg (was 6.3 kg), of which the valve is about 5.5 kg, well under the 15 kg heaviest-item limit; all items together 34.3 kg.
- Cost (R15): Value-engineering target: USD 450. Estimated cost of the constructable design: USD 614 (USD 164 over the target). USD 544 with a salvaged motor (USD 94 over).
- Price basis for line 8 (USD 120, was USD 40): an estimate, not a quote. Full-bore PVC-U gate valves with socket ends are made up to DN300 (for example Petron Thermoplast, PN10, handwheel), but no published price was found for the 125 mm size; US-made 4 in PVC gate valves list at over USD 1,000 (Spears 2022-040, USD 1,700.91 at pvcfittingsonline.com, read 2026-10-01). USD 115 is assumed for an imported metric valve plus USD 5 for the pipe piece and cement. The line must be quoted; it is now the largest line in the kit.
- Requirements: none not met, R12 at risk, R7, R11 and R16 not verifiable at TRL 3, 12 met, R15 USD 164 over its value-engineering target.

### Proposed, awaiting Amish

- **New, register item 8: clamp resistor.** The full-bore valve delivers more power at the worst-case site (3.0 m, 15 L/s: 247 W at the shaft). With the 8.2 Ω clamp resistor the bus now settles at 40.1 V, 0.1 V above the clamp's 40 V release point, so in that case the clamp stays switched in instead of cycling. The bus still never exceeds 48 V, so R8 is met. Options: (a) keep 8.2 Ω, 300 W; (b) 6.8 Ω, which settles at 36.7 V but needs a 350 W or larger rating (339 W at 48 V). Recommendation (b). Not changed in the BOM or the wiring picture until Amish decides.
- Unchanged: accept PCF-DDR-003 (A1), welded frame, site and partner, and the appearance items.

### Safety

No safety requirement changed status. The valve is still multi-turn (never quarter-turn), so R17 holds at 33.5 kPa; the build plan's safety stops are unchanged. The clamp's margin below its release point is gone in the worst case (see item 8 above); the 48 V ceiling and the 100 V enclosure are unaffected.

### Found, not changed

- `bom/bom.csv` line 7 still says "a pair of printed 33 mm inserts", while the model, the calculation and the build plan use 34 mm. Worth correcting with the next BOM edit.

### Stale outputs

The valve is visible in all three photoreal renders: `media/render-hero.png` (penstock and gate valve from the back left), `media/render-exploded.png` (gate valve listed) and `media/render-detail.png` may show it at the left edge. They, `media/card.png` and `media/social-preview.png` still show the earlier valve and need regenerating on Amish's Mac; `cad/src/product_model.py` draws its own gate valve and still sizes it as before (it reads only the valve position from the model).

### Recommended next step

Amish decides register item 8 (clamp resistor) and the other open items, starting with acceptance of PCF-DDR-003. A real quote for the 125 mm gate valve would firm up the cost. Then refresh the product renders on the Mac. TRL 4 stays on hold.

## Session 2026-10-01: clamp resistor decided (6.8 Ω, 350 W)

Amish, 2026-10-01: "I approve of your recommendations for PicoFlow and GravitySort". For PicoFlow this answers open item 8 of the design decisions register (PCF-DEC-001 v0.2), the clamp resistor, whose recommendation was option (b). Only this item is decided; acceptance of PCF-DDR-003 (A1), the welded frame and the other open items stay open. Nothing was built; trl stays 3.

### Accepted, as recommended

| Register item (v0.2) | Decision |
| --- | --- |
| 8 | Clamp resistor: a 6.8 Ω aluminium-clad resistor rated 350 W or more replaces the 8.2 Ω, 300 W one, so the clamp keeps a margin below its 40 V release point in the worst case |

### What changed

- `docs/06-design-decisions.md` (PCF-DEC-001 v0.3): item 8 moved to Decisions made, dated 2026-10-01, with Amish's words and the record (PCF-CAL-001 v0.5, section 6); it was the last open item, so items 1 to 7 keep their numbers. Value engineering updated: USD 618 (USD 168 over the target), USD 548 with a salvaged motor (USD 98 over), and the line 15 change named.
- `docs/04-calcs/sizing.py`: clamp resistor 6.8 Ω (was 8.2 Ω) and its 350 W rating added, with the rating and the release margin printed; rerun, `docs/04-calcs/results.json` rewritten. PCF-CAL-001 v0.5 (`docs/04-calcs/01-sizing.md`): summary, R8 and R15 rows, section 6 (clamp) and section 11 (cost) rewritten; a note under the history table says what v0.5 changed.
- `bom/bom.csv` line 15: 6.8 ohm, 350 W (or higher rated) aluminium-clad clamp resistor; re-priced from USD 28 to USD 32 (+USD 4, indicative, to be quoted). `bom/bom-notes.md`: totals and a paragraph on the change.
- `docs/05-build-plan.md` (PCF-BLD-001 v0.3): the voltage clamp and resistor rows of section 3.16, wiring item 3 and the parts cost (USD 618); "Where the numbers come from" points at PCF-CAL-001 v0.5 and PCF-REQ-001 v0.7.
- `docs/05-build-plan/wiring.png` (Figure 31) regenerated with `cad/src/build_plan_media.py wiring`: the resistor guard now reads "6.8 ohm 350 W clamp (DC bus)" and the clamp wire "to the 6.8 ohm clamp resistor". Checked by eye: labels readable, nothing overlapping.
- `docs/02-concept.md` (PCF-PRC-001 v0.7): controller description, component table line 15, runaway paragraph, cost table and the heat safety note (350 W clamp resistor).
- `docs/03-requirements.md` (PCF-REQ-001 v0.7): R8 and R15 status and notes.
- `README.md`: parts list and kit cost.
- Concept media regenerated (`media/concept-blueprint.*` carries the kit cost; `hero.png`, `cutaway.png`, `exploded.png`, `flow.png`, `model.glb`); no geometry changed.
- PDFs regenerated with `python3 .kit/render.py`.

### Consistency fix

`bom/bom.csv` line 7 said "a pair of printed 33 mm inserts" and "two 33 mm inserts at the design point", while the model, PCF-CAL-001 and the build plan use 34 mm (flagged under "Found, not changed" in the previous session). Both now say 34 mm. No price change.

### Key results (PCF-CAL-001 v0.5)

| Quantity | 8.2 Ω, 300 W (v0.4) | 6.8 Ω, 350 W (v0.5) |
| --- | --- | --- |
| Worst-case clamped bus (3.0 m, 15 L/s) | 40.1 V, 0.1 V above the 40 V release | 36.7 V, 3.3 V below the release |
| Clamped runner speed | 456 rpm | 426 rpm |
| Dissipation at equilibrium | 196 W | 198 W |
| Dissipation at the 48 V switch-on point | 281 W (300 W rating) | 339 W (350 W rating, 3 % margin) |
| Kit cost, new generator | USD 614 (USD 164 over the USD 450 target) | USD 618 (USD 168 over) |
| Kit cost, salvaged motor | USD 544 (USD 94 over) | USD 548 (USD 98 over) |

6.8 Ω is the largest E12 value that keeps the worst-case equilibrium below the release point. R8 stays met by calculation; no requirement changed status: none not met, R12 at risk, R7, R11 and R16 not verifiable at TRL 3, 12 met, R15 reported against its value-engineering target.

### Still open (PCF-DEC-001)

1. Accept the design-for-construction changes (PCF-DDR-003, A1).
2. Frame welded or bolted (A3).
3. First site type, region and co-design partner.
4. Split housing for runner inspection.
5. Clear inspection window in the housing.
6. Guard material.
7. Render layout choices.

### Safety

The clamp now cycles as designed in the worst case instead of staying switched in. The resistor runs close to its rating for the moment after switch-on (339 W in a 350 W part), so it must sit on its heat sink inside the vented guard; a 500 W part would give more margin if 350 W aluminium-clad resistors are not stocked. The 48 V ceiling, the 100 V enclosure and the double-fault case (about 80 V) are unchanged.

### Found, not changed

`cad/src/product_model.py` still names the nozzle insert "33 mm" in its part list; it affects only the photoreal render labels and is left for the next render refresh on the Mac.

### Recommended next step

Amish decides the remaining open items, starting with acceptance of PCF-DDR-003 (A1). Quotes for the 125 mm gate valve and the 6.8 Ω, 350 W clamp resistor would firm up the cost. Then refresh the product renders on the Mac. TRL 4 stays on hold.

## Session 2026-10-02: open decisions decided

On 2026-10-02 Amish approved the recommendations for every open decision: "i approve your recommendations for all 555 open decisions." The 7 open decisions of the design decisions register are now in its Decisions made table, dated 2026-10-02.

PCF-DDR-003 (design for construction) is accepted (A1 and A3; A2 was accepted on 2026-10-01). Safety rules carried into the build plan: frame and pipe stands welded from bare steel and galvanized or painted afterwards, never welded after galvanizing; no window in the housing; a clear guard only in polycarbonate, never acrylic. The value engineering note now says the construction additions still in the estimate are USD 78 (review flag 2).

### Documents changed

- `docs/06-design-decisions.md` (PCF-DEC-001 v0.4)
- `docs/decisions/0003-design-for-construction.md` (PCF-DDR-003 v0.3)
- `docs/01-problem.md` (PCF-PRB-001 v0.5)
- `docs/02-concept.md` (PCF-PRC-001 v0.8)
- `docs/05-build-plan.md` (PCF-BLD-001 v0.4)
- `bom/bom-notes.md` (not a controlled document)

### Follow-up actions to carry approved decisions into the design

1. Decision 2: BOM: change the descriptions of lines 11 (frame) and 18 (pipe stands) from galvanized angle to bare steel angle, hot-dip galvanized or painted after welding, and add the galvanizing or paint cost if the fabricator quotes it separately.
2. Decision 2: Drawings: change the material notes on making sketches PCF-DWG-101 (frame) and PCF-DWG-111 (pipe stand) to bare steel, galvanized or painted after welding.
3. Decision 1: Renders: regenerate the photoreal renders, `media/card.png`, `media/social-preview.png` and the appearance model on Amish's Mac to show the accepted constructable design, without the housing window and split housing, with a PVC (or polycarbonate) guard (items 4 to 7 follow with them).
4. Decision 1: Value engineering: get real quotes for the full-bore 125 mm valve before anything else (review flag 1).

### Points found in the review

1. The 2026-10-01 full-bore valve decision rests on an estimated USD 120 with no published price (about USD 21 per watt recovered); a real quote should be the first value-engineering step, and option (b) could be reopened if it comes in high.
2. The Value engineering list still counts USD 8 of valve fittings in the USD 86 added for construction, although they were replaced by the full-bore valve.

No CAD model, BOM quantity or price, calculation result or picture was changed. TRL stays at 3; TRL 4 remains on hold.

## Session 2026-10-02: approved follow-ups carried out

Amish approved every follow-up action of the open-decision sign-off on 2026-10-02 ("APPROVED CHANGES, COMPLETE THESE"). Results for the four follow-ups listed above:

### Approved follow-ups carried out

1. BOM lines 11 and 18: done. Both now say bare steel angle, welded bare and then hot-dip galvanized or painted after welding. The fabricator has not quoted galvanizing or paint separately, so no coating cost was added; a small-batch galvanizing minimum charge could exceed the USD 15 and USD 5 line prices (noted in `bom/bom-notes.md`).
2. Making sketches PCF-DWG-101 and PCF-DWG-111: done. Material notes and the touch-up note now say bare steel, galvanized or painted after welding, never welded after galvanizing. General arrangement PCF-DWG-001 is Rev P5 (frame material note). Text check on all drawings is clean.
3. Appearance model: done. `cad/src/product_model.py` now draws a one-piece housing with no window and no split, and a 160 mm PVC pipe guard (polycarbonate is allowed in the build plan, never acrylic); views hero, exploded and detail kept, with their notes updated. Render scenes exported to `/home/claude/renders/picoflow` (hero, exploded, detail, each .npz and .json, and `picoflow__jobs.json`). The photoreal renders, `media/card.png` and `media/social-preview.png` are for Amish's Mac.
4. Real quotes for the full-bore 125 mm valve: not done. It is outreach to suppliers by Amish; the USD 120 line stays an estimate and is still the first value-engineering step.

Done 3 of 4.

### Key results

- Requirement status: no change. Calculations unchanged (`sizing.py` not affected by these follow-ups).
- Cost: Value-engineering target: USD 450. Estimated cost of the constructable design: USD 618 for the turbine kit with a new generator (USD 168 over the target); USD 548 with a salvaged washing machine motor (USD 98 over the target). `budget_usd` unchanged. Mass unchanged.
- The model and its 74 constructability checks are unchanged and pass. No build plan picture besides the two making sketches changed, because no geometry changed.

### Documents changed (new versions)

PCF-BLD-001 v0.5, PCF-PRC-001 v0.9, PCF-DEC-001 v0.5, PCF-DDR-003 v0.4; `bom/bom.csv`, `bom/bom-notes.md`, `cad/src/build_plan_media.py`, `cad/src/sheets.py`, `cad/src/product_model.py`.

### Cross-repo actions

None found for this repo.

### Recommended next step

Amish gets quotes for the 125 mm full-bore valve, then the photoreal renders are made on the Mac from the exported scenes. TRL 4 stays on hold.

## 2026-10-02: photoreal renders redone on the constructable design

Rendered with Blender Cycles on Amish's Mac from the updated appearance model; captioned with `.kit/photo_caption.py`; `media/card.png` and `media/social-preview.png` regenerated with `.kit/cards.py`. Views: hero, exploded, detail. image_qc passes. Appearance deviations are those logged above as proposed, awaiting Amish.

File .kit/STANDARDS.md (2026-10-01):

---
doc_id: OHP-STD-001
title: Documentation and drawing standard
project: Open Hardware Portfolio
doc_type: Standard
version: "1.7"
status: Released
date: 2026-09-30
author: Amish Chadha
license: CC-BY-SA-4.0
revisions:
  - version: "1.0"
    date: 2026-09-24
    author: Amish Chadha
    change: First release of the standard
  - version: "1.1"
    date: 2026-09-24
    author: Amish Chadha
    change: Adopt Technology Readiness Levels (section 9) for project maturity
  - version: "1.2"
    date: 2026-09-24
    author: Amish Chadha
    change: Portfolio phase cap (section 10), concept media standard (section 11), CLAUDE.md guardrails
  - version: "1.3"
    date: 2026-09-24
    author: Amish Chadha
    change: Scale figure, interactive 3D viewer and flow diagrams added to concept media; session slash commands
  - version: "1.4"
    date: 2026-09-26
    author: Amish Chadha
    change: Every sheet and render names the project and its GitHub repository; overall dimensions, ISO centre lines and 300 dpi PNG on sheets; titles name the device and view labels state the viewing direction; optional photoreal renders with Blender
  - version: "1.5"
    date: 2026-09-27
    author: Amish Chadha
    change: Product renders (section 12), storefront images and image quality check (section 13), public release and release gate (section 14), authorship, citation and commit signing (section 15)
  - version: "1.6"
    date: 2026-09-29
    author: Amish Chadha
    change: Licensing metadata with REUSE (section 16), Zenodo DOI and Software Heritage archiving (section 17), release gate checks REUSE and a single CITATION.cff license, archive.py
  - version: "1.7"
    date: 2026-09-30
    author: Amish Chadha
    change: Concept and constructable design states; design decisions register (DEC) kept apart from the build plan; prototype build plan (BLD, section 18) with pictures by component is required TRL 3 evidence; every repo targets TRL 3 during the populate phase; build_views.py; /to-trl3 and /build-plan commands
---

# Documentation and drawing standard

Every project in the portfolio uses this standard, so that each precis, write-up and sketch looks the same and carries its own version history. The standard ships as a kit in each repo's `.kit/` folder. The kit version is in `.kit/KIT_VERSION`.

## 1. Document types and IDs

Every controlled document has a unique ID in the form `PRJ-TYP-NNN`.

- `PRJ` is the three-letter project code listed in section 7.
- `TYP` is the document type code from the table below.
- `NNN` is a sequence number within that project and type, starting at 001.

| Code | Type | Typical file |
| --- | --- | --- |
| PRC | Design precis | `docs/02-concept.md` |
| PRB | Problem statement | `docs/01-problem.md` |
| REQ | Requirements | `docs/03-requirements.md` |
| CAL | Calculation or sizing note | `docs/04-calcs/*.md` |
| DDR | Design decision record | `docs/decisions/*.md` |
| BOM | Bill of materials | `bom/bom.csv` |
| DWG | Drawing or sketch sheet | `cad/drawings/*.svg` |
| BLD | Prototype build plan (section 18) | `docs/05-build-plan.md` |
| DEC | Design decisions register (section 18) | `docs/06-design-decisions.md` |
| TST | Test plan or test report (front matter adds `environment: lab` or `relevant`) | `docs/05-tests/*.md` |

Example: `TBK-PRC-001` is the ThermaBrick design precis.

## 2. Revision scheme

| Artifact | While in draft | When released | Change after release |
| --- | --- | --- | --- |
| Documents | 0.1, 0.2, 0.3 ... | 1.0 | 1.1 for minor edits, 2.0 for a design change |
| Drawings | Rev P1, P2 ... (preliminary) | Rev A | Rev B, C ... |

- Every change to a controlled document adds a row to its revision history before the commit.
- The `version` field in front matter always equals the newest row in `revisions`. The renderer rejects a document where they differ.
- Status is one of `Draft`, `In review`, `Released` or `Superseded`. Draft and In review documents print with a status band on every page.
- Every release is tagged in Git as `<doc_id>/v<version>`, for example `TBK-PRC-001/v1.0`. Drawings are tagged `TBK-DWG-001/revA`.
- Git history is the full audit trail. The in-document revision table is the human-readable summary.

## 3. Document front matter

Every Markdown document under version control starts with this block:

```yaml
---
doc_id: TBK-PRC-001
title: ThermaBrick design precis
project: ThermaBrick
doc_type: Precis
version: "0.1"
status: Draft
date: 2026-09-24
author: Amish Chadha
license: CERN-OHL-S-2.0
revisions:
  - version: "0.1"
    date: 2026-09-24
    author: Amish Chadha
    change: Initial draft
---
```

Quote version numbers so YAML keeps `1.0` as text instead of turning it into a number. List revisions newest last.

## 4. Writing style

- Chicago Manual of Style.
- No em dashes. Restructure the sentence instead.
- Lead each section with its conclusion, then support it.
- SI units throughout, in the form `12 kW`, `450 °C`, `3.2 m`. Imperial values may follow in parentheses.
- Number every figure and table ("Figure 2", "Table 1") and give each a caption.
- State every assumption in the calculation that depends on it.
- Put safety notes in a blockquote starting with **Safety:**.

## 5. Visual identity

| Element | Specification |
| --- | --- |
| Typeface | IBM Plex Sans for text, IBM Plex Mono for code and values (SIL Open Font License, bundled in `.kit/fonts`) |
| Ink | `#111827` |
| Secondary text | `#4B5563` |
| Rules and grid | `#D1D5DB` |
| Accent (one only) | `#0F766E` teal |
| Document page | US Letter, 20 mm margins |
| Drawing sheet | ANSI B landscape (431.8 x 279.4 mm) |
| Footer | Document ID, version, status, license and designmolecule.com on every page |

## 6. Drawing and sketch conventions

- Units are millimeters unless the title block says otherwise.
- Third-angle projection, marked with the symbol in the title block.
- Line weights: visible outlines 0.5 mm, hidden lines 0.25 mm dashed, center lines 0.18 mm chain.
- The title block contains the project, title, drawing number, revision, scale, units, projection, sheet, author, date, material or notes, and license.
- Every sheet and every render names the project and its GitHub repository (from `repo:` in `project.yaml`), at the top of the sheet and in the title block, so a printed or forwarded sheet is never anonymous.
- The drawing title names the device, not only the drawing type (for example "Handheld near-infrared resin scanner: general arrangement").
- Every view label states its scale and viewing direction (for example "Scale 1:1; side elevation looking along +Y"), and every isometric or render states where it is seen from.
- Orthographic views generated with `add_ortho` carry overall dimensions (length and depth on the top view, height on the front view) and ISO 128 centre lines on cylinders; hidden lines are dashed. Tolerances are not shown before TRL 4.
- Sheets are exported as SVG, PDF and a 300 dpi PNG.
- The revision table in the top right of the sheet lists every revision.
- Concept sketches use the same sheet and title block and carry the label "CONCEPT, NOT FOR FABRICATION".
- Geometry comes from `cad/src/*.py` (build123d). Sheets are generated by `.kit/drawing.py` and never edited by hand.

## 7. Project codes

| Code | Project | Code | Project | Code | Project |
| --- | --- | --- | --- | --- | --- |
| TBK | ThermaBrick | PCF | PicoFlow | HLT | HelioLite |
| CCB | CharCube | DRN | DustRunner | TRT | TremorTrace |
| STC | StepCue | FXH | FlexHand | CPD | ColdPod |
| SCL | SunClave | STR | SteamRoot | GGD | GrainGuard |
| SDL | SeedLine | ZBX | ZeerBox | RMS | RootMesh |
| DWD | DewDrive | SSK | StillStack | PPR | PotPress |
| WWT | WaterWatch | LMF | LumaFlow | FCL | FieldCell |
| CNP | ConePro | CVC | CulvertCrawl | EGD | EmberGuard |
| SNF | SnapFrame | CGM | CargoMule | SCM | StepClimber |
| SWC | SwapCell | PLP | PalletPilot | FTK | FlatTrike |
| WWK | WaterWalker | GRR | GrowRider | SSP | SunSpoke |
| SGN | StepGen | PBX | PowerBox | WML | WasteWise-ml |
| WSC | WasteWise Scan | RFE | ReflowEconomy | | |
| OHP | Portfolio-wide | | | | |

## 8. Build and publish

- `python .kit/render.py` checks every controlled document and renders it to `docs/pdf/<doc_id>_v<version>.pdf`.
- `python .kit/drawing.py` (called from each project's `cad/src/sheets.py`) builds drawing sheets as SVG and PDF in `cad/drawings/`.
- The GitHub Action in `.github/workflows/docs.yml` runs the checks on every push and attaches PDFs to a GitHub Release whenever a release tag is pushed.
- Public releases follow section 14: `python .kit/release_gate.py` must pass, and the release tag is `v0.<TRL>.0` (for example `v0.3.0` at TRL 3).

## 9. Technology Readiness Level (TRL)

Each project states its maturity as a Technology Readiness Level on the NASA and US DOE 1 to 9 scale. The TRL rates this specific design, not the underlying technology. A sand battery is commercial elsewhere, but a new sand battery design starts at TRL 2 until evidence shows otherwise.

| TRL | Definition | Evidence the repo must contain |
| --- | --- | --- |
| 1 | Basic principles observed | Problem statement (PRB) |
| 2 | Technology concept formulated | Draft precis (PRC) and requirements (REQ) |
| 3 | Analytical or experimental proof of concept | Calculation note (CAL), working build123d model with STEP export, drawing sheet (DWG), priced BOM with every unit cost filled in, prototype build plan (BLD) with pictures, `design_state: constructable` |
| 4 | Components validated in the lab | Test report (TST) with `environment: lab`, build log entries |
| 5 | Validated in a relevant environment | Test report (TST) with `environment: relevant` |
| 6 | System prototype demonstrated in a relevant environment | Precis at version 1.0 or later with status Released, a drawing at a lettered revision (Rev A or later), and a system-level TST with `environment: relevant` |
| 7 to 9 | Operational demonstration through proven in service | Beyond portfolio scope; claim only with a named deployment partner and evidence |

Rules:

- `project.yaml` records `trl` (current level), `trl_target` (the level the current effort aims for) and `trl_evidence` (the files that support the claim).
- `python .kit/render.py --check` fails if the evidence for the claimed TRL is missing. CI runs this check on every push.
- Documentation alone cannot go past TRL 3. TRL 4 and above require hardware and a test report.
- TRL and visibility are independent. A repo can be public at TRL 3 as a documented design ready to build.
- A change of TRL is recorded in the build log with the date and the evidence that justified it.

## 10. Portfolio phase and TRL cap

`.kit/PHASE.yaml` sets the current phase. During the **populate** phase every repo is capped at **TRL 3**: `trl` and `trl_target` may not exceed 3, and the check fails if they do. Every repo targets the cap: `trl_target` must equal 3, so a new repo is taken all the way to TRL 3 (scaffold, populate and advance, see `/to-trl3`). Work that belongs to TRL 4 or later (building or testing hardware, test articles, test plans and reports, build-log entries, purchasing lists, PCB layouts) must not be started. The prototype build plan (BLD, section 18) is TRL 3 paper work and is required. Where it already exists it is kept, flagged in the check output, and not extended. Only Amish changes `PHASE.yaml`.

Every repo carries a `CLAUDE.md` with the working rules for AI sessions: the TRL cap, decision rights (nothing is recorded as decided unless Amish decided it), one step per session, and a mandatory `docs/REVIEW.md` before stopping.

## 11. Concept media

Every repo at TRL 2 or above explains its idea visually. Media are generated from a build123d massing model with `.kit/concept.py`, never drawn by hand, so they stay in step with the design.

| File | Required | Purpose |
| --- | --- | --- |
| `media/hero.png` | TRL 2+ | Shaded isometric render with a 1.75 m person for scale; the website card image |
| `media/concept-blueprint.png` and `.pdf` | TRL 2+ | Blueprint concept sheet: orthographic and isometric views, scale, key figures, title block |
| `media/model.glb` and `media/viewer.html` | TRL 2+ | Interactive 3D viewer (glTF plus model-viewer) for the website |
| `media/cutaway.png` | When the inside matters | Section view showing internal parts |
| `media/exploded.png` | Recommended | Exploded view with numbered callouts matching the BOM |
| `media/flow.png` | When energy or material moves | System, energy or material flow diagram with losses |

Session commands in `.claude/commands/` (`/populate`, `/advance-trl3`, `/rein-in`, `/refresh-media`) carry the standard prompts, so every Claude Code session starts from the same instructions.

At TRL 2 a massing model is enough: correct overall proportions and main components. All concept media carry "CONCEPT, NOT FOR FABRICATION". The check warns when required media are missing at TRL 2 and fails at TRL 3.
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

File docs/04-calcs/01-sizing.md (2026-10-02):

---
doc_id: PCF-CAL-001
title: PicoFlow sizing calculations
project: PicoFlow
doc_type: Calculation note
version: "0.5"
status: Draft
date: '2026-10-01'
author: Amish Chadha
license: CERN-OHL-S-2.0
revisions:
- version: "0.1"
  date: '2026-09-25'
  author: Amish Chadha
  change: First-principles sizing for TRL 3 against PCF-REQ-001 v0.3
- version: "0.2"
  date: '2026-09-25'
  author: Amish Chadha
  change: Recommendations accepted by Amish (DDR-002); 125 mm penstock, 33 mm inserts, results against PCF-REQ-001 v0.4
- version: "0.3"
  date: '2026-10-01'
  author: Amish Chadha
  change: Rerun on the constructable design (PCF-DDR-003); valve reducer and expander, new manifold layout, flange bearing units, component masses; budget treated as a value-engineering target
- version: "0.4"
  date: '2026-10-01'
  author: Amish Chadha
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

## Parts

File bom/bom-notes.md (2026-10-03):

# BOM notes

All costs are indicative USD prices for TRL 3 (a priced BOM on paper), not quotes. Every line has a unit cost and a supplier or supplier type. Item numbers match the exploded view (`media/exploded.png`), the general arrangement drawing PCF-DWG-001 and the component table in `docs/02-concept.md`. The totals are computed by `docs/04-calcs/sizing.py` (PCF-CAL-001 section 11).

| Group | Items | Cost |
| --- | --- | --- |
| Turbine kit, new generator | 1 to 8, 10 to 16, 18, 19 | USD 618.00 |
| Turbine kit, salvaged washing machine motor (about USD 40) | 1 to 8, 10 to 16, 18, 19 | USD 548.00 |
| Penstock, 20 m of 125 mm (excluded, site-dependent) | 9 | USD 140.00 |
| Battery (excluded, household item) | 17 | USD 160.00 |

Value-engineering target: USD 450 (`budget_usd` in `project.yaml`; a hypothetical control target, not a limit, Amish, 2026-10-01). Estimated cost of the constructable design: USD 618 (USD 168 over the target); USD 548 with a salvaged motor (USD 98 over). The penstock and battery are outside the target, as decided on 2026-09-25 (PCF-DDR-001 D1). Prices are to be firmed with quotes before any build (TRL 4, on hold).

Changes for the constructable design (PCF-DDR-003, 2026-10-01), from USD 448.00: fixings, new line 19 (+USD 28); pipe stands, new line 18 (+USD 15); 125 x 90 reducer, flexible couplings and gaskets in line 7 (+USD 12); flange bearing units, sleeves, V-ring and 160 mm guard in line 3 (+USD 10); valve reducer, expander and nipples in line 8 (+USD 8); forebay tank connector and screen frame in line 10 (+USD 8); post anchor in line 12 (+USD 3); clamping hub in line 2 (+USD 2).

Earlier changes: the design-point penstock changed from 110 mm to 125 mm on 2026-09-25 (PCF-DDR-002 N1), outside the kit; from TRL 2 (USD 424): 90 mm branches (+USD 8), multi-turn gate valve (+USD 2), coupling guard (+USD 3), independent clamp in the controller (+USD 3), 8.2 ohm clamp resistor (+USD 13), shorter frame (-USD 5).

Full-bore inlet valve (decided by Amish, 2026-10-01, N6 option a; `docs/06-design-decisions.md`), from USD 534.00: line 8 rises from USD 40 (90 mm gate valve, reducer, expander and two nipples) to USD 120 (+USD 80). Price basis: an estimate, not a quote. Full-bore PVC-U gate valves with socket ends are made in sizes up to DN300 (for example by Petron Thermoplast, PN10, handwheel), but no published price was found for the 125 mm size; US-made 4 in PVC gate valves list at over USD 1,000 (Spears 2022-040, USD 1,700.91 at pvcfittingsonline.com, read 2026-10-01). USD 115 is assumed for an imported metric PVC-U valve, with no published price behind it, and USD 5 for the 175 mm pipe piece (cut from the penstock) and solvent cement. The line must be quoted before any build; it buys back about 3.9 W at the design point (PCF-CAL-001).

Clamp resistor (decided by Amish, 2026-10-01; `docs/06-design-decisions.md`), from USD 614.00: line 15 rises from USD 28 to USD 32 (+USD 4) for a 6.8 ohm aluminium-clad clamp resistor rated 350 W or more in place of the 8.2 ohm, 300 W one. Indicative price, to be quoted. Line 7 now reads 34 mm inserts, matching the model and PCF-CAL-001 (a wording fix; no price change).

Decisions of 2026-10-02 (PCF-DEC-001): the frame (line 11) and pipe stands (line 18) are welded from bare steel and hot-dip galvanized or painted after welding, never welded after galvanizing; the guard in line 3 is 160 mm PVC pipe, or a clear polycarbonate tube of the same size, never acrylic; the housing (line 6) has no window. No quantity or price changed. Follow-up 2026-10-02: lines 11 and 18 now say bare steel angle, hot-dip galvanized or painted after welding; the fabricator has not quoted galvanizing or paint separately, so no coating cost is added, and a small-batch galvanizing minimum charge could exceed the USD 15 and USD 5 line prices (to firm up with the frame quote).

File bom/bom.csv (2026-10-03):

item | qty | spec | supplier | unit_cost_usd | make_buy | notes
1 Turgo runner | 1 | 200 mm OD, about 150 mm pitch diameter, 20 buckets, printed in PETG (prototype) or glass-filled nylon, about 0.5 kg; four M5 heat-set inserts in the hub top | Printed locally; PETG filament from any 3D printing supplier | 15.00 | make | Filament and print cost; PETG for the prototype and glass-filled nylon for field units (decided 2026-09-25); about 525 g, about 21 h (PCF-CAL-001)
2 Shaft and hub | 1 | 20 mm 316 stainless shaft cut to 294 mm; clamping shaft hub, 20 mm bore, 56 mm flange with four 5.5 mm holes | Metal stockist; power transmission or robotics supplier for the hub | 24.00 | buy | Indicative price; the hub replaces the keyed hub and clamp nut (PCF-DDR-003 P4)
3 Sealed bearings and bearing housing with motor mount | 1 | Two 4-bolt flange bearing units, 20 mm bore (UCF204 class, sealed 6204-class insert bearings); four 24 mm spacer sleeves; rubber V-ring seal for a 20 mm shaft; four post sleeves of 20 x 2 mm steel tube, 145 mm; 280 x 280 x 8 mm aluminium generator plate; 160 mm PVC pipe guard 146 mm long | Bearing distributor (UCF204 class, any maker); metal stockist; plumbing supplier for the guard offcut | 43.00 | buy | Indicative price; flange units replace the machined housing for two 6204-2RS bearings (PCF-DDR-003 P3); bearing L10 life over 7 million h at the worst load (PCF-CAL-001)
4 Jaw coupling | 1 | L-075 class jaw coupling with elastomer spider, bores to suit shaft and generator | Power transmission supplier (Lovejoy L-075 class or generic) | 10.00 | buy | Indicative price; inside the guard in item 3
5 Generator | 1 | Low-speed three-phase BLDC motor used as a generator, about 500 W rated, about 10 rpm/V, face mounting with a shaft of at least 50 mm | Motor distributor or online marketplace (low-speed permanent magnet generator class) | 110.00 | buy | Indicative price for a new unit (decided 2026-09-25); a salvaged direct-drive washing machine motor at about $30 to $50 is the documented low-cost variant; confirm the rpm per volt constant | overspeed rating | face screw circle and shaft length before purchase
6 Housing and lid | 1 | 315 mm PVC sewer pipe cut to 303 mm, open bottom, with two nozzle holes; 400 x 400 x 12 mm HDPE lid with a groove for the housing and one for the guard | Plumbing supplier (315 mm SN4 sewer pipe offcut); plastics supplier for the lid | 35.00 | buy | Indicative price
7 Nozzle manifold and two nozzles | 1 | 125 x 90 mm reducing tee, 125 x 90 mm reducer, about 1.6 m of 90 mm PVC pipe in five lengths, three 90 degree elbows, two 90 mm flexible rubber couplings with band clamps, two printed nozzles with saddles, two 2 mm EPDM saddle gaskets, a pair of printed 34 mm inserts (20 to 45 mm set made as needed) | Plumbing supplier (90 mm DWV or SN4 fittings); nozzles and inserts printed locally | 50.00 | buy | Indicative price; layout and fittings changed so they can be joined (PCF-DDR-003 P5 and P10); two 34 mm inserts at the design point (125 mm penstock | full-bore valve; PCF-CAL-001)
8 Inlet valve | 1 | 125 mm full-bore PVC-U gate valve, PN10 class, solvent-weld sockets for 125 mm pipe at both ends, multi-turn handwheel (non-rising stem), about 330 mm long over the sockets and 5.5 kg (catalogue class, to confirm); a 175 mm piece of the 125 mm penstock pipe joins it to the tee | Industrial plastic valve supplier (UPVC gate valves are made from DN15 to DN300 with socket ends); the pipe piece is cut from the penstock | 120.00 | buy | Estimate, not a quote: no published price was found for a 125 mm PVC-U gate valve; USD 115 for the valve and USD 5 for the pipe piece and solvent cement, set between the 90 mm valve with fittings (USD 40) and US-made 4 in PVC gate valves, which list at over USD 1,000 (Spears 2022-040, USD 1,700 at pvcfittingsonline.com, 2026-10-01); quote before any build. Full bore matched to the 125 mm penstock (decided by Amish 2026-10-01, N6 option a; replaces the 90 mm valve, reducer and expander of PCF-DDR-003 P11); multi-turn so it cannot close in under about 10 s (decided 2026-09-25; surge check in PCF-CAL-001)
9 Penstock | 20 | 125 mm PVC pipe (SN8 drainage grade) with couplings and a support every 2 to 3 m | Plumbing supplier | 7.00 | buy | Indicative price per meter (about $140 for 20 m); 125 mm instead of 110 mm decided 2026-09-25 (PCF-DDR-002 N1); drainage grade allowed with the slow-closing valve (decided 2026-09-25); site-dependent and excluded from kit cost
10 Forebay and intake screen | 1 | Plastic tub about 560 x 460 x 400 mm with an overflow notch, 125 mm tank connector, 6 mm stainless mesh screen on a 20 x 20 x 3 mm aluminium angle frame | Hardware shop | 28.00 | buy | Indicative price; tank connector added so the penstock joins the tub (PCF-DDR-003 P13)
11 Turbine frame | 1 | Bare 40 x 40 x 4 mm steel angle, about 1.8 m: a 380 x 380 mm welded square and four 70 mm legs; four 80 x 80 x 5 mm foot plates; four 30 x 20 x 5 mm flat bar pipe stops; bolted to a pad over the tailrace; welded bare, then hot-dip galvanized or painted after welding (never welded after galvanizing) | Local fabricator or hardware shop | 15.00 | make | Indicative material cost; no separate galvanizing or paint quote yet | so no coating cost is added; the frame is 380 mm square so the housing sits on its angle (PCF-DDR-003 P1); nozzles 280 mm above tailwater (R13)
12 Equipment post | 1 | Treated timber post 70 x 70 mm, 1.4 m, in a bolt-down post anchor; carries rectifier, controller and dump load | Hardware shop | 18.00 | make | Indicative material cost
13 Three-phase rectifier | 1 | Three-phase bridge 35 A 1000 V on an aluminium heat sink in a vented box | Electronics distributor | 12.00 | buy | Indicative price
14 MPPT and dump-load controller | 1 | Microcontroller, synchronous buck converter to 12 V, MOSFET dump-load switch, independent comparator clamp (on at 48 V, off at 40 V), IP65 box rated for 100 V DC | Electronics distributor | 43.00 | buy | Indicative parts cost for the open-design board (the TRL 3 design, decided 2026-09-25), including a comparator-driven clamp switch independent of the microcontroller; an off-the-shelf diversion controller is used only for the first bench tests
15 Dump-load resistor | 1 | 300 W 12 V heating element or wire-wound resistor for diversion, plus a 6.8 ohm 350 W (or higher rated) aluminium-clad clamp resistor on the DC bus, in a vented metal guard | Electronics or heating supplier | 32.00 | buy | Indicative price; the 6.8 ohm clamp resistor (decided by Amish 2026-10-01, replacing 8.2 ohm 300 W; +USD 4, to be quoted) is switched in by the clamp in item 14 above 48 V and settles the bus at 36.7 V in the worst case, below the 40 V release, taking 339 W at 48 V (PCF-CAL-001); both run hot
16 Wiring fuse and isolator | 1 | 4 mm2 cable, 20 A fuse at the battery, DC isolator rated 100 V, cable glands and lugs | Electrical supplier | 20.00 | buy | Indicative price
17 Battery | 1 | 12 V about 50 Ah LiFePO4 with BMS, or an existing 12 V lead-acid battery | Solar or battery supplier | 160.00 | buy | Household item; excluded from kit cost; 12 V decided 2026-09-25
18 Pipe stands | 3 | Each: 40 x 40 x 4 mm bare steel angle upright about 260 mm, 100 x 100 x 6 mm foot plate, 60 x 60 x 5 mm top plate, 90 mm pipe clip with an M8 boss; welded bare, then galvanized or painted after welding | Local fabricator or hardware shop | 5.00 | make | No separate coating quote yet | so no coating cost is added; new line: the branch pipework had no support (PCF-DDR-003 P12)
19 Fixings | 1 | Stainless or galvanized: 2 m of M10 threaded rod (four 345 mm tie rods, four 195 mm post rods), 24 M10 nuts, 16 penny washers 30 mm, four M10 x 80 bolts, eight M6 x 25 bolts with nuts and washers, four M6 x 20 generator screws, four M5 x 16 hub screws, four M4 x 12 insert screws, eight heat-set inserts (four M5, four M4), four M12 anchors | Fastener supplier | 28.00 | buy | New line: fixings for the joints added in PCF-DDR-003

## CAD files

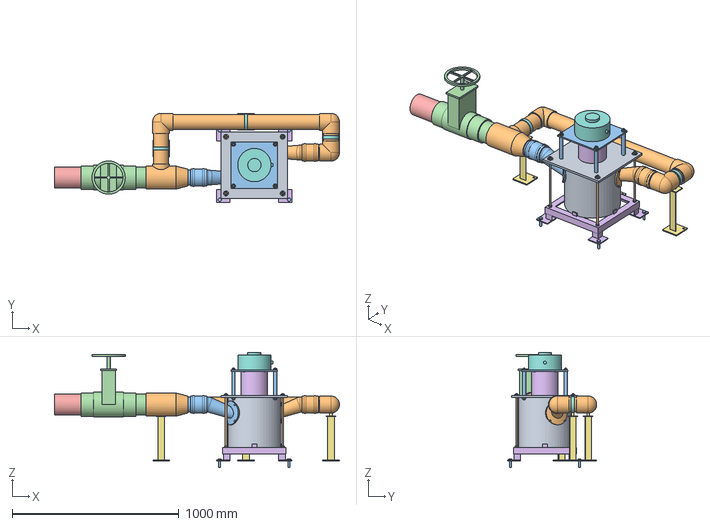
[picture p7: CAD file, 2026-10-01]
cad/step/picoflow-turbine-assembly.step
1711.0 x 537.0 x 691.0 mm

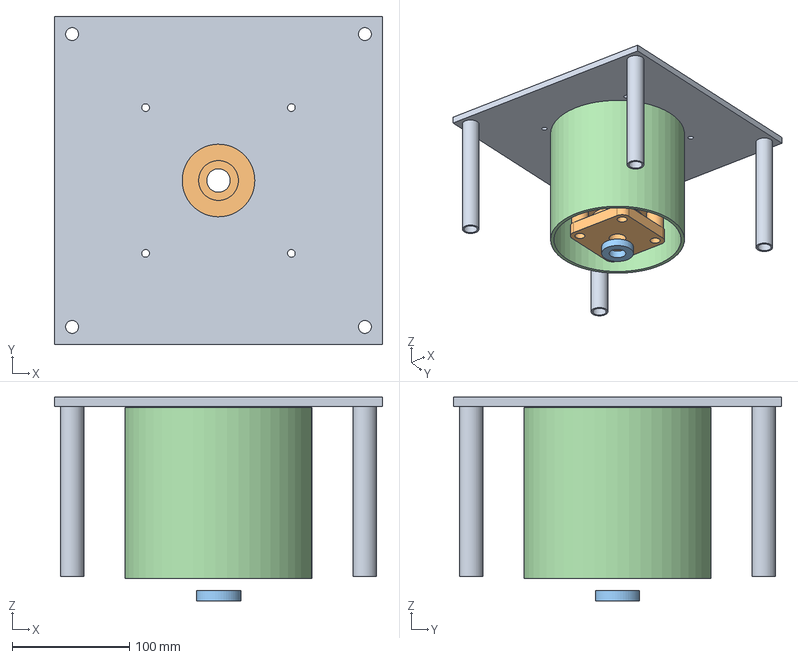
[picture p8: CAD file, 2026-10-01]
cad/step/picoflow-bearing_mount.step
280.0 x 280.0 x 174.0 mm

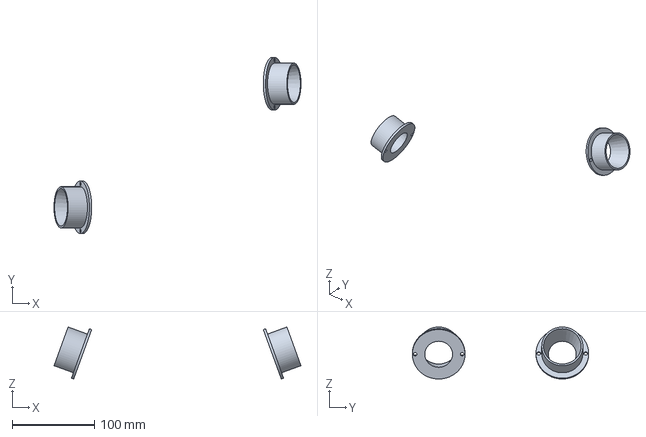
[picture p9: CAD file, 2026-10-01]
cad/step/picoflow-insert-pair-34mm.step
299.7 x 214.0 x 63.1 mm

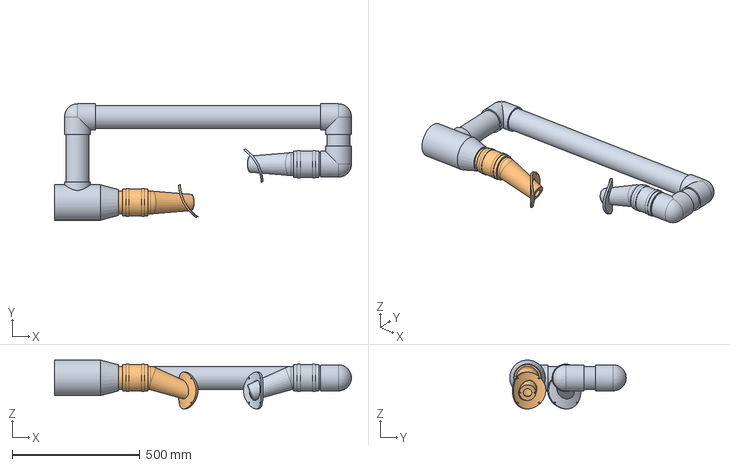
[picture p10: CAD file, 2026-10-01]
cad/step/picoflow-manifold.step
1161.0 x 455.5 x 191.1 mm

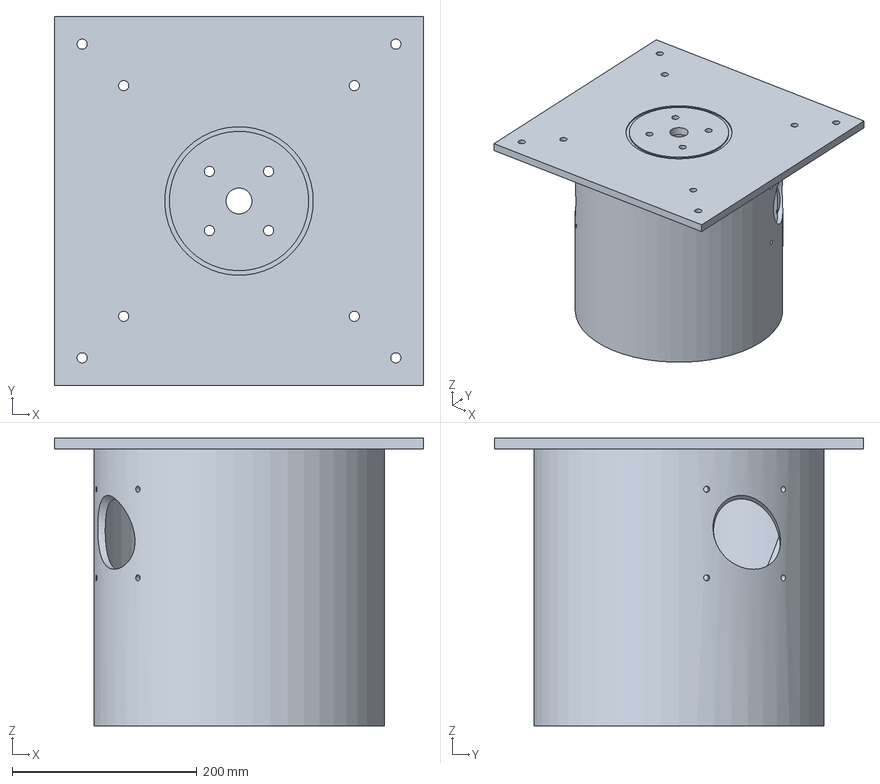
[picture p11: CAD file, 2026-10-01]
cad/step/picoflow-housing.step
400.0 x 400.0 x 312.0 mm

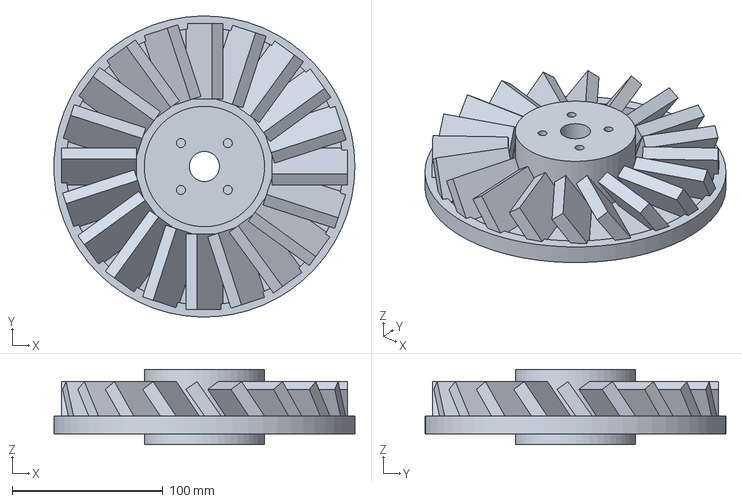
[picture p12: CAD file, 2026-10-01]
cad/step/picoflow-runner.step
199.9 x 199.9 x 50.0 mm

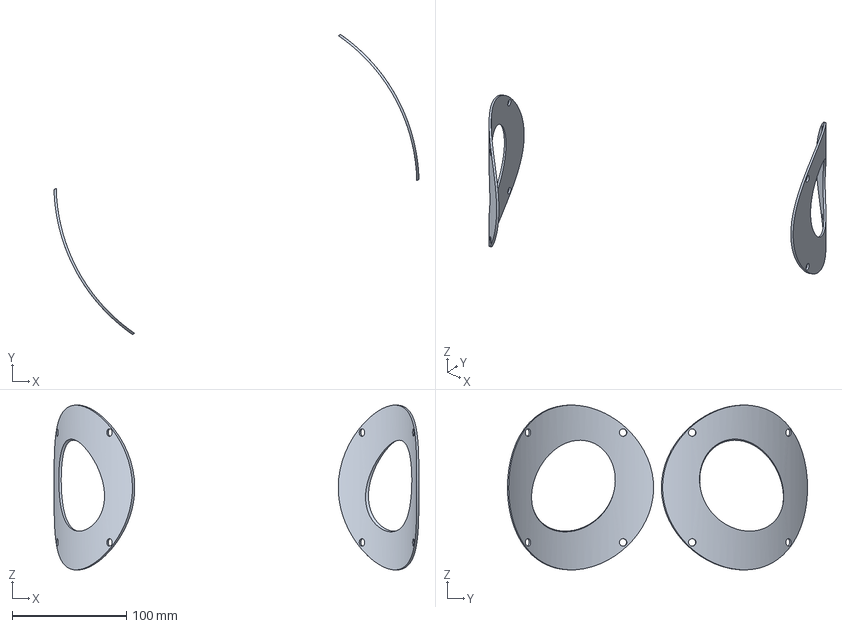
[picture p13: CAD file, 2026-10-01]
cad/step/picoflow-saddle-gaskets.step
318.9 x 262.2 x 144.0 mm

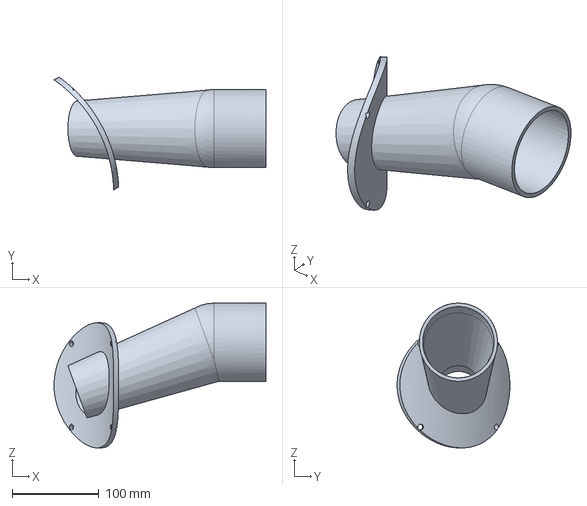
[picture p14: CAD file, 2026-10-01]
cad/step/picoflow-nozzle.step
243.9 x 129.8 x 166.6 mm

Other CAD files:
cad/stl/picoflow-bearing_mount.stl
cad/stl/picoflow-housing.stl
cad/stl/picoflow-insert-pair-34mm.stl
cad/stl/picoflow-manifold.stl
cad/stl/picoflow-nozzle.stl
cad/stl/picoflow-runner.stl
cad/stl/picoflow-saddle-gaskets.stl
cad/stl/picoflow-turbine-assembly.stl

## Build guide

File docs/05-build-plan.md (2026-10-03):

---
doc_id: PCF-BLD-001
title: PicoFlow prototype build plan
project: PicoFlow
doc_type: Build plan
version: "0.5"
status: Draft
date: '2026-10-02'
author: Amish Chadha
license: CERN-OHL-S-2.0
revisions:
  - version: "0.1"
    date: '2026-10-01'
    author: Amish Chadha
    change: First build plan; design made constructable (PCF-DDR-003)
  - version: "0.2"
    date: '2026-10-01'
    author: Amish Chadha
    change: Full-bore 125 mm inlet valve fitted with a short pipe piece (section 3.14, step 17, joint 13); pictures regenerated
  - version: "0.3"
    date: '2026-10-01'
    author: Amish Chadha
    change: Clamp resistor 6.8 ohm, 350 W (was 8.2 ohm, 300 W) in section 3.16 and the wiring picture (Figure 31); parts cost USD 618
  - version: "0.4"
    date: '2026-10-02'
    author: Amish Chadha
    change: "Decisions of 2026-10-02: frame and pipe stands welded from bare steel and galvanized or painted afterwards; guard PVC or polycarbonate, never acrylic; no housing window; safety stops S6 and S7 updated. Pictures unchanged"
  - version: "0.5"
    date: '2026-10-02'
    author: Amish Chadha
    change: "Approved follow-ups: frame and pipe stand making sketches (PCF-DWG-101, 111) now say bare steel, galvanized or painted after welding"
---

# PicoFlow prototype build plan

**Plan, not yet built.** How to build the first proof-of-concept prototype, component by component. Building and testing to it is TRL 4 work. Decisions still to be made are kept in the design decisions register ([docs/06-design-decisions.md](06-design-decisions.md)), not here.

## 1. What you are building

Figure 1. Every component, pulled apart and numbered in build order

*Figure 1. Every component pulled apart and numbered in build order. The penstock is a short stub; the real run is 10 to 30 m of pipe from the forebay.*

The prototype is one PicoFlow turbine set on a concrete pad over a tailrace, with its pipework, inlet valve, forebay and an equipment post for the electrics. Water from the forebay runs down the penstock, through a slow-closing valve and a tee, to two printed nozzles that fire jets onto a printed Turgo runner inside an open-bottomed plastic pipe; the runner turns a generator on top through a shaft in two sealed bearings. Figure 1 shows the 23 components in the order you make or fit them. Fourteen are made in a small workshop: the welded steel frame, the housing cut from sewer pipe, two printed nozzles and their inserts, the plastic lid, the shaft, the printed runner, the guard, the posts and sleeves, the generator plate, three pipe stands, the cut pipework, the forebay and the equipment post. Everything else is bought and fitted: bearing units, hub, coupling, generator, pipe fittings, valve, rectifier, controller modules, resistors, wiring and fixings. The work is sawing and welding steel angle, cutting and drilling plastic pipe and sheet, 3D printing, solvent welding PVC, and wiring bought modules. The turbine kit costs about USD 618 in parts with a new generator, from the bill of materials; the penstock and battery are extra.

> **Safety:** Streams and weirs can drown people; work at the site only at low flow, never alone, and close the intake before entering the stream. The runner and coupling spin at 300 to 450 rpm: close the valve and wait for them to stop before opening anything. With no load and a failed clamp the generator can reach about 80 V DC, so the DC side is enclosed and rated for 100 V. The dump load and clamp resistor run above 200 °C. The 12 V battery can deliver hundreds of amperes into a short. Close the gate valve slowly, over at least ten turns. Welding, grinding and printing need eye protection and ventilation.

## 2. What changed to make it buildable

The concept showed what the turbine does; some of its parts could not be made, fixed or assembled as drawn. Each change below keeps what the turbine does, and all of them are recorded in decision record PCF-DDR-003, open for Amish's review.

*Table 1. Changes from the concept.*

| Component | The concept had | The buildable design has | Why |
| --- | --- | --- | --- |
| Frame | Solid square bars, 420 mm square; the housing sat inside the opening with nothing under it | A welded square of 40 x 40 x 4 mm angle, 380 mm outside, with legs, foot plates and pipe stops (Figures 2 and 3) | The housing wall now stands on the angle |
| Frame, housing and lid | Not joined | Four tie rods from the frame corners through the lid; a groove under the lid locates the housing (Figures 3 and 13) | One set of nuts holds the stack and frees the lid for service |
| Bearings | A plain cylinder bored for the shaft, with no bearing seats | Two bought flange bearing units on spacer sleeves, bolted through the lid, and a V-ring seal (Figure 14) | No machining; seats, seals and locking come with the units |
| Runner fixing | A keyed hub and clamp nut, not drawn | A bought clamping hub screwed to the runner (Figure 17) | No keyway or thread to cut |
| Nozzles | Cones cutting into the housing wall, with no fixing and no joint to the pipe | Printed nozzles with a horizontal spigot, a bend and a saddle bolted to the housing on a gasket; a flexible coupling to the pipe (Figures 5 to 8) | The saddle fixes the aim and seals the hole |
| Nozzle tip and runner | The runner could not be lifted past the nozzle tips | Nozzle tips end at the housing wall, 115 mm before the strike point; runner 11 mm lower so the jets still meet the top of the buckets (Figure 18) | The lid, shaft and runner lift out together for service |
| Generator, posts, guard | Generator 5 mm above its plate; posts and guard with no fixing | Generator screwed to the plate; posts as tubes on threaded rods; a 160 mm pipe guard held between lid and plate (Figures 20 and 22) | Everything is clamped or screwed |
| Pipework | A tee and elbows placed closer together than real fittings allow; no supports | Penstock on the jet 2 line into a reducing tee, standard fittings with their sockets allowed for, three pipe stands (Figures 24 to 27) | Every fitting is a standard one |
| Inlet valve | A 90 mm valve drawn as a block on the 125 mm line | A full-bore 125 mm gate valve with solvent-weld sockets, joined to the tee by a 175 mm piece of penstock pipe (Figure 28) | It joins the 125 mm line directly, and its bore matches the penstock's, so it costs almost no head |
| Mass | Fixings and feet not counted | Generator plate 8 mm, foot plates 5 mm, post tube 20 x 2 mm | Keeps the turbine unit at 24.5 kg, under the 25 kg limit |

## 3. Making the components

Make and check each component before the assembly step that needs it. Sizes are in millimetres. Heights are measured up from the top of the pad, which is the normal tailwater level. "Jet 1" is the nozzle whose pipe runs round the housing; "jet 2" is the one fed straight from the tee. Workshop tolerance is 0.5 mm unless a step says otherwise; drawings do not carry tolerances before TRL 4.

### 3.1 Turbine frame

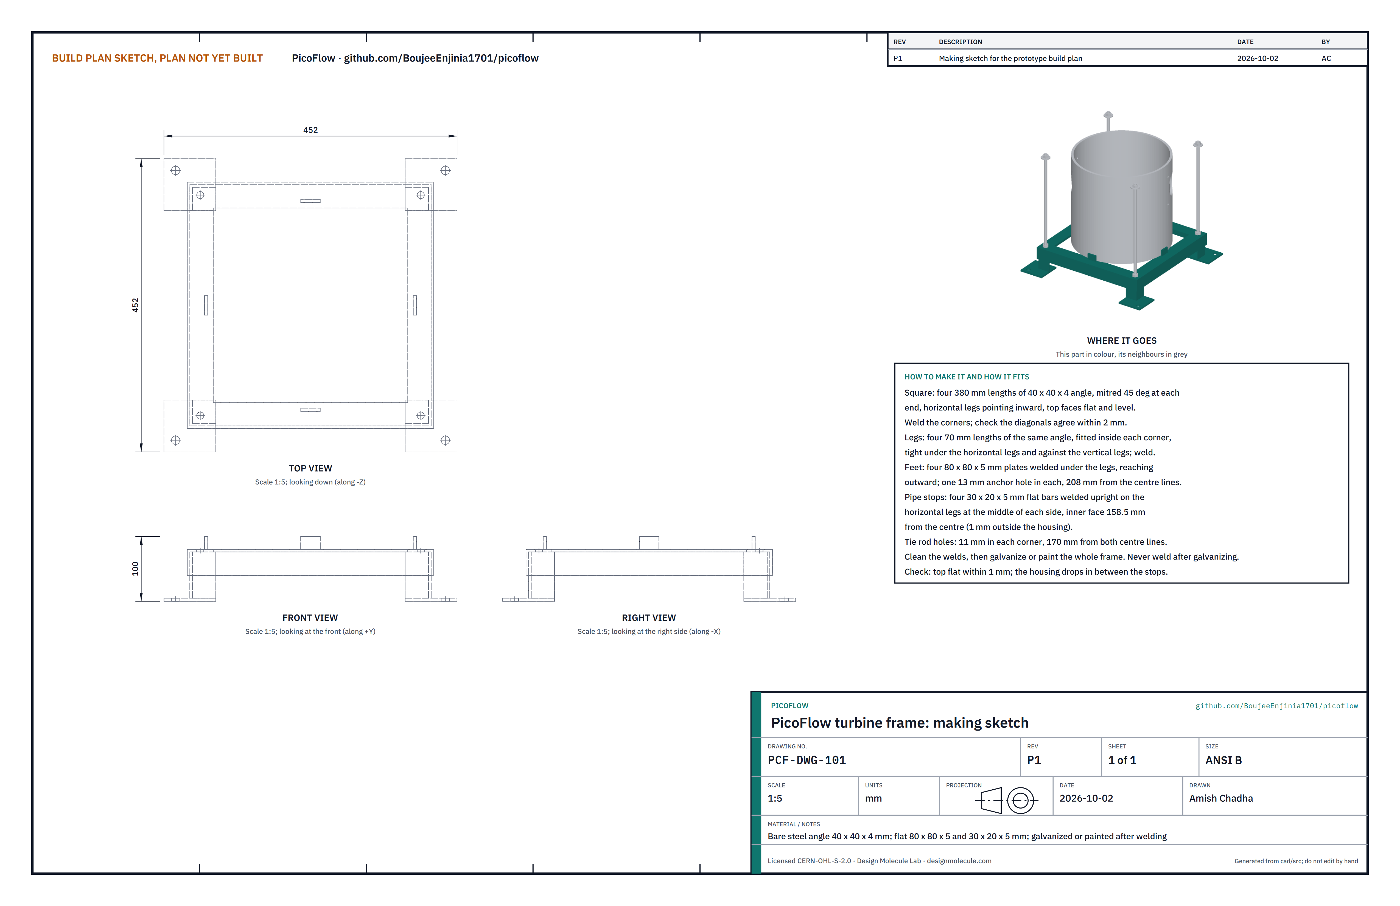
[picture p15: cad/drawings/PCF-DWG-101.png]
Figure 2. Making sketch of the turbine frame


*Figure 2. Turbine frame making sketch (PCF-DWG-101).*

**What it is and what it is made from.** The square steel frame the housing stands on, bolted to the pad over the tailrace. Bare (uncoated) steel angle 40 x 40 x 4 mm, about 1.8 m; flat bar 80 x 5 mm and 30 x 5 mm; hot-dip galvanized or painted after welding. A local fabricator welds it.

**How to make it.**

1. Cut four 380 mm lengths of angle with 45° mitres at both ends, so the horizontal legs point inward when the square is assembled.
2. Clamp the square on a flat bench, check that the diagonals agree within 2 mm, and weld the four corners. Grind the top faces flush.
3. Drill an 11 mm tie rod hole in each corner, through the overlapping horizontal legs, 170 mm from both centre lines.
4. Cut four 70 mm lengths of angle for the legs. Fit each inside a corner, tight under the horizontal legs and against the vertical legs, and weld.
5. Cut four 80 x 80 mm foot plates from 5 mm flat bar. Drill a 13 mm anchor hole in each, 18 mm in from two adjacent edges. Weld one under each leg so it reaches outward, with the hole outside the corner of the square (208 mm from both centre lines).
6. Cut four 30 mm lengths of 20 x 5 mm flat bar for the pipe stops. Weld one upright on each horizontal leg at the middle of each side, its inner face 158.5 mm from the centre of the frame.
7. Clean the welds, then have the whole frame hot-dip galvanized, or paint it. Never weld galvanized steel: the zinc gives off toxic fumes.

**How it fits the parts next to it.**

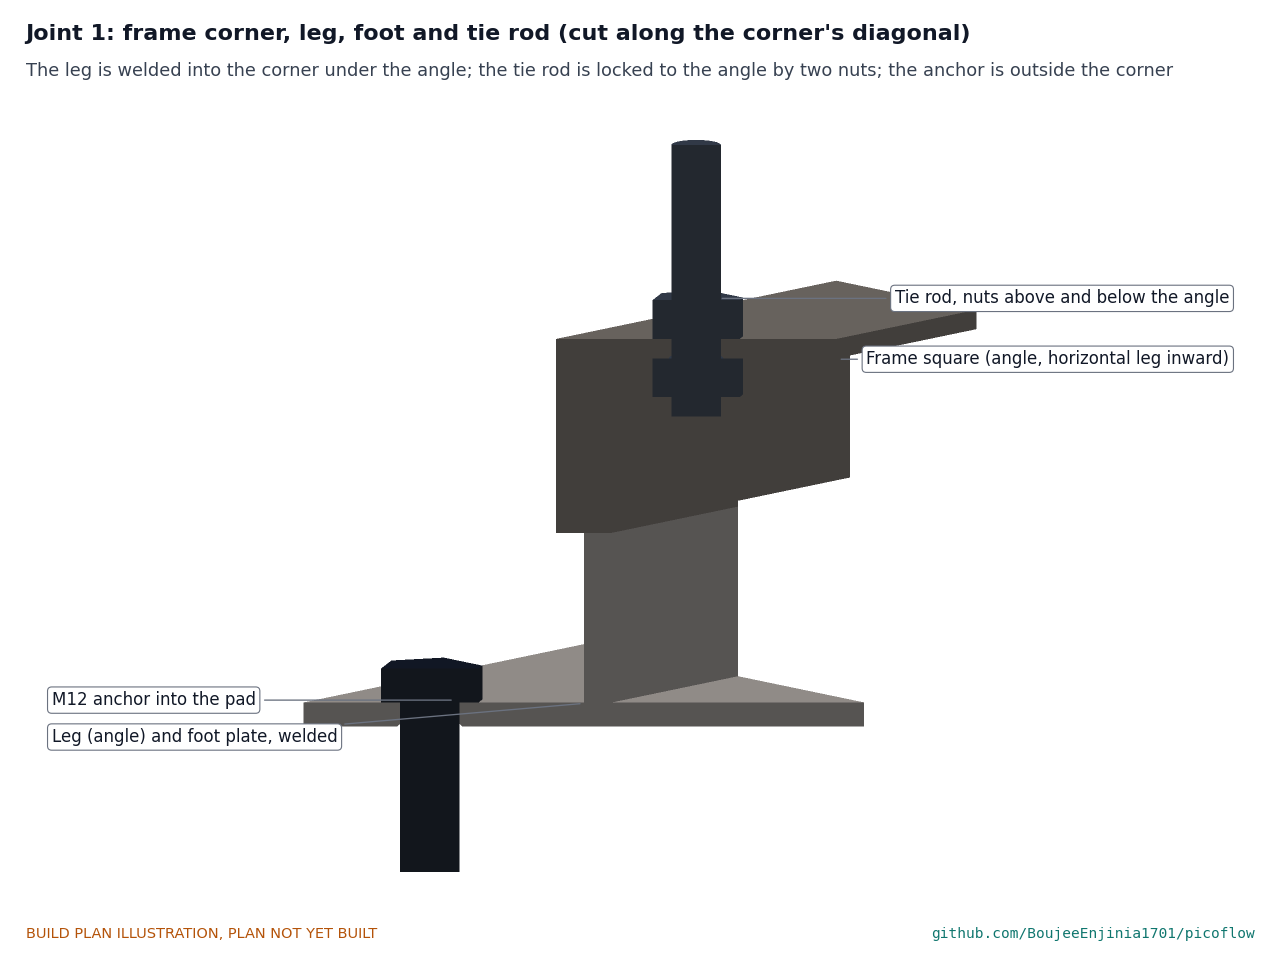
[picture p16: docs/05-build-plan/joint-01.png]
Figure 3. Joint 1: frame corner, leg, foot and tie rod


*Figure 3. A frame corner cut along its diagonal: the leg is welded inside the corner, the tie rod is locked to the angle by a nut above and below, and the anchor goes into the pad outside the corner.*

The housing wall stands on the horizontal legs; the inner edge of the angle lines up with the inside of the housing, so water falling from the runner passes clear. The four stops sit 1 mm outside the housing and stop it sliding (Figure 4). The tie rods pass up through the corner holes, beside the housing.

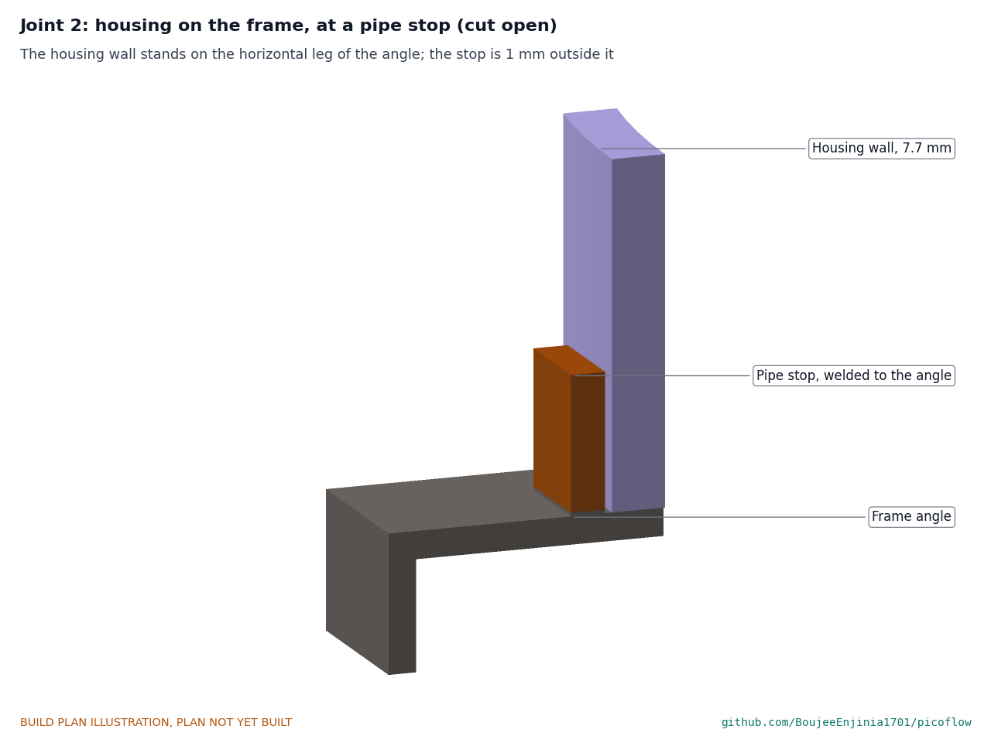
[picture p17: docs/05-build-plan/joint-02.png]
Figure 4. Joint 2: housing on the frame at a pipe stop


*Figure 4. The housing wall on the angle, with a pipe stop 1 mm outside it.*

**Check before moving on.** The top of the frame is flat within 1 mm; a 315 mm pipe offcut drops in between the stops without forcing.

### 3.2 Housing

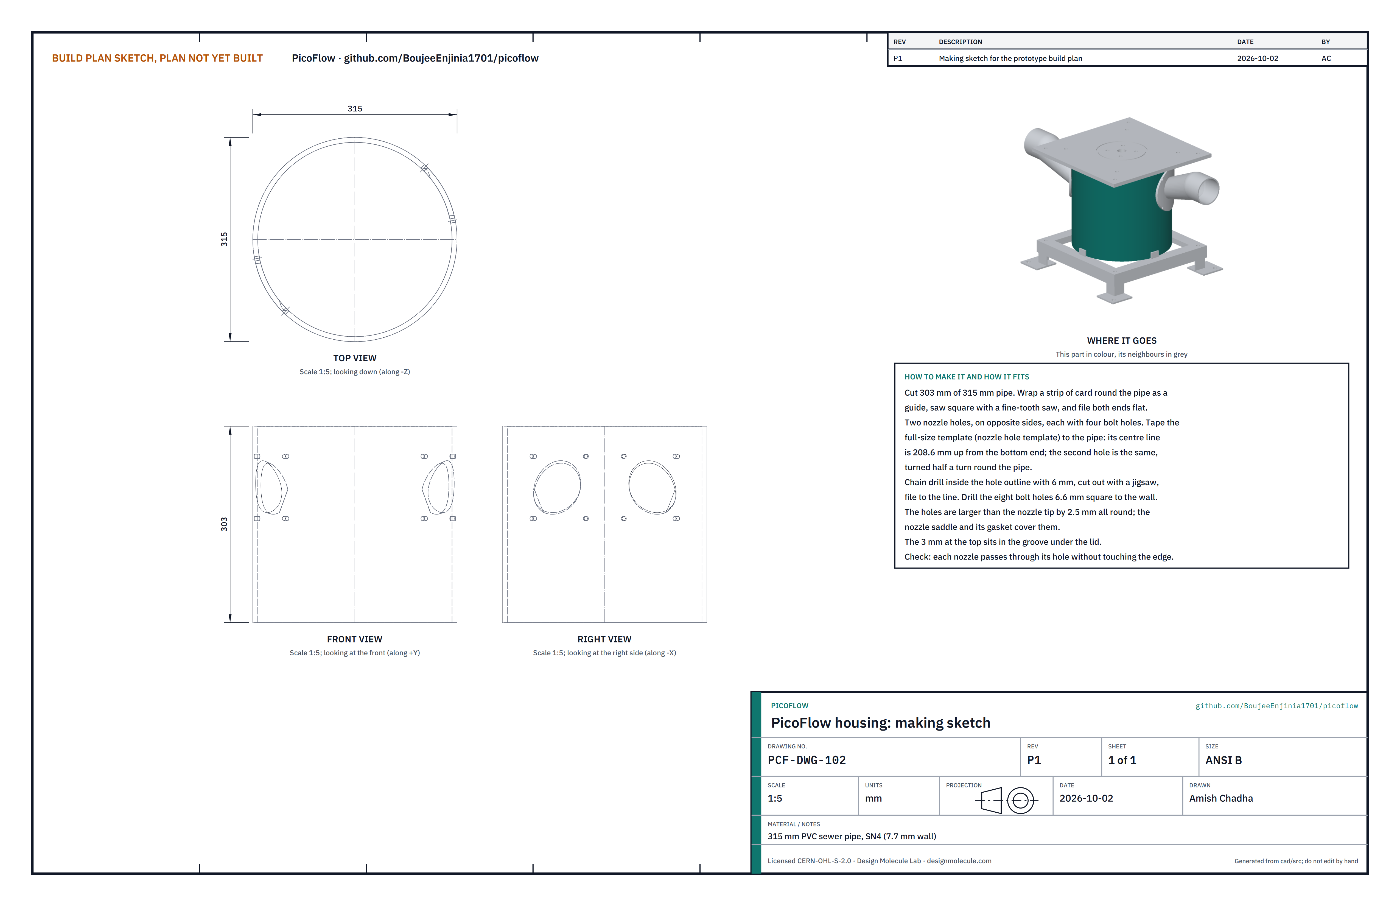
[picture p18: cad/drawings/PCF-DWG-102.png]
Figure 5. Making sketch of the housing


*Figure 5. Housing making sketch (PCF-DWG-102).*

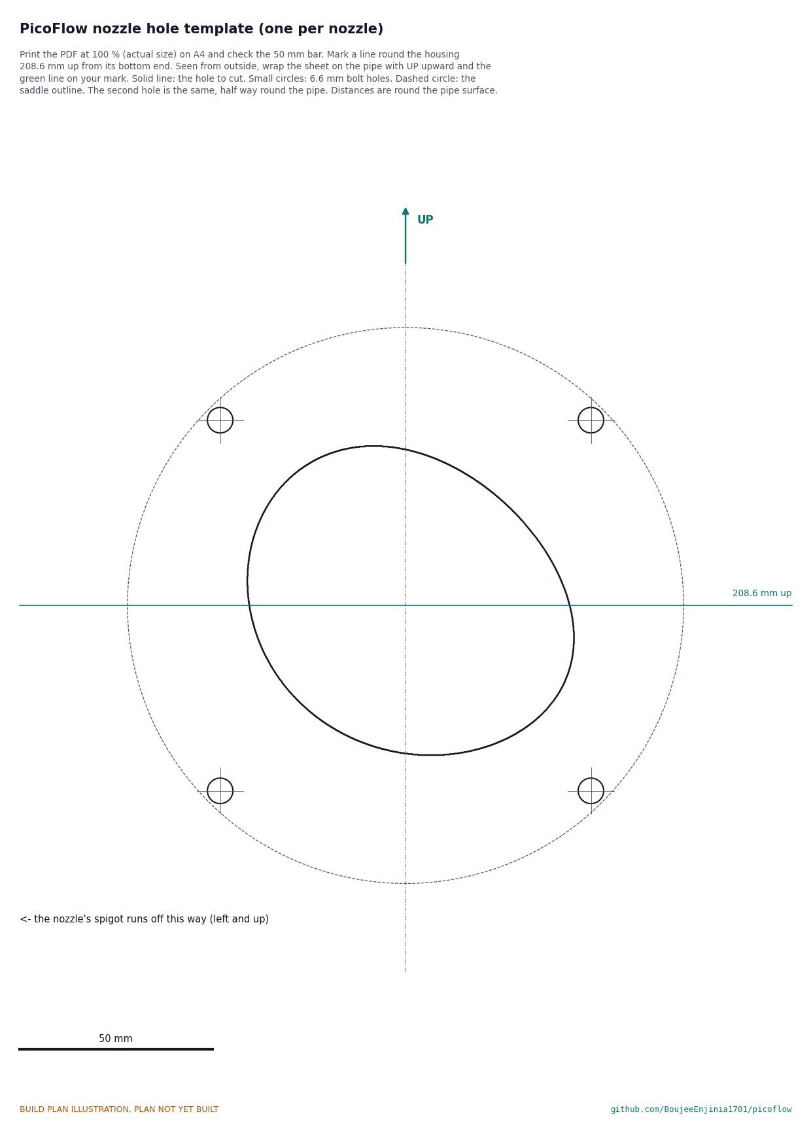
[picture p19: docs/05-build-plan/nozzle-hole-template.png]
Figure 6. Full-size template for the nozzle holes


*Figure 6. Nozzle hole template, unrolled onto the pipe surface. Print the PDF version (`docs/05-build-plan/nozzle-hole-template.pdf`) at 100 %.*

**What it is and what it is made from.** The open-ended pipe the runner turns inside; the jets come in through its wall and the water falls out of its bottom. 315 mm PVC sewer pipe, SN4 class, 7.7 mm wall.

**How to make it.**

1. Cut 303 mm of pipe. Wrap a strip of card round the pipe as a guide, saw square with a fine-tooth saw and file both ends flat.
2. Mark a line round the pipe 208.6 mm up from one end (the bottom end).
3. Print two copies of the template (Figure 6) at actual size and check the 50 mm bar. Tape one to the pipe with its green line on your mark and UP toward the top. Tape the second half way round the pipe, also on the mark and also with UP toward the top.
4. Drill the eight 6.6 mm bolt holes square to the wall through the small circles.
5. Chain drill 6 mm holes just inside each hole outline, cut out with a jigsaw and file to the line. The holes are 2.5 mm larger all round than the nozzle that passes through them.
6. Deburr every edge.

**How it fits the parts next to it.** The bottom end stands on the frame between the four stops (Figure 4). The top 3 mm sits in the groove under the lid (Figure 13). Each nozzle passes through its hole, and its saddle covers the hole (Figure 8).

**Check before moving on.** Hold a nozzle in each hole: the tip passes through without touching the edge, and the saddle's bolt holes line up with the wall's.

### 3.3 Nozzles (make 2, both the same)

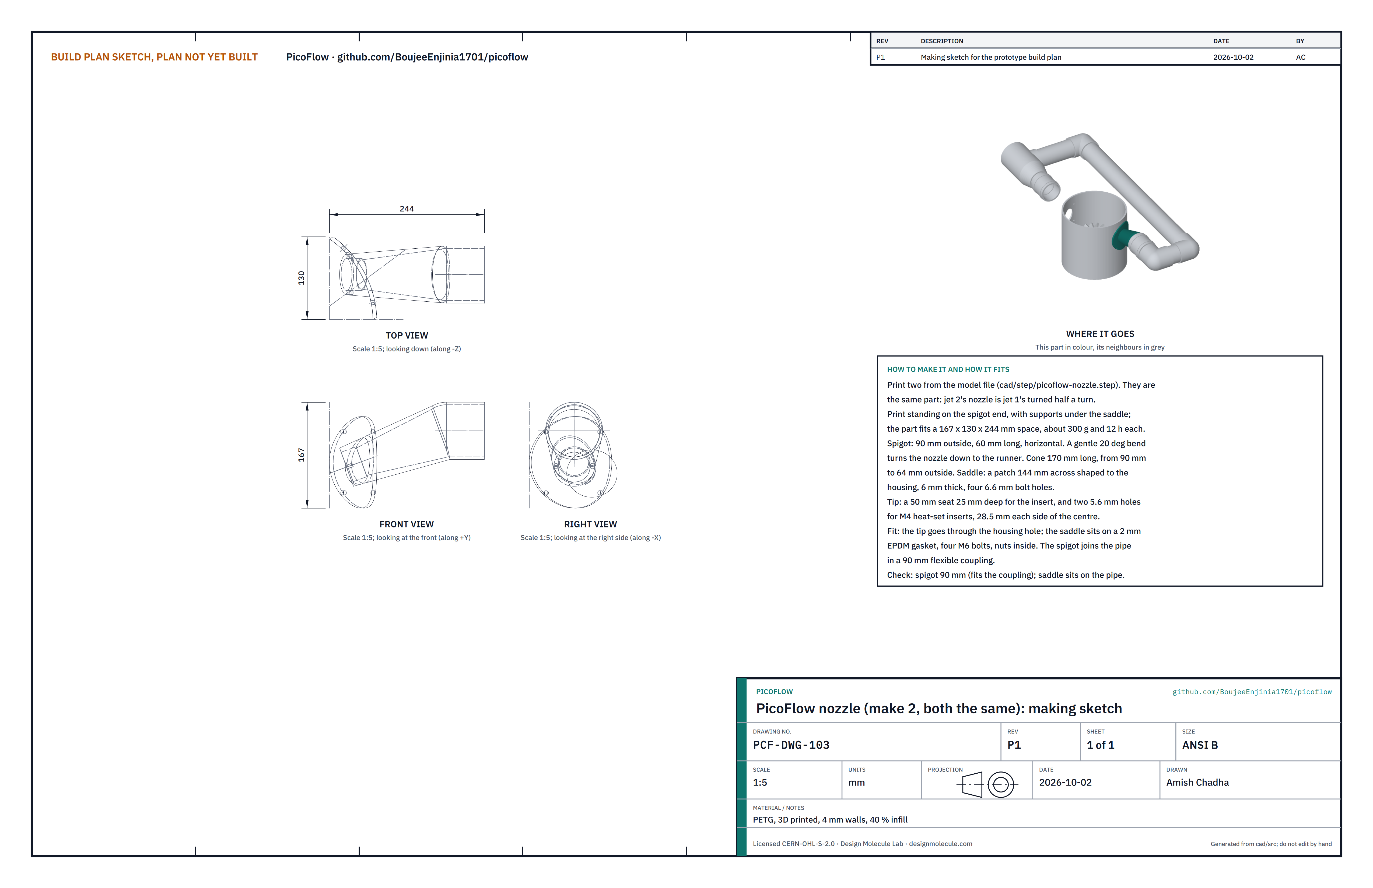
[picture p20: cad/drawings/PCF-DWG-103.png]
Figure 7. Making sketch of the nozzle


*Figure 7. Nozzle making sketch (PCF-DWG-103).*

**What it is and what it is made from.** The printed part that turns the pipe flow into a jet aimed at the runner. Each has a horizontal spigot that joins the pipe, a gentle bend, a converging cone, a saddle shaped to the housing, and a seat in its tip for the insert. PETG, 4 mm walls, 40 % infill. Jet 2's nozzle is jet 1's turned half a turn, so both are the same print.

**How to make it.**

1. Print two from the model file, standing on the spigot end, with supports under the saddle. Each needs a 167 x 130 x 244 mm space, about 310 g of filament and 12 h at 0.4 mm.
2. Remove the supports and sand the saddle face smooth so it follows the pipe.
3. Check the spigot is 90 mm outside; sand it down or build it up with tape until it fits the flexible coupling snugly.
4. Press two M4 heat-set inserts into the holes in the tip face with a soldering iron.
5. Cut two gaskets from 2 mm EPDM sheet to the saddle outline, with the nozzle hole and four bolt holes (the template's dashed circle, solid line and small circles).

**How it fits the parts next to it.**

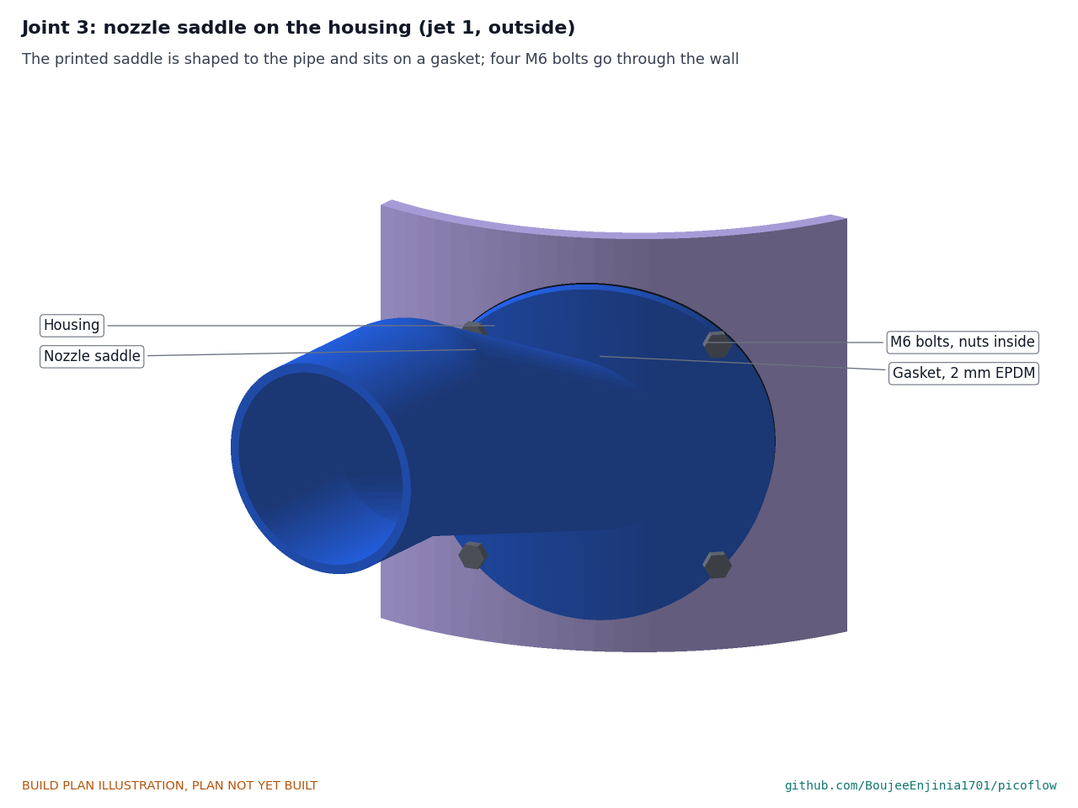
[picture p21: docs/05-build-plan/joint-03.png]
Figure 8. Joint 3: nozzle saddle on the housing


*Figure 8. The saddle sits on its gasket on the outside of the housing; four M6 bolts go through saddle, gasket and wall, nuts inside.*

The tip passes through the housing hole and ends just inside the wall, 115 mm before the point where the jet meets the runner. The saddle and gasket cover the hole, held by four M6 x 25 stainless bolts from outside with washers and nuts inside, tightened evenly until the gasket is just squeezed. The spigot joins its pipe in a 90 mm flexible coupling (Figure 27). The nozzle is never glued.

**Check before moving on.** The saddle sits on the pipe with no rocking; the spigot slides into a flexible coupling by hand.

### 3.4 Nozzle inserts (make 2 per size)

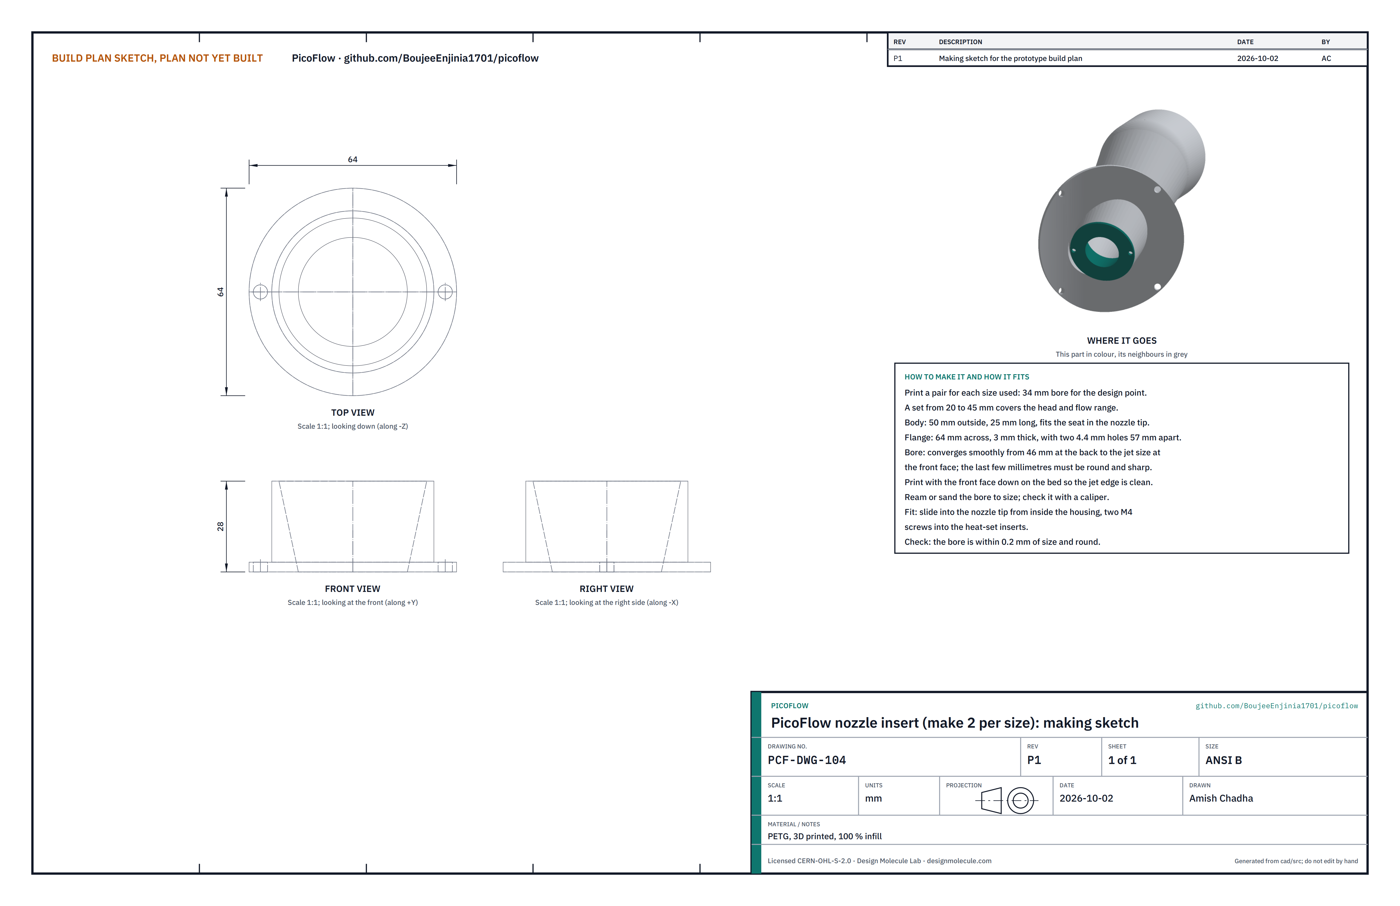
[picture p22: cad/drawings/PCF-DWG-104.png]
Figure 9. Making sketch of the nozzle insert


*Figure 9. Nozzle insert making sketch (PCF-DWG-104).*

**What it is and what it is made from.** The replaceable ring in each nozzle tip that sets the jet size. The design point uses 34 mm; a set from 20 to 45 mm covers the head and flow range. PETG, 100 % infill.

**How to make it.**

1. Print a pair of 34 mm inserts with the front face down on the bed, so the jet edge is clean.
2. Ream or sand the bore to size and check it with a caliper; it must be round and within 0.2 mm.
3. Check the body (50 mm) slides into the nozzle seat.

**How it fits the parts next to it.**

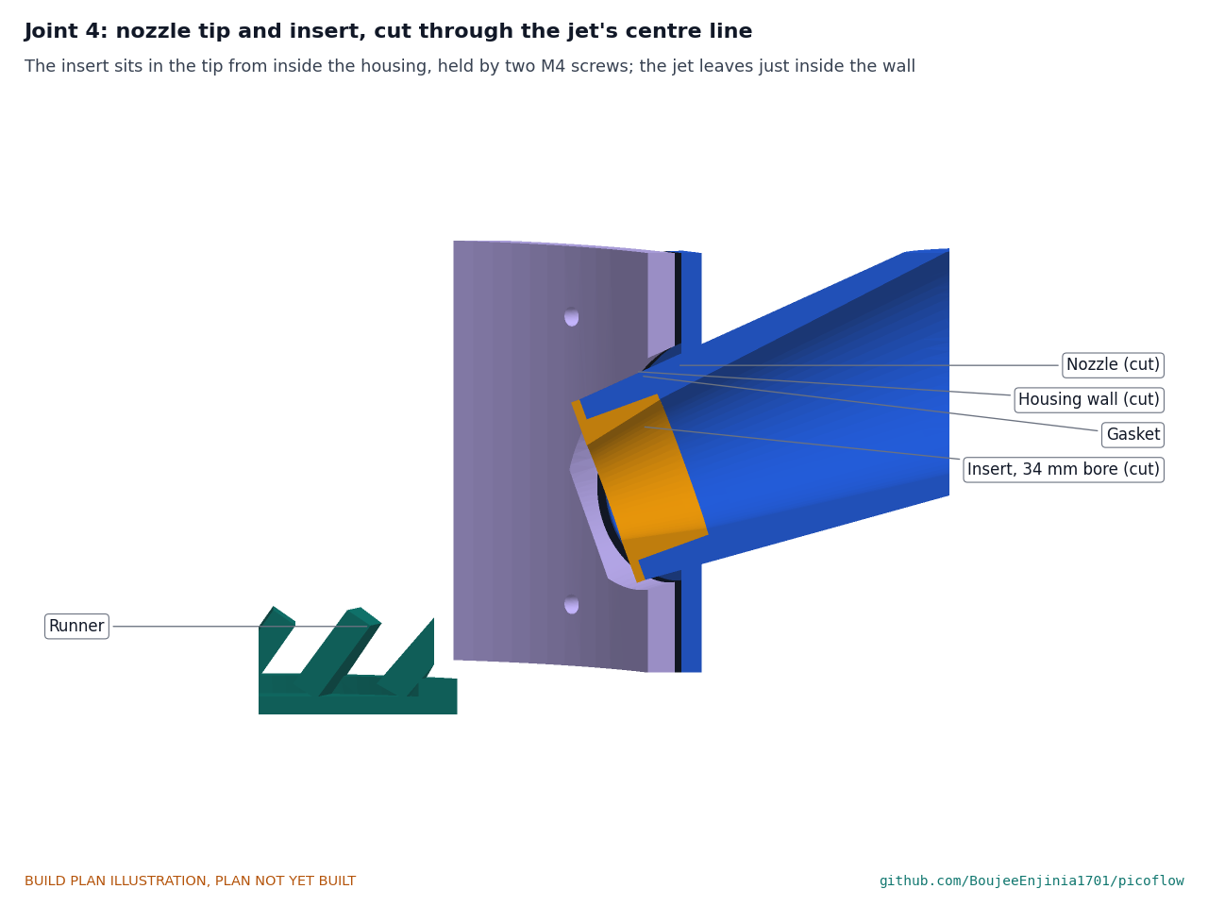
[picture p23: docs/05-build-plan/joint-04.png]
Figure 10. Joint 4: nozzle tip and insert


*Figure 10. The insert sits in the nozzle tip from inside the housing, its flange against the tip face, held by two M4 screws into the heat-set inserts.*

**Check before moving on.** Each insert seats fully and its screws pull it flat against the tip.

### 3.5 Lid

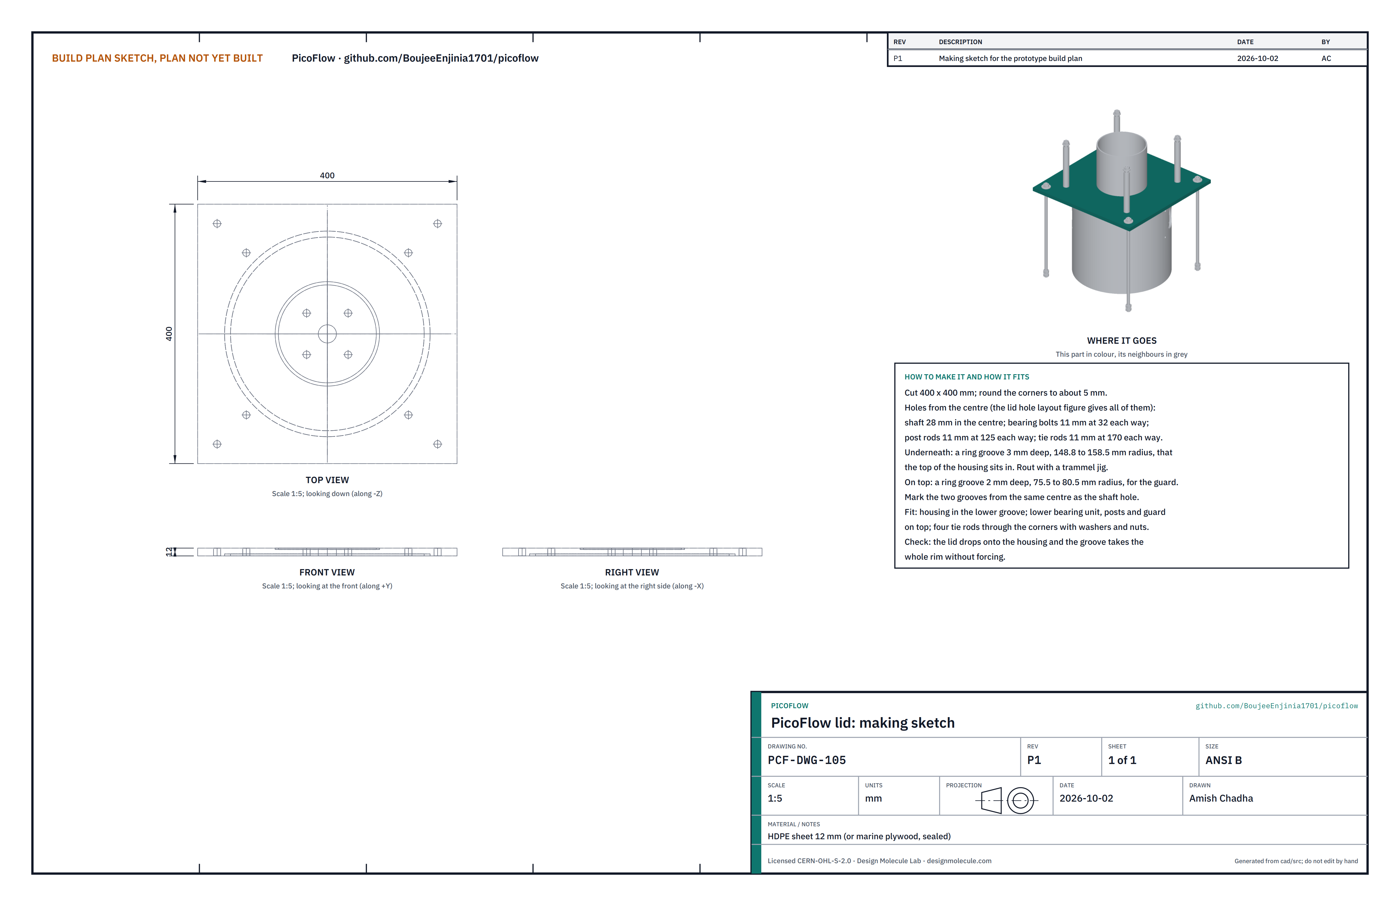
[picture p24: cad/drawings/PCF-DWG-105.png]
Figure 11. Making sketch of the lid


*Figure 11. Lid making sketch (PCF-DWG-105).*

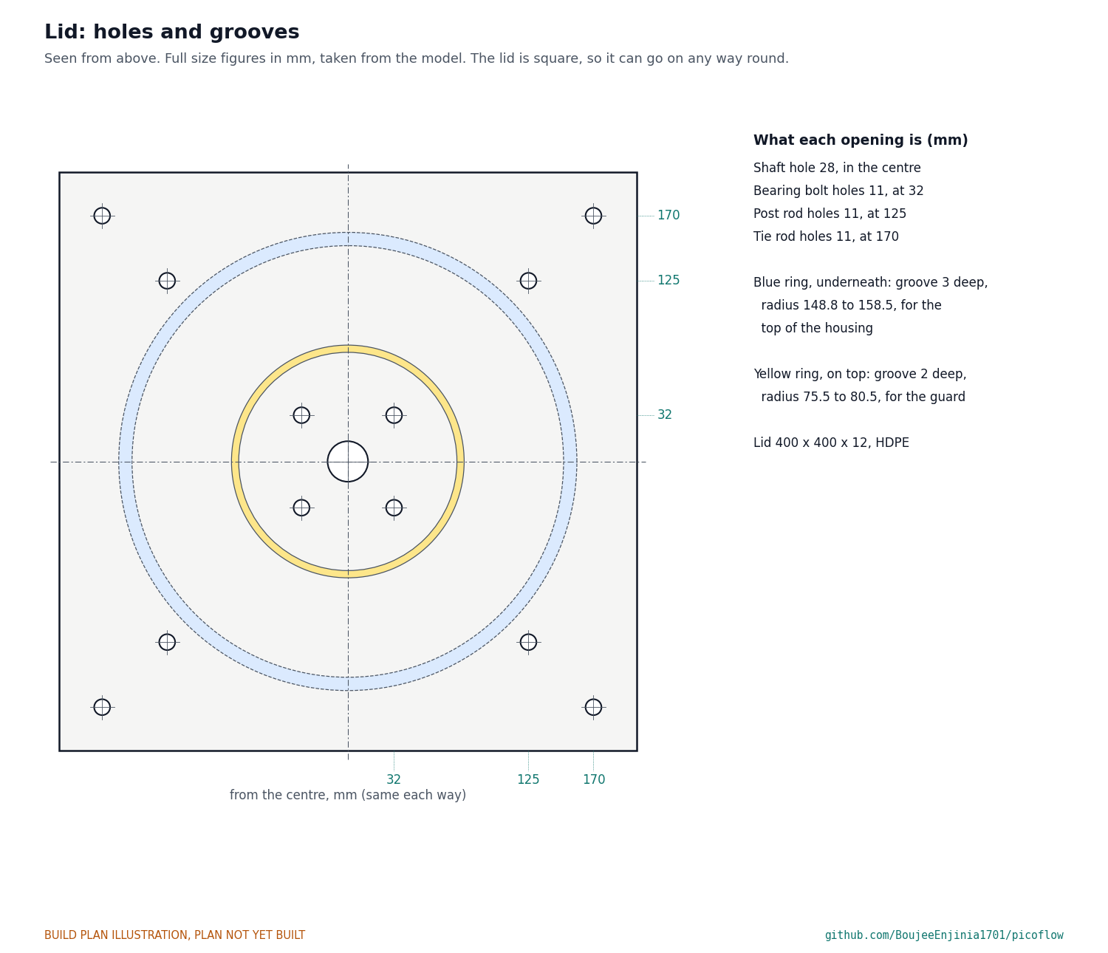
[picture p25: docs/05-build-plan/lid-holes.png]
Figure 12. Lid hole and groove layout


*Figure 12. Every hole and groove in the lid, measured from its centre.*

**What it is and what it is made from.** The square plate on top of the housing that carries the bearings, posts, guard and generator. HDPE sheet 12 mm (marine plywood, sealed, also works).

**How to make it.**

1. Cut 400 x 400 mm and round the corners to about 5 mm. Mark the centre from the diagonals.
2. Drill the holes from Figure 12: shaft 28 mm in the centre; bearing bolts 11 mm at 32 each way; post rods 11 mm at 125 each way; tie rods 11 mm at 170 each way.
3. Underneath, rout a ring groove 3 mm deep from 148.8 to 158.5 mm radius with a trammel jig pivoting in the centre hole.
4. On top, rout a ring groove 2 mm deep from 75.5 to 80.5 mm radius for the guard.

**How it fits the parts next to it.**

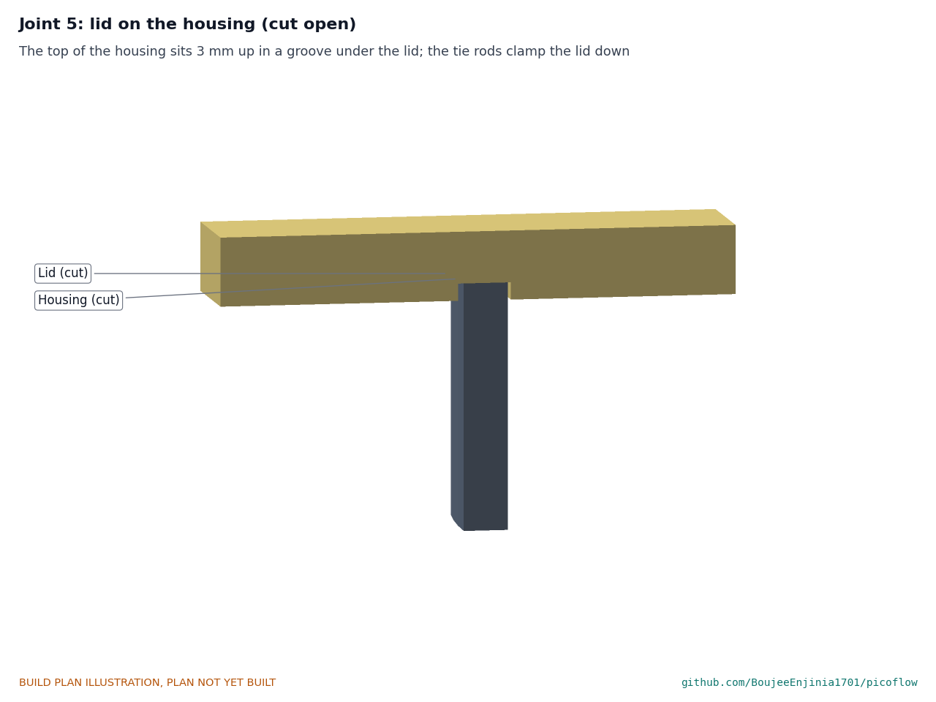
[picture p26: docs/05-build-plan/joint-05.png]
Figure 13. Joint 5: lid on the housing


*Figure 13. The top of the housing sits in the groove under the lid.*

The lid sits on the housing with its top 3 mm in the groove; the four tie rods come up through the corners and washers and nuts clamp it down (step 10).

**Check before moving on.** The lid drops onto the housing and the groove takes the whole rim without forcing.

### 3.6 Bearing units, spacer sleeves and V-ring

**What they are and what they are made from.** Two bought 4-bolt flange bearing units with a 20 mm bore (UCF204 class, sealed insert bearings), stacked on four 24 mm steel spacer sleeves and clamped to the lid by four M10 x 80 bolts. A rubber V-ring for a 20 mm shaft keeps spray off the lower bearing. The sleeves are cut with the posts (section 3.10).

**How to make it.** Nothing to make on the units. Check each turns freely and has both set screws.

**How it fits the parts next to it.**

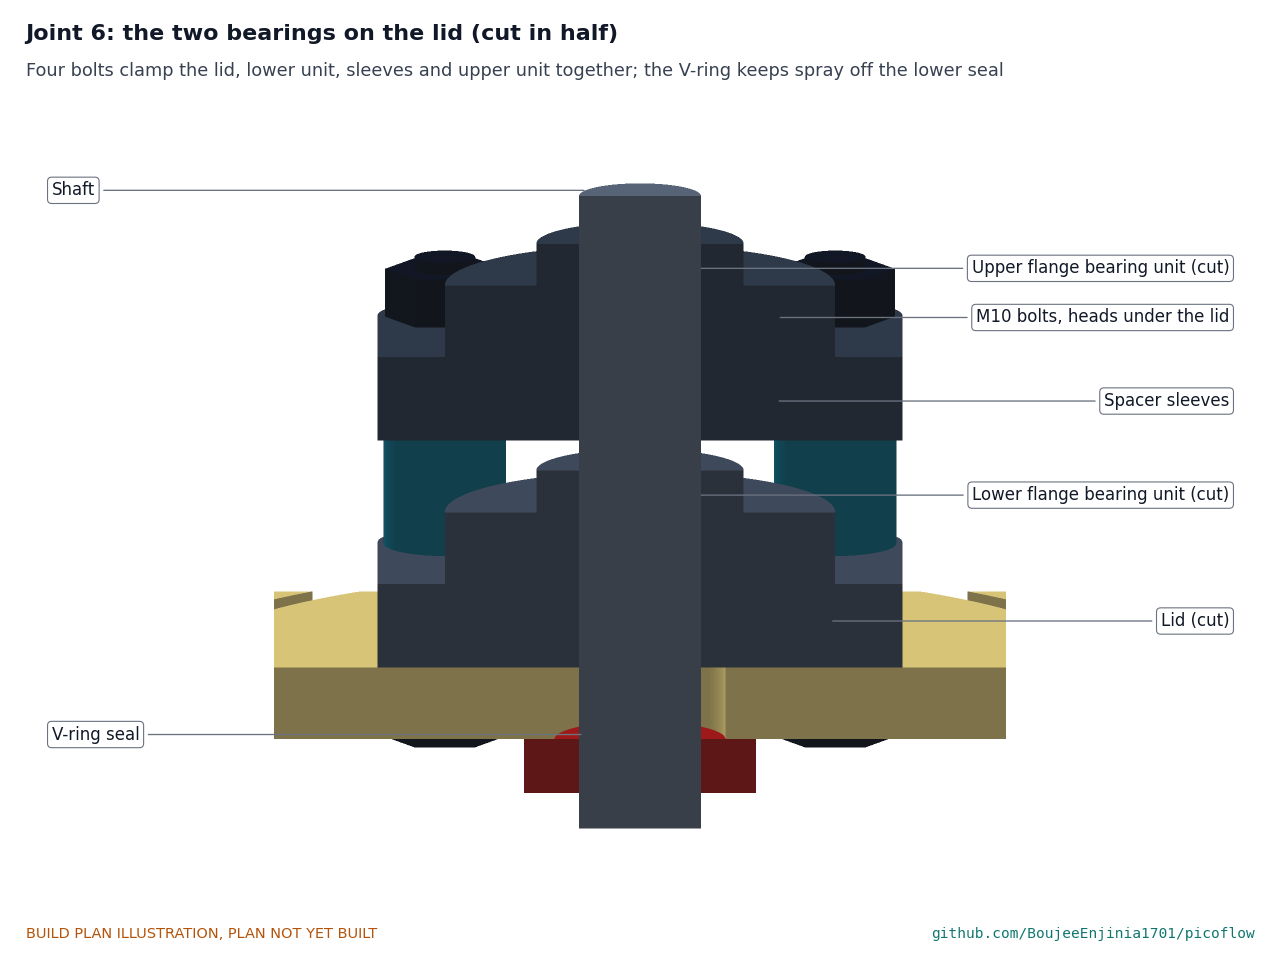
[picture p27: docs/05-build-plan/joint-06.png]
Figure 14. Joint 6: the two bearings on the lid


*Figure 14. The four bolts go up from under the lid through the lower unit, the sleeves and the upper unit; nuts on top. The V-ring sits on the shaft under the lid.*

The lower unit's flange sits on the lid top; the sleeves stand on its flange; the upper unit sits on the sleeves, 5 mm above the lower unit's insert. Both inserts face the same way. The V-ring is pushed up the shaft until its lip just touches the lid underside.

**Check before moving on.** With the bolts snug, a 20 mm bar slides through both units without binding.

### 3.7 Shaft

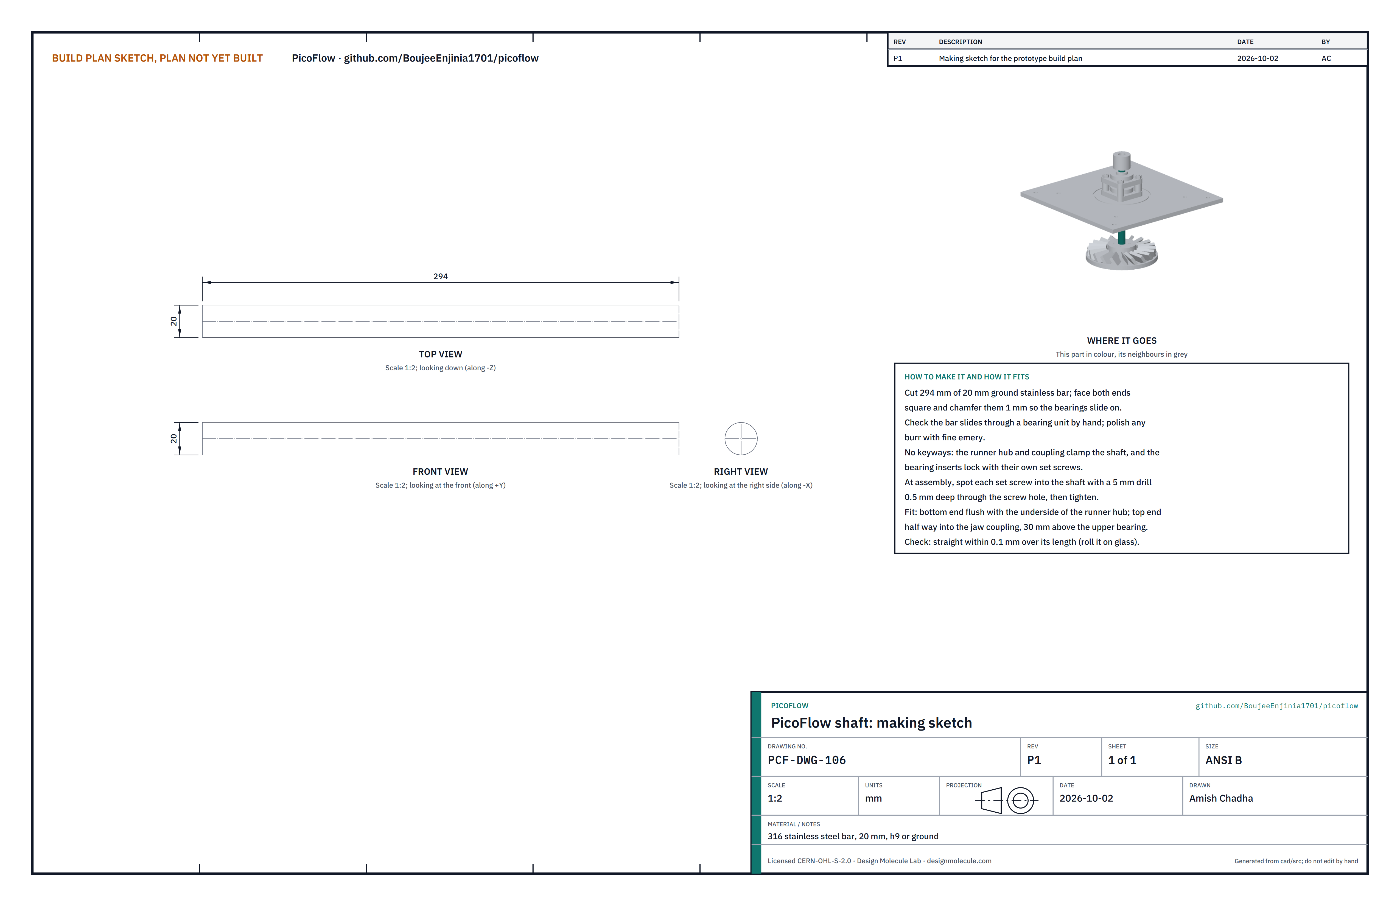
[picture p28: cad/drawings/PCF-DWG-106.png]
Figure 15. Making sketch of the shaft


*Figure 15. Shaft making sketch (PCF-DWG-106).*

**What it is and what it is made from.** The 20 mm stainless shaft from the runner up to the coupling. 316 stainless bar, ground or h9, 20 mm.

**How to make it.**

1. Cut 294 mm; face both ends square and chamfer them 1 mm.
2. Polish off any burr so it slides through the bearings by hand.
3. At assembly, spot each bearing set screw into the shaft with a 5 mm drill 0.5 mm deep through the screw hole, then tighten.

**How it fits the parts next to it.** The bottom end is flush with the underside of the runner hub (Figure 17); the top end is half way into the jaw coupling, 30 mm above the upper bearing (Figure 20).

**Check before moving on.** Straight within 0.1 mm over its length: roll it on a sheet of glass.

### 3.8 Turgo runner and clamping hub

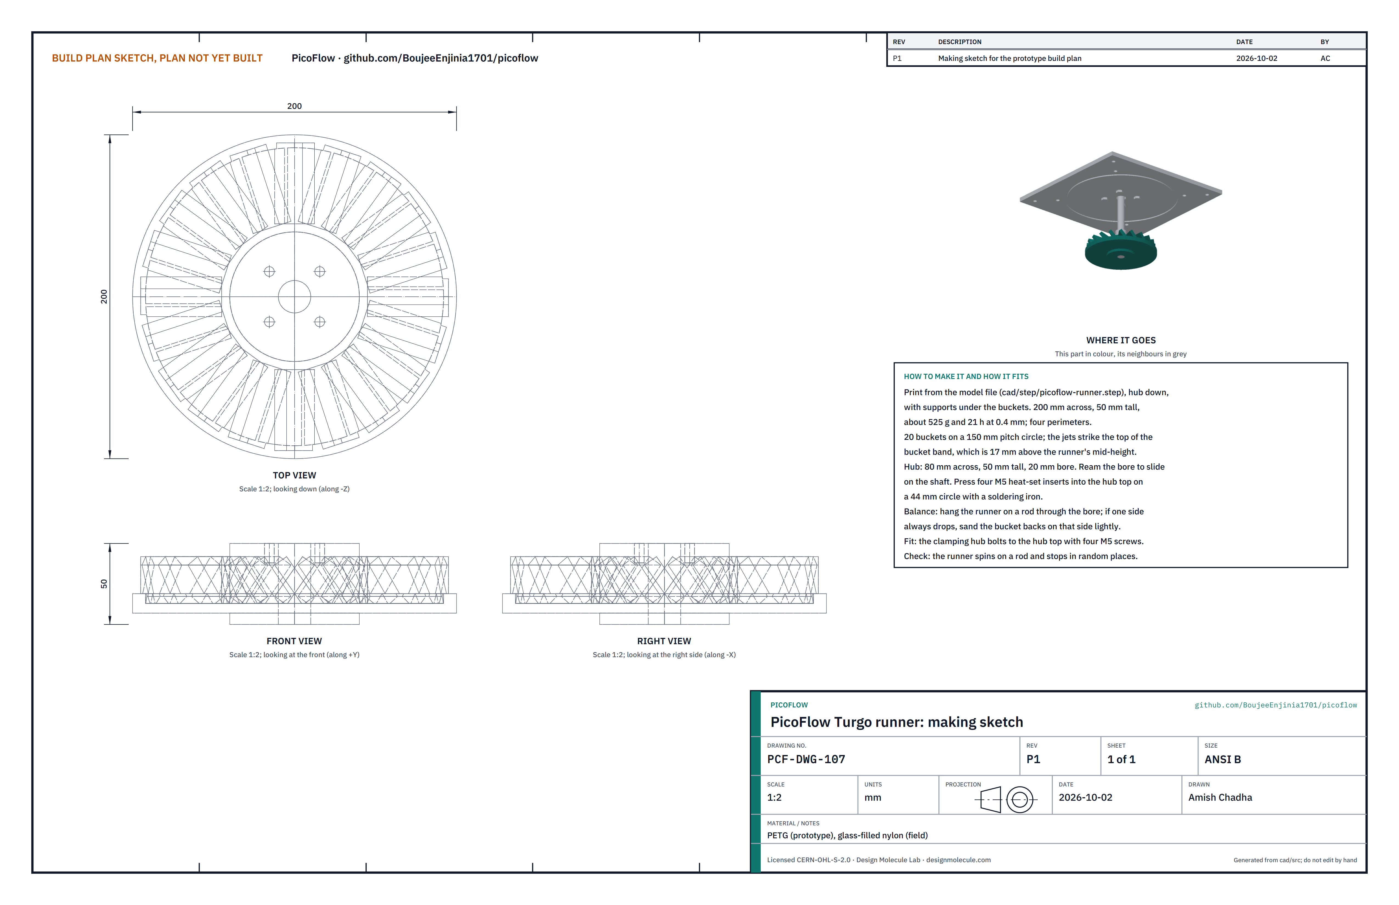
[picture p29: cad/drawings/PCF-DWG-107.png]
Figure 16. Making sketch of the runner


*Figure 16. Runner making sketch (PCF-DWG-107).*

**What it is and what it is made from.** The 200 mm printed runner with 20 buckets on a 150 mm pitch circle, and the bought clamping hub that fixes it to the shaft. PETG for the prototype (glass-filled nylon for field units); clamping shaft hub, 20 mm bore, 56 mm flange with four 5.5 mm holes.

**How to make it.**

1. Print the runner hub down, with supports under the buckets: about 525 g and 21 h at 0.4 mm, four perimeters.
2. Ream the bore to slide on the shaft.
3. Press four M5 heat-set inserts into the hub top on a 44 mm circle.
4. Balance: hang the runner on a rod through the bore. If one side always drops, sand the backs of the buckets on that side lightly until it stops in random places.

**How it fits the parts next to it.**

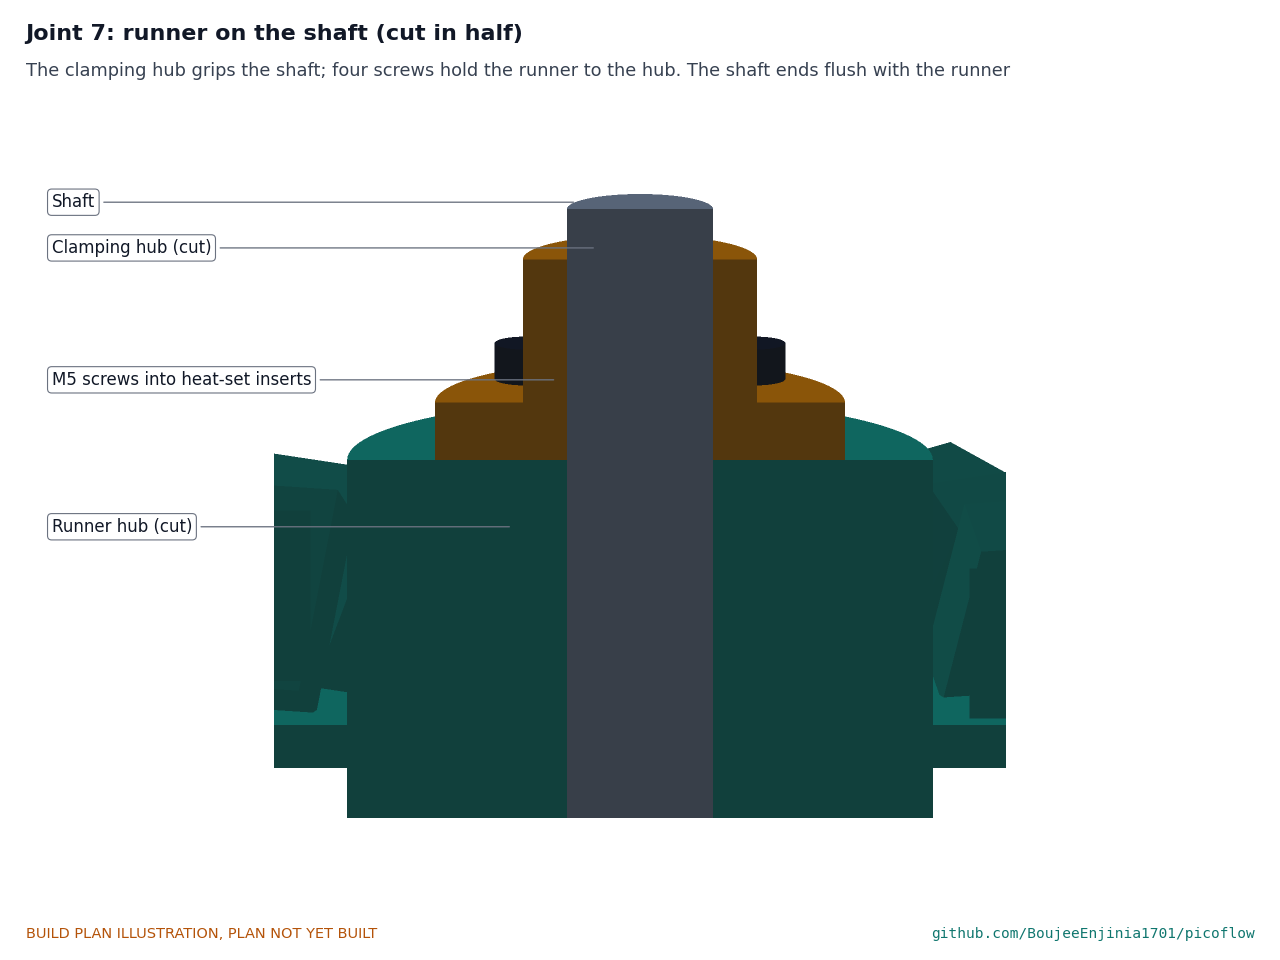
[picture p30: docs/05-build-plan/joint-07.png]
Figure 17. Joint 7: runner on the shaft


*Figure 17. The clamping hub grips the shaft; four M5 screws hold the runner to the hub.*

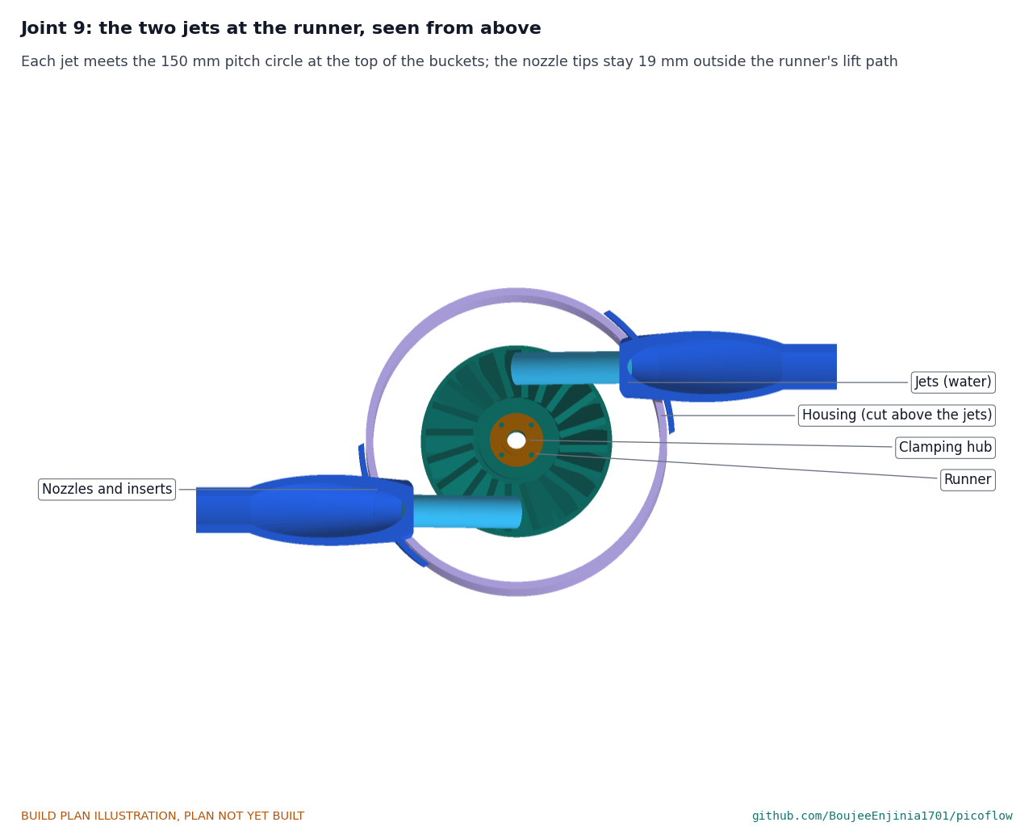
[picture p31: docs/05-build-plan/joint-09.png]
Figure 18. Joint 9: the two jets at the runner


*Figure 18. Seen from above: each jet meets the 150 mm pitch circle at the top of the buckets, and the nozzle tips stay 19 mm outside the circle the runner sweeps when it is lifted out.*

The hub's flange sits on the runner hub with four M5 screws into the heat-set inserts. The runner hangs 20 mm or more clear of everything round it: 50 mm from the housing, 46 mm from each nozzle, and 199 mm above normal tailwater.

**Check before moving on.** On the shaft, the runner spins freely and runs true within 1 mm at the rim.

### 3.9 Guard

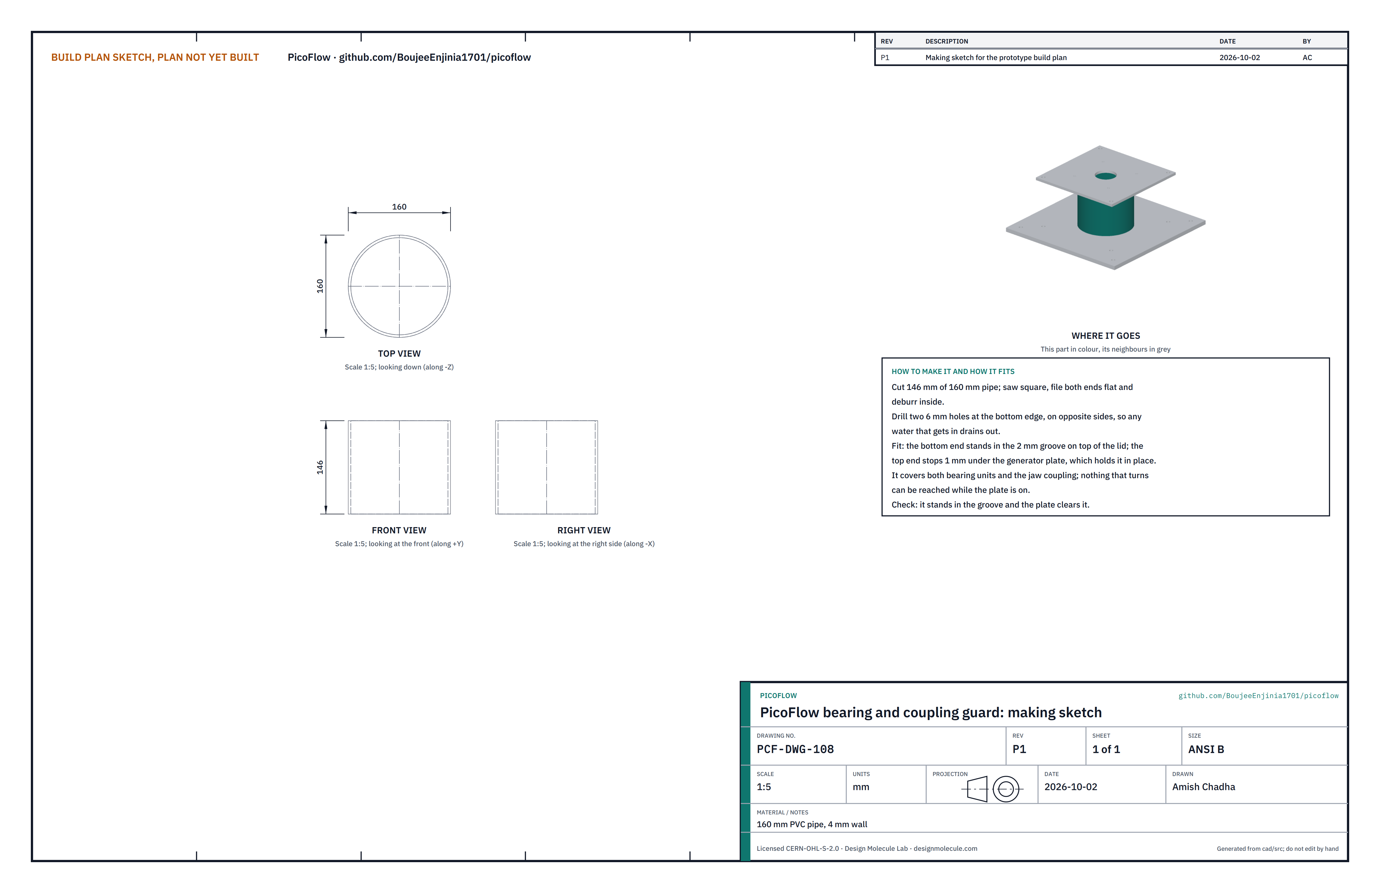
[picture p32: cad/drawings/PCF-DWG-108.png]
Figure 19. Making sketch of the guard


*Figure 19. Guard making sketch (PCF-DWG-108).*

**What it is and what it is made from.** A short tube that covers both bearing units and the jaw coupling. 160 mm PVC pipe, 4 mm wall. A clear polycarbonate tube of the same size may replace it; never acrylic, which is brittle and would crack under a coupling failure. With the PVC guard, check the coupling spider only with the turbine stopped and the generator plate off.

**How to make it.**

1. Cut 146 mm; saw square, file both ends flat and deburr inside.
2. Drill two 6 mm drain holes at the bottom edge, on opposite sides.

**How it fits the parts next to it.**

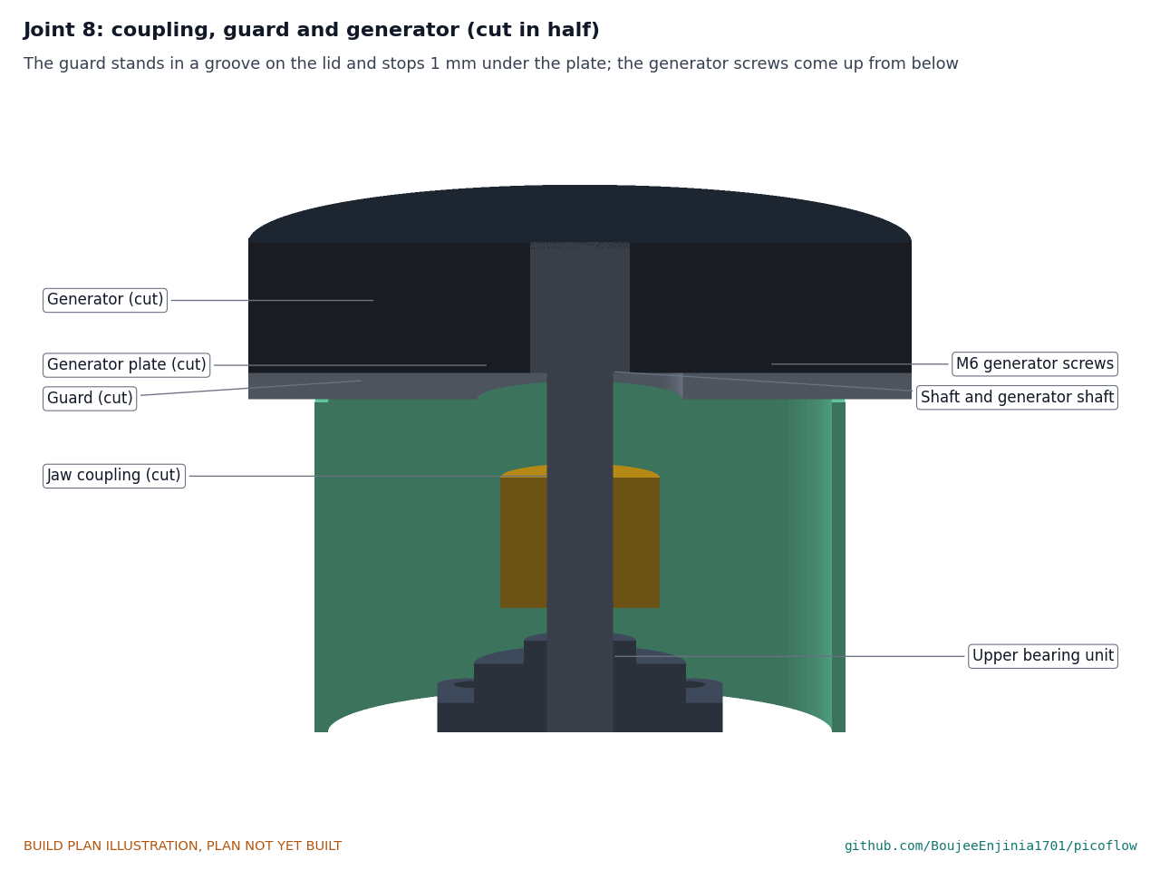
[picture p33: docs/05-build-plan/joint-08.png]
Figure 20. Joint 8: coupling, guard and generator


*Figure 20. The guard stands in the groove on the lid and stops 1 mm under the generator plate, which holds it in place.*

**Check before moving on.** It stands upright in the groove; the plate clears its top.

### 3.10 Posts, post rods, spacer sleeves and tie rods

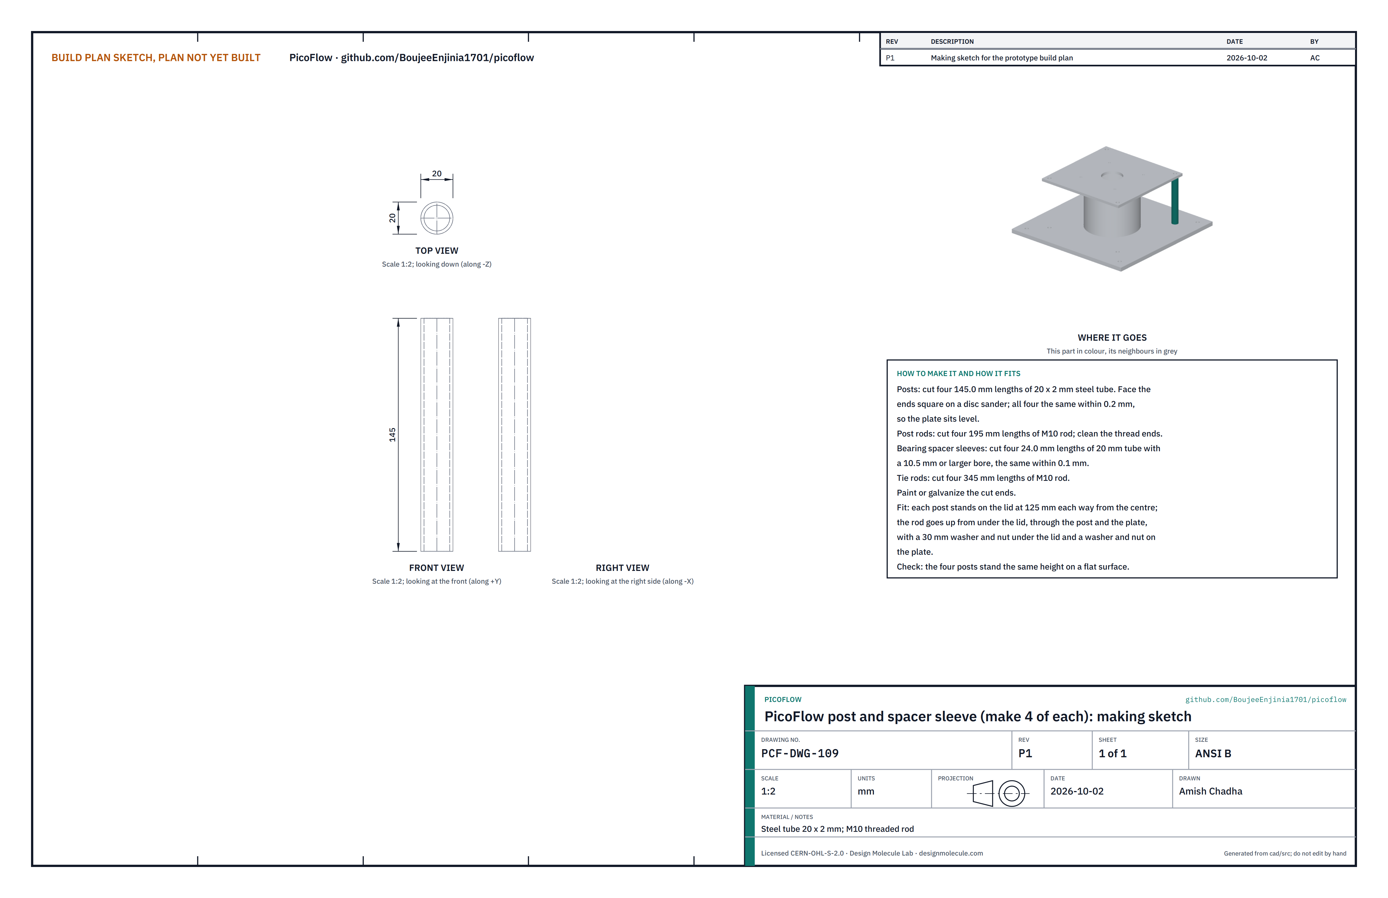
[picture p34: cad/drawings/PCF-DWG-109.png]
Figure 21. Making sketch of the post and spacer sleeve


*Figure 21. Post and spacer sleeve making sketch (PCF-DWG-109).*

**What they are and what they are made from.** Four posts that hold the generator plate 145 mm above the lid, each a steel tube on a threaded rod; the four short sleeves of the bearing stack; and the four tie rods from frame to lid. Steel tube 20 x 2 mm, 20 mm tube with a 10.5 mm or larger bore, and M10 threaded rod, stainless or galvanized.

**How to make it.**

1. Cut four posts 145.0 mm long; face the ends square on a disc sander, all four the same within 0.2 mm.
2. Cut four spacer sleeves 24.0 mm long, the same within 0.1 mm.
3. Cut four post rods 195 mm long and four tie rods 345 mm long from M10 rod. Clean the threads at the cut ends with a nut.
4. Paint or galvanize the cut ends.

**How it fits the parts next to it.**

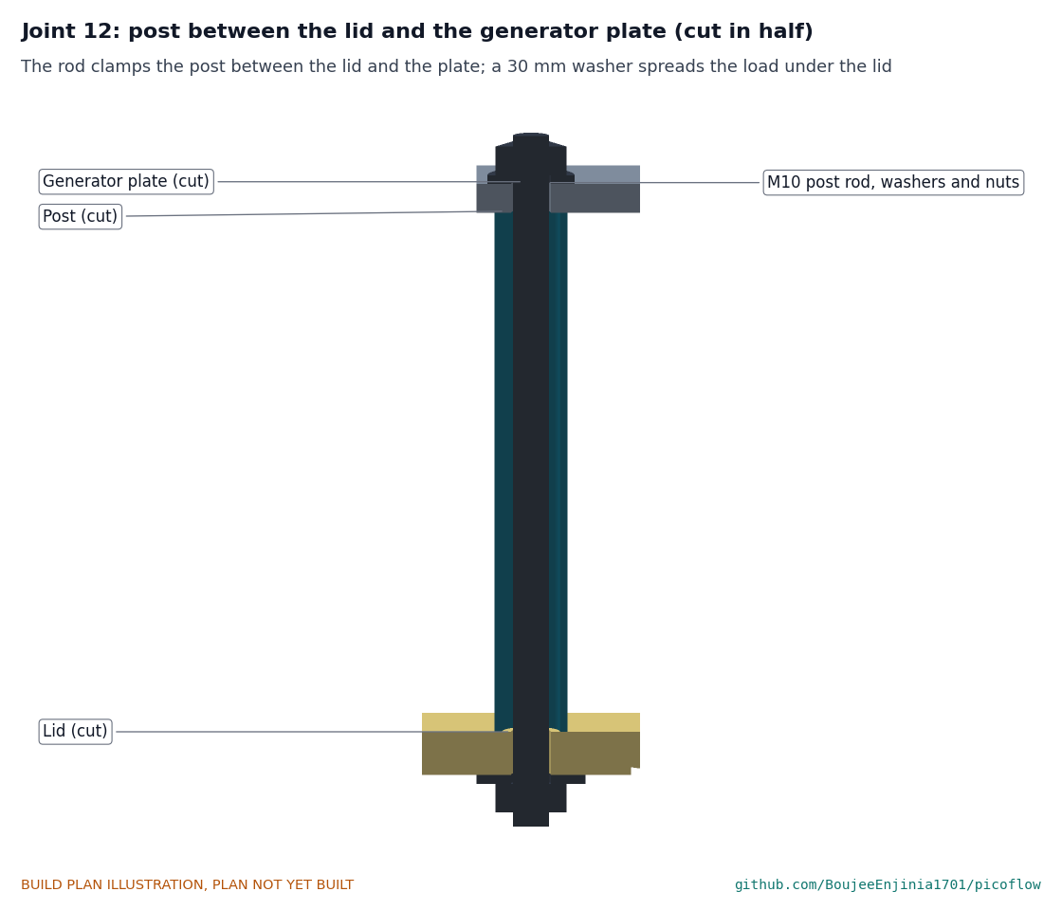
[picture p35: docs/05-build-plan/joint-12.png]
Figure 22. Joint 12: post between lid and generator plate


*Figure 22. The rod clamps the post between the lid and the plate; a 30 mm washer under the lid spreads the load.*

Each post stands on the lid 125 mm each way from the centre. Its rod goes up from under the lid, through the post and the plate, with a 30 mm washer and nut under the lid and a washer and nut on the plate. The washers under the lid clear the housing by 4 mm. Each tie rod stands 12 mm below the frame angle, locked by a nut above and below (Figure 3), and its top passes through the lid with a 30 mm washer and nut.

**Check before moving on.** The four posts stand the same height on a flat surface.

### 3.11 Generator plate

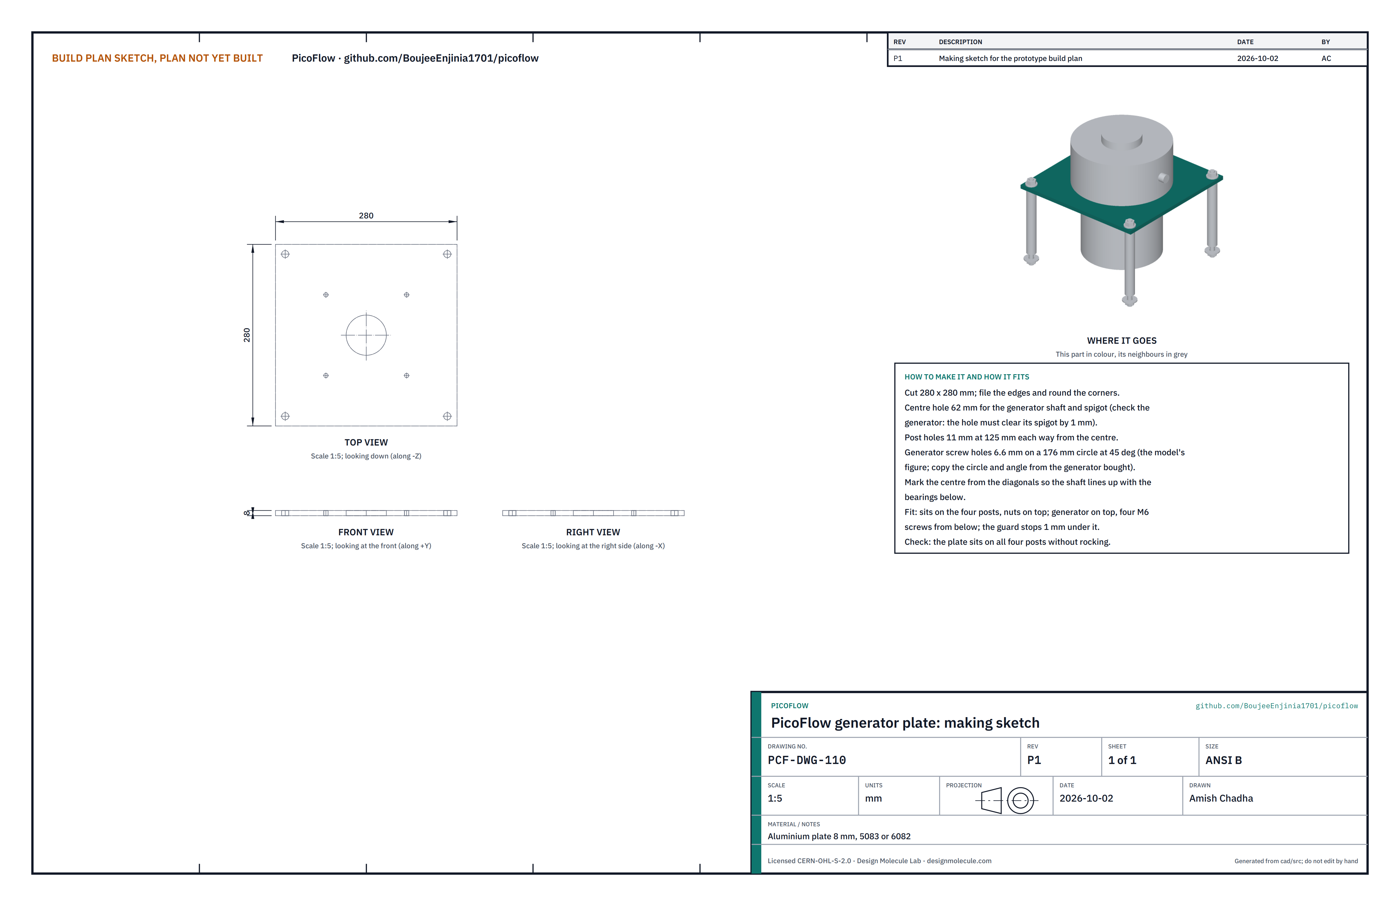
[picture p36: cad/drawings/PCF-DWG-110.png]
Figure 23. Making sketch of the generator plate


*Figure 23. Generator plate making sketch (PCF-DWG-110).*

**What it is and what it is made from.** The plate the generator stands on. Aluminium plate 8 mm, 5083 or 6082 class, 280 x 280 mm.

**How to make it.**

1. Cut 280 x 280 mm, file the edges and round the corners. Mark the centre from the diagonals.
2. Drill or cut a 62 mm centre hole for the generator's shaft and spigot (it must clear the spigot of the generator bought by 1 mm).
3. Drill four 11 mm post holes at 125 mm each way from the centre.
4. Drill four 6.6 mm generator screw holes on the screw circle of the generator bought (the model uses a 176 mm circle at 45°).

**How it fits the parts next to it.** The plate sits on the four posts, nuts on top; the generator stands on it, held by four M6 screws from below into its face; the guard stops 1 mm under it (Figure 20).

**Check before moving on.** The plate sits on all four posts without rocking, and its centre hole lines up over the shaft.

### 3.12 Pipe stands (make 3)

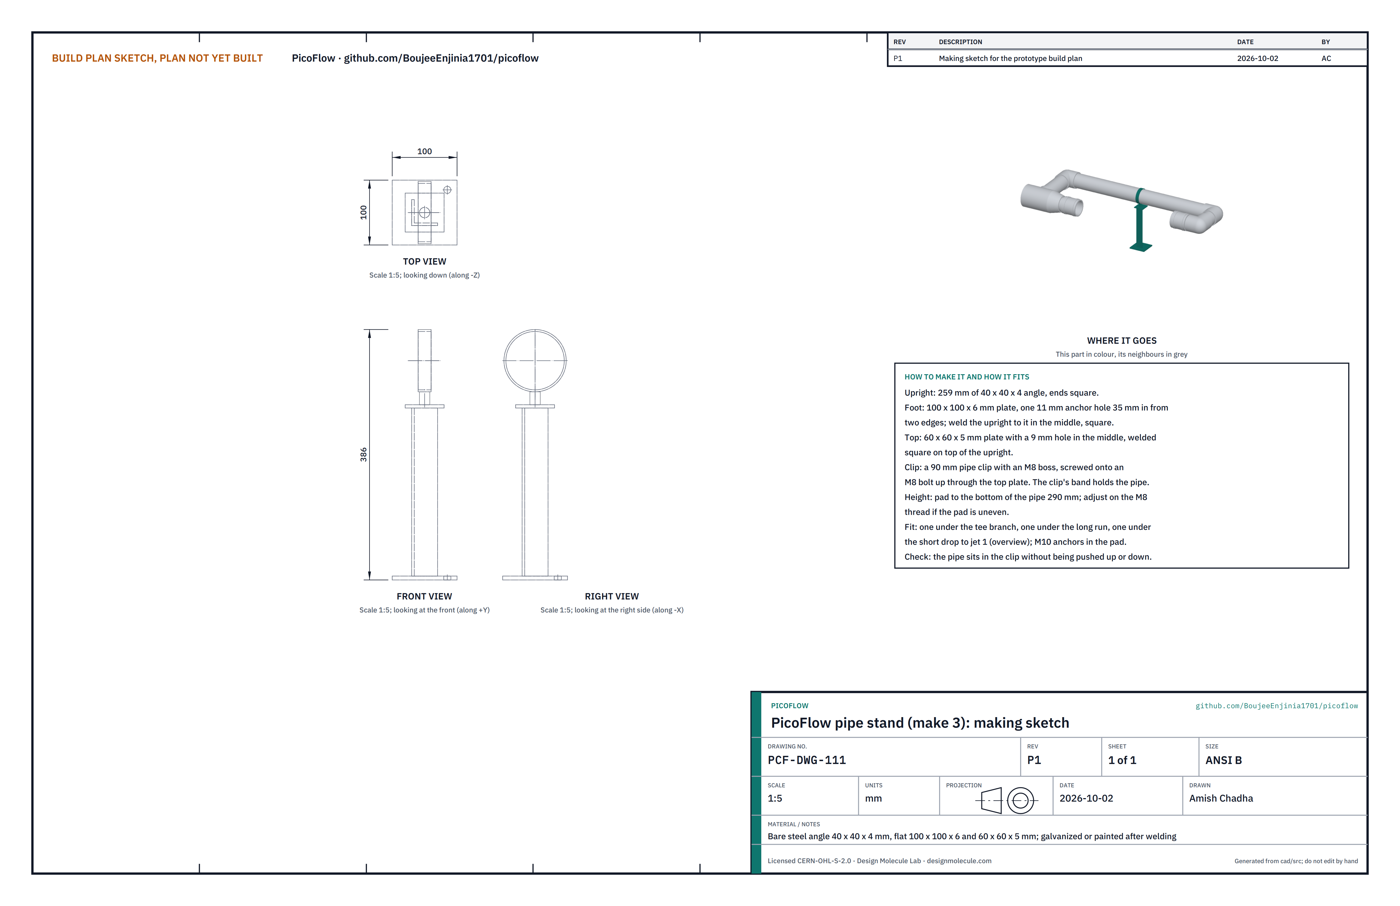
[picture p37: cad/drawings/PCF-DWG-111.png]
Figure 24. Making sketch of the pipe stand


*Figure 24. Pipe stand making sketch (PCF-DWG-111).*

**What it is and what it is made from.** A short steel stand with a pipe clip that carries the branch pipework at the nozzle height. Bare steel angle 40 x 40 x 4 mm, galvanized or painted after welding, flat bar 100 x 6 mm and 60 x 5 mm, a 90 mm pipe clip with an M8 boss.

**How to make it.**

1. Cut a 259 mm upright from angle and a 100 x 100 mm foot from 6 mm flat bar; drill an 11 mm anchor hole in the foot, 35 mm in from two edges.
2. Weld the upright square in the middle of the foot.
3. Cut a 60 x 60 mm top plate from 5 mm flat bar, drill 9 mm in the middle and weld it square on top of the upright.
4. Galvanize or paint the stand once it is welded, never before.
5. Put an M8 bolt up through the top plate and screw the clip's boss onto it.

**How it fits the parts next to it.**

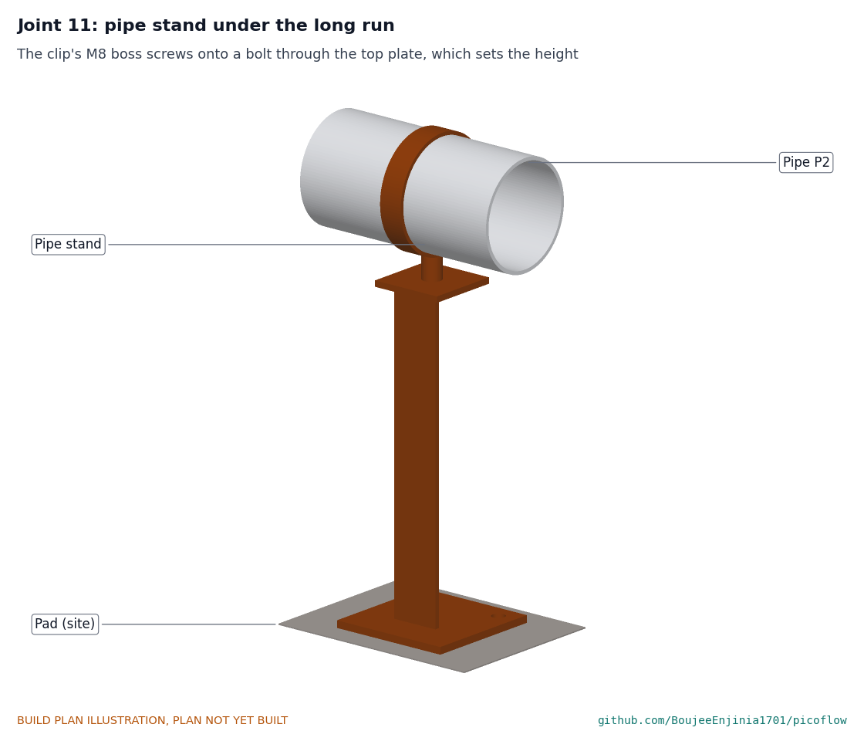
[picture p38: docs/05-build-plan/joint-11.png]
Figure 25. Joint 11: pipe stand under the long run


*Figure 25. The clip's band holds the pipe; turning the clip on its M8 bolt sets the height.*

One stand goes under the tee branch, one under the long run behind the housing and one under the short drop to jet 1 (Figure 1). The bottom of the pipe is 290 mm above the pad.

**Check before moving on.** The pipe sits in each clip without being pushed up or pulled down.

### 3.13 Nozzle manifold pipework

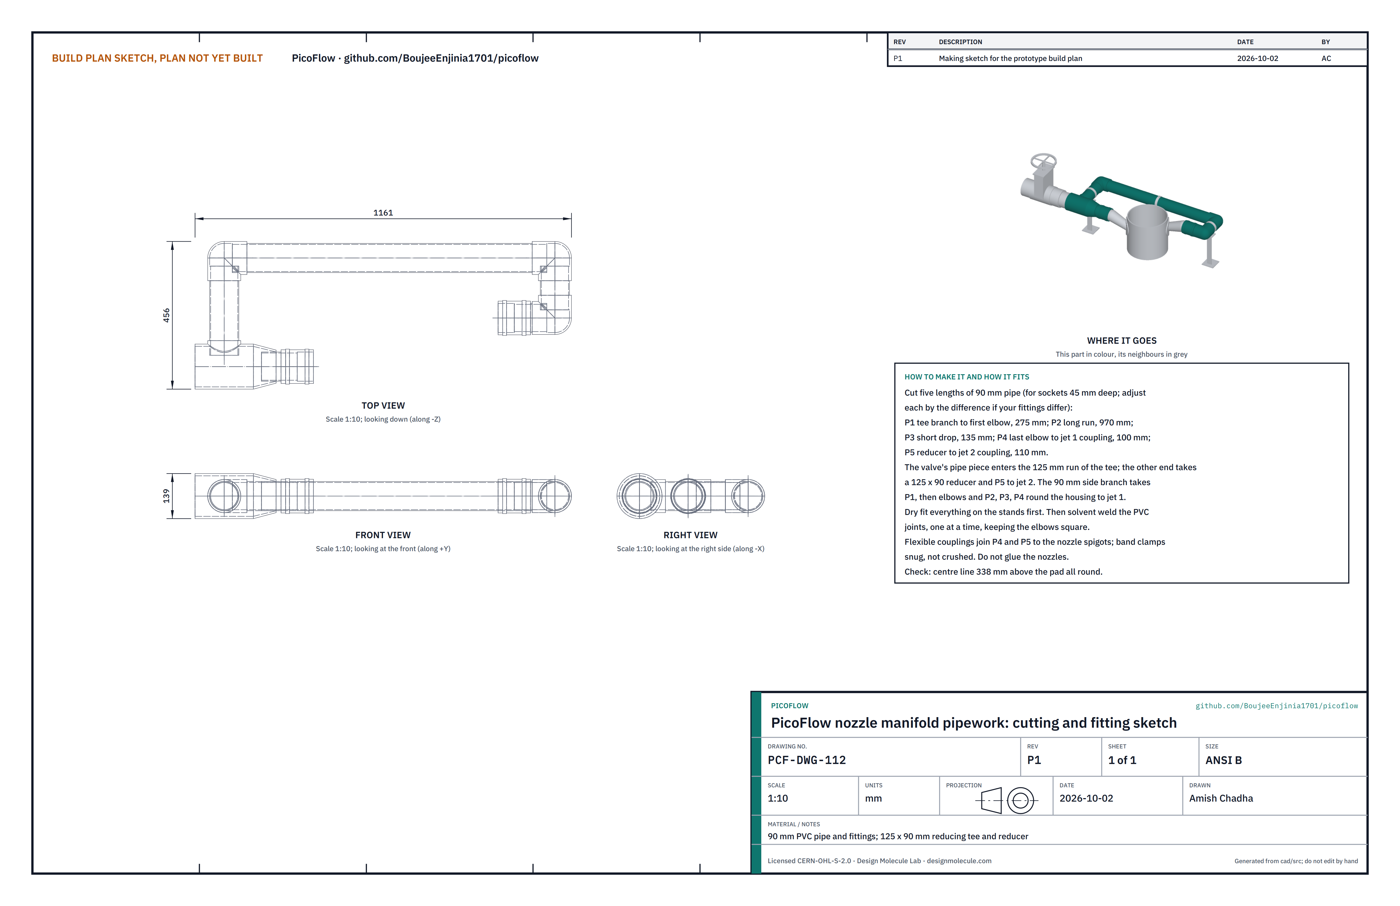
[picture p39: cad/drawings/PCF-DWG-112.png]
Figure 26. Cutting and fitting sketch of the pipework


*Figure 26. Pipework cutting and fitting sketch (PCF-DWG-112).*

**What it is and what it is made from.** The fittings and pipes that split the flow from the penstock to the two nozzles. A 125 x 90 mm reducing tee, a 125 x 90 mm reducer, three 90° elbows, about 1.6 m of 90 mm PVC pipe and two 90 mm flexible rubber couplings with band clamps.

**How to make it.**

1. Cut five lengths of 90 mm pipe, square and deburred, for fittings with 45 mm sockets (adjust each by the difference if yours differ): P1, tee branch to the first elbow, 275 mm; P2, the long run behind the housing, 970 mm; P3, the short drop, 135 mm; P4, last elbow to the jet 1 coupling, 100 mm; P5, reducer to the jet 2 coupling, 110 mm.
2. Dry fit everything on the stands with the nozzles in place: the valve's pipe piece (section 3.14) enters one end of the tee's 125 mm run; the other end takes the reducer and P5 to jet 2; the 90 mm side branch takes P1, an elbow, P2, an elbow, P3, an elbow and P4 to jet 1.
3. Mark each joint across both parts so it goes back the same way, then solvent weld the PVC joints one at a time, keeping the elbows square. Never glue a nozzle.

**How it fits the parts next to it.**

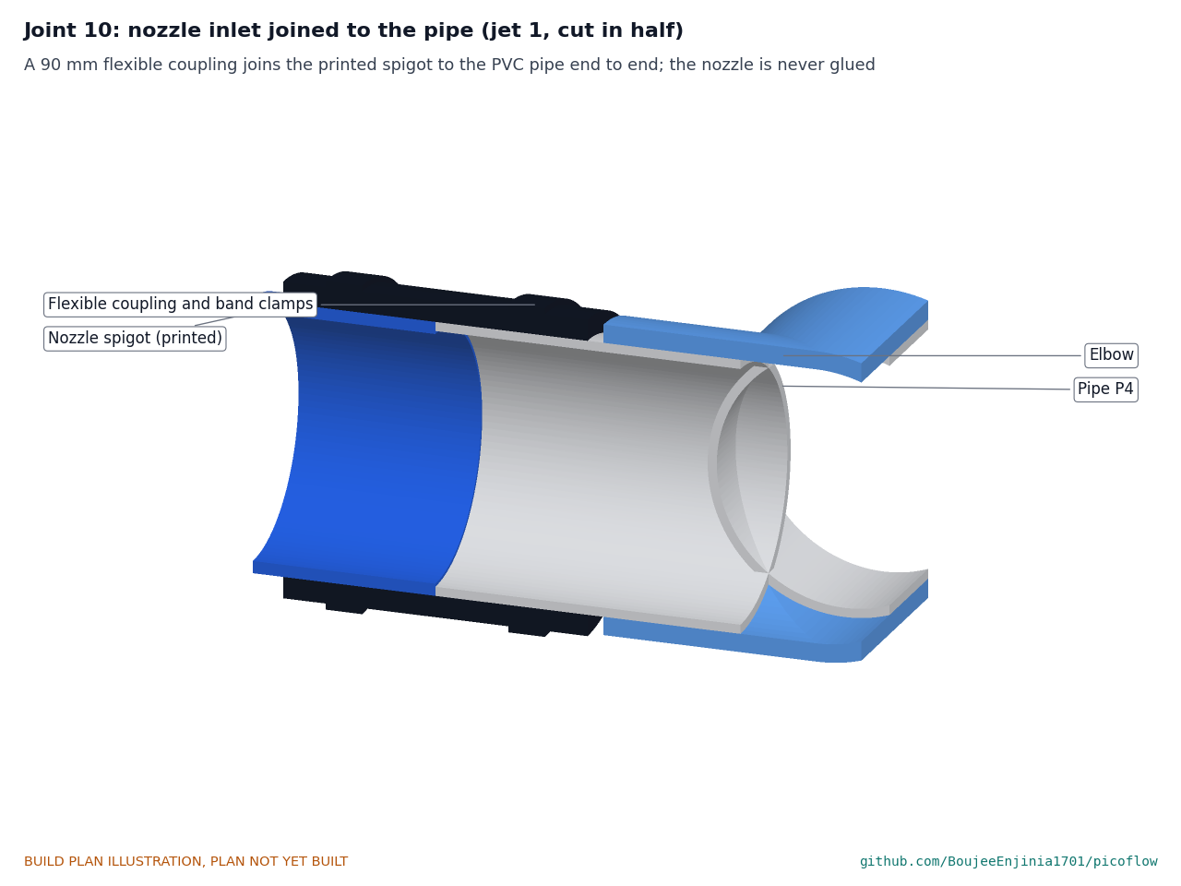
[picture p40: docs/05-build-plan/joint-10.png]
Figure 27. Joint 10: nozzle inlet joined to the pipe


*Figure 27. A flexible coupling joins the printed spigot to the end of P4 (or P5), end to end; two band clamps hold it.*

The pipework centre line is 338 mm above the pad all round, the height of the nozzle spigots. It sits in the three stand clips and joins each nozzle through a flexible coupling, band clamps snug but not crushing the printed spigot.

**Check before moving on.** Dry fitted, the pipework reaches both spigots with no strain and the centre line is level within 3 mm.

### 3.14 Inlet valve and its pipe piece

**What they are and what they are made from.** A bought full-bore 125 mm PVC-U gate valve, multi-turn with a handwheel so it cannot close in under about 10 s, with a solvent-weld socket for 125 mm pipe at each end. The one drawn is about 330 mm long over its sockets, with 70 mm deep sockets, a 200 mm handwheel whose top is about 300 mm above the pipe centre line, and a mass of about 5.5 kg. A 175 mm piece of the 125 mm penstock pipe joins it to the tee.

**How to make it.**

1. Before cutting, measure the valve's socket depth and the depth of the tee's 125 mm socket. Cut the pipe piece from the penstock pipe, square and deburred, to 60 mm plus both socket depths: 175 mm for a 70 mm valve socket and a 45 mm tee socket. The 60 mm is the clear gap between the valve and the tee, which leaves room to turn the handwheel and to cut the line out later.
2. Chamfer both ends of the pipe piece and the end of the penstock lightly, so they slide into the sockets without pushing the cement off.
3. Count the turns from open to closed and write the number on the handwheel; it should be about ten. Look through the open valve: the gate must lift clear of the bore.

**How it fits the parts next to it.**

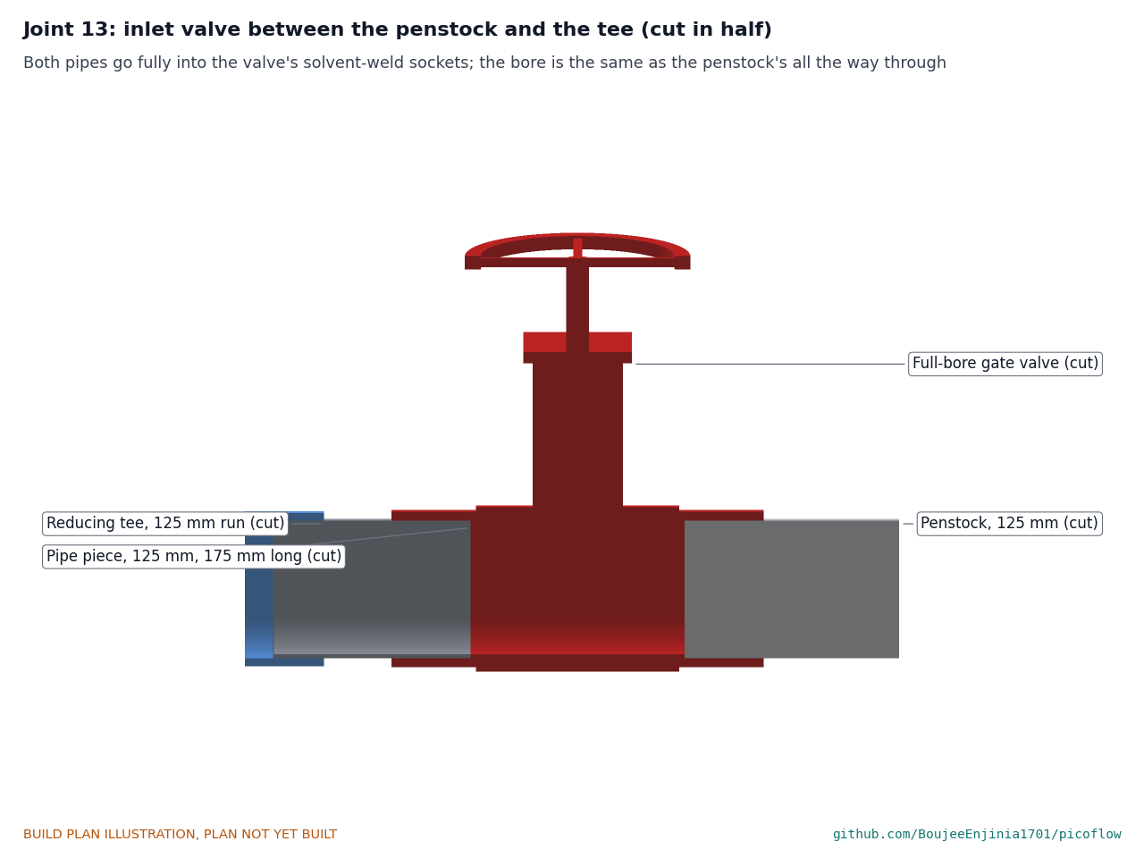
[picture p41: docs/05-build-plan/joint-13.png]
Figure 28. Joint 13: inlet valve between the penstock and the tee


*Figure 28. The pipe piece goes fully into the tee's free 125 mm socket and the valve's downstream socket; the penstock goes fully into the valve's upstream socket. The bore is 117 to 118 mm all the way through.*

The pipe piece is solvent welded into the free end of the tee's 125 mm run and into the valve's downstream socket; the penstock is solvent welded into the valve's upstream socket (step 17). No reducer or expander is needed. The valve stem stands straight up so the handwheel is easy to reach and clears the pipework by 60 mm. The valve is heavier than the pipe either side, so the penstock's own site support goes within 300 mm of the valve's upstream socket, and the stand under the tee branch carries the downstream side.

**Check before moving on.** The valve opens and closes fully, takes about ten turns, and the pipe piece and penstock each go fully home in their sockets when dry fitted.

### 3.15 Forebay tub and intake screen

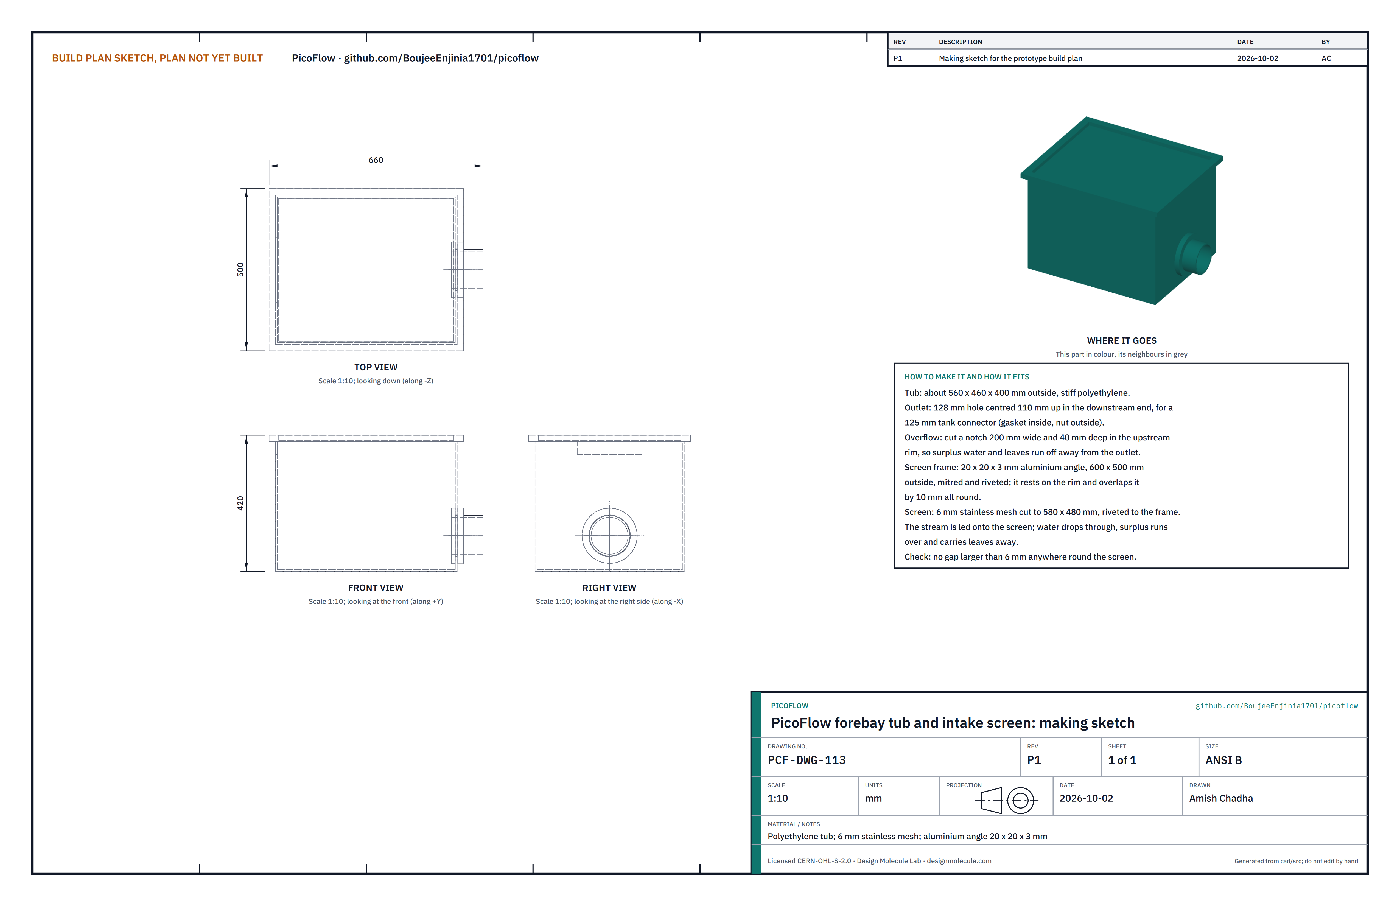
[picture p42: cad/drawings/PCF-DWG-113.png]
Figure 29. Making sketch of the forebay


*Figure 29. Forebay making sketch (PCF-DWG-113).*

**What it is and what it is made from.** The tub at the top of the drop that settles sand and screens the water before it enters the penstock. A stiff polyethylene tub about 560 x 460 x 400 mm, a 125 mm tank connector, 6 mm stainless mesh and 20 x 20 x 3 mm aluminium angle.

**How to make it.**

1. Cut a 128 mm hole centred 110 mm up in the downstream end and fit the tank connector, gasket inside, nut outside.
2. Cut an overflow notch 200 mm wide and 40 mm deep in the upstream rim.
3. Make a 600 x 500 mm frame from mitred angle, riveted at the corners; rivet a 580 x 480 mm piece of mesh to it.

**How it fits the parts next to it.** The screen frame rests on the rim and overlaps it 10 mm all round. The stream is led onto the screen; water drops through, and surplus runs over and carries leaves away. The penstock joins the tank connector.

**Check before moving on.** No gap larger than 6 mm anywhere round the screen.

### 3.16 Equipment post and electrics

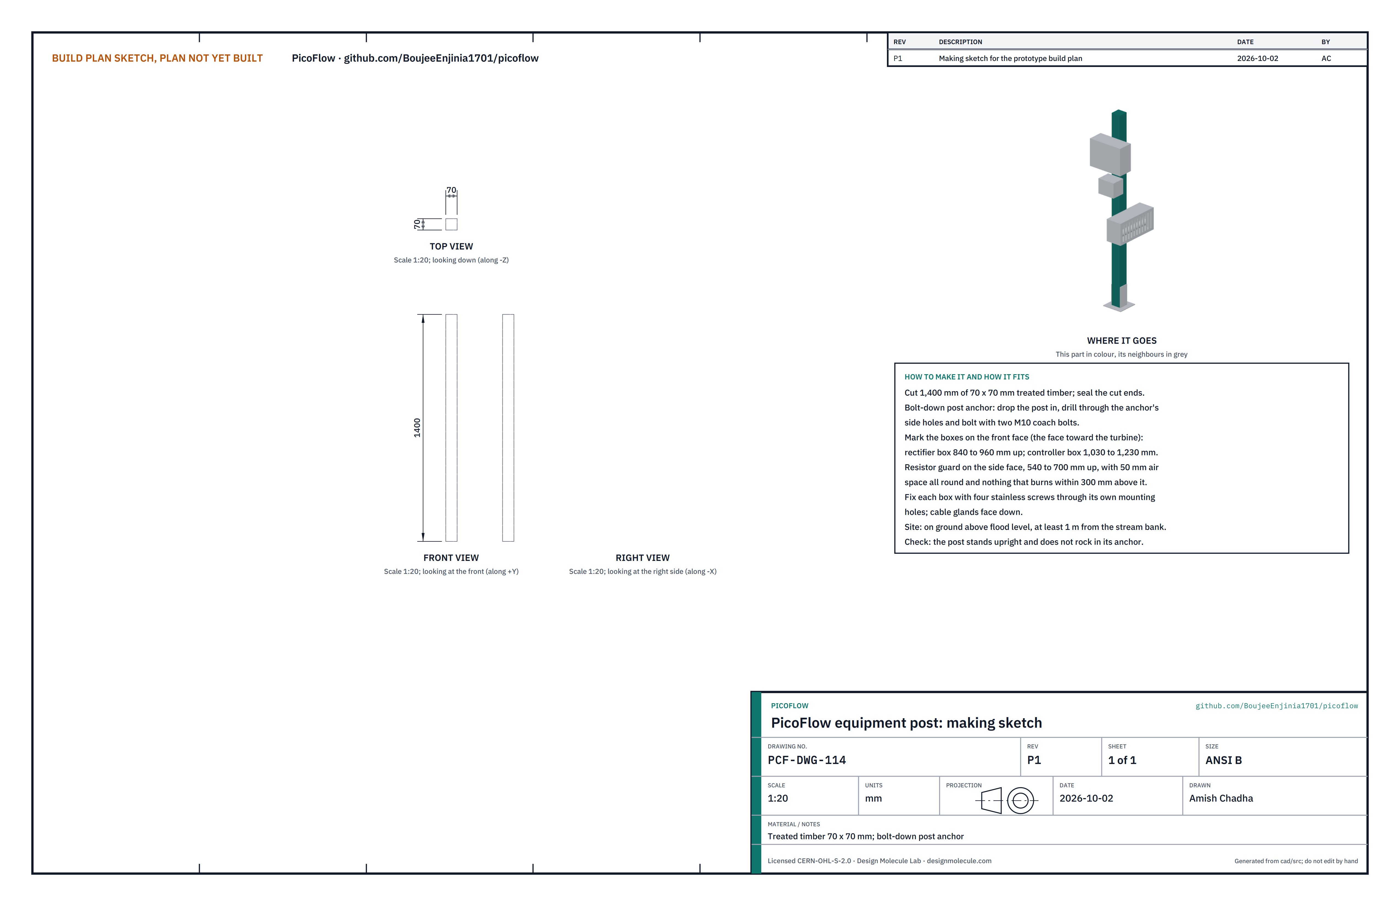
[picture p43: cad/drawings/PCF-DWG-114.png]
Figure 30. Making sketch of the equipment post


*Figure 30. Equipment post making sketch (PCF-DWG-114).*

**What it is and what it is made from.** A timber post beside the turbine that carries the rectifier box, the controller box and the guarded resistors, out of the spray and above flood level. Treated timber 70 x 70 mm, 1.4 m, in a bolt-down post anchor.

**How to make it.**

1. Cut the post, seal the cut ends and bolt it into its anchor with two M10 coach bolts.
2. Mark the boxes on the face toward the turbine: rectifier box 840 to 960 mm up, controller box 1,030 to 1,230 mm up.
3. Mark the resistor guard on the side face, 540 to 700 mm up, with 50 mm of air all round and nothing that burns within 300 mm above it.
4. Fit each box on four stainless screws through its own mounting holes, cable glands facing down.

#### 3.16.1 Wiring

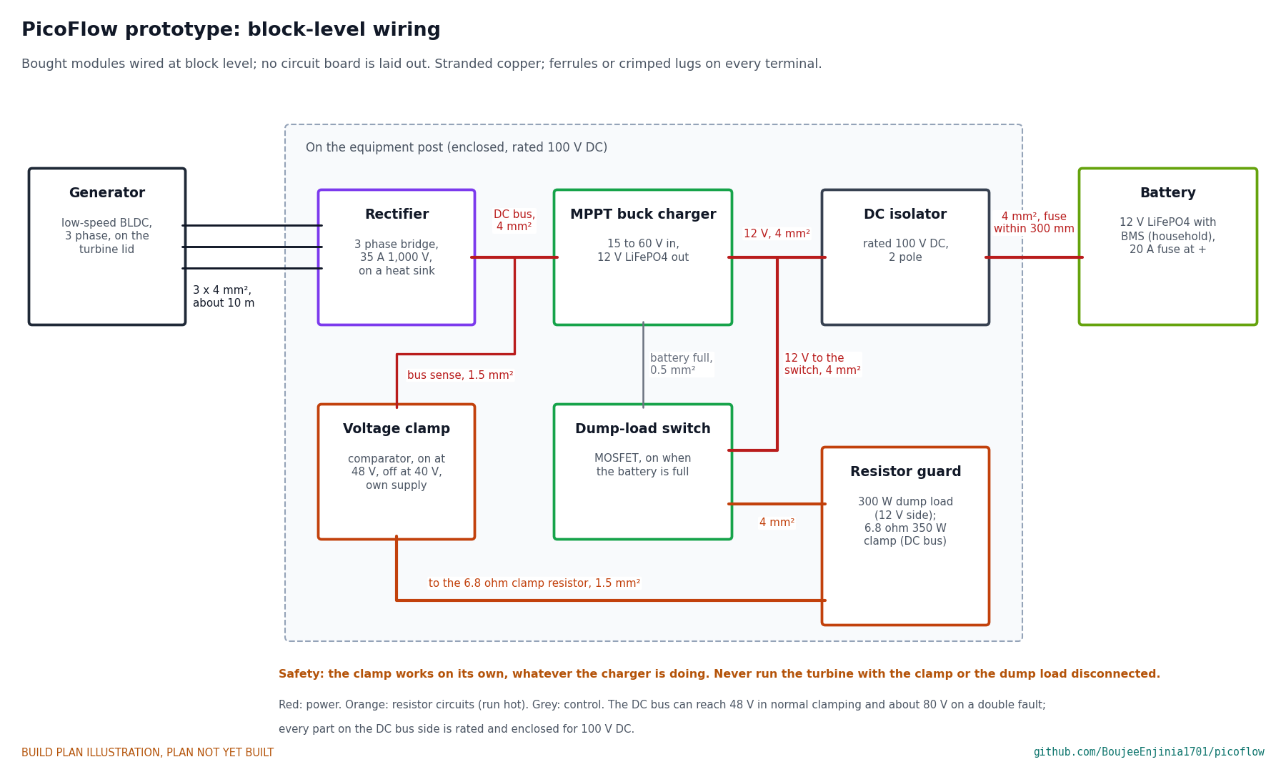
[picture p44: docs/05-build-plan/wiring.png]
Figure 31. Block-level wiring


*Figure 31. Block-level wiring with wire sizes. No circuit board is laid out at this stage; bought modules stand in for the controller board.*

The controller in the bill of materials is an open-design board, laid out at TRL 4. For this prototype, buy modules that meet this specification:

*Table 2. Modules that stand in for the controller board.*

| Module | What to buy |
| --- | --- |
| Rectifier | Three-phase bridge, 35 A, 1,000 V, on an aluminium heat sink in a vented box |
| Charger | Synchronous buck charge controller with input-voltage (maximum power point) regulation, 15 to 60 V in, a 12 V LiFePO4 charge profile, and a battery-full output |
| Dump-load switch | MOSFET switch module rated 30 A at 12 V, driven by the charger's battery-full output |
| Voltage clamp | A comparator module with its own supply from the DC bus, on at 48 V and off at 40 V, driving a MOSFET or DC solid-state relay rated 100 V and 10 A that switches the 6.8 ohm clamp resistor across the bus, with no connection to the charger's control |
| Resistors | A 300 W, 12 V heating element or wire-wound dump load and a 6.8 ohm aluminium-clad clamp resistor rated 350 W or more, both on a heat sink inside a vented steel guard |
| Isolation | A 2-pole DC isolator rated 100 V, a 20 A fuse within 300 mm of the battery positive, cable glands |

Wire it like this, with stranded copper and a crimped lug or ferrule on every terminal:

1. Generator to rectifier, three phases: 4 mm², about 10 m, in a conduit along the pipework.
2. Rectifier to the charger input (the DC bus): 4 mm².
3. DC bus to the voltage clamp's sense input: 1.5 mm². Clamp switch to the 6.8 ohm resistor: 1.5 mm².
4. Charger output (12 V) to the DC isolator and on to the battery, with the 20 A fuse within 300 mm of the battery: 4 mm².
5. Charger output to the dump-load switch and on to the dump load: 4 mm².
6. Charger battery-full signal to the dump-load switch: 0.5 mm².

**Check before moving on.** Every wire continues end to end; with the battery fuse out and the generator disconnected, nothing on the DC bus reads below 1 kΩ to the post or the frame.

### 3.17 Bought components

Buy to specification, not brand. Line numbers are those of the bill of materials.

- **Shaft and hub (line 2).** 20 mm ground 316 stainless bar, at least 300 mm; clamping shaft hub, 20 mm bore, about 56 mm flange with four 5.5 mm holes.
- **Bearings (line 3).** Two 4-bolt flange units, 20 mm bore, UCF204 class, sealed inserts with two set screws; rubber V-ring for a 20 mm shaft; 280 x 280 x 8 mm aluminium plate; 160 mm PVC pipe offcut.
- **Coupling (line 4).** Jaw coupling, L-075 class, with an elastomer spider, bores to suit the shaft and the generator.
- **Generator (line 5).** Low-speed three-phase permanent magnet motor used as a generator, about 500 W, about 10 rpm per volt, face mounting with a spigot and a shaft at least 50 mm long, overspeed rating at least 800 rpm.
- **Housing and lid (line 6).** 315 mm SN4 sewer pipe offcut at least 310 mm long; 400 x 400 x 12 mm HDPE sheet.
- **Pipework (line 7).** 125 x 90 mm reducing tee, 125 x 90 mm reducer, three 90 mm 90° elbows, 2 m of 90 mm PVC pipe, solvent cement, two 90 mm flexible couplings, PETG filament, 2 mm EPDM sheet.
- **Valve (line 8).** Full-bore 125 mm PVC-U gate valve, PN10 class, solvent-weld sockets for 125 mm pipe at both ends, multi-turn handwheel (never a quarter-turn valve); 175 mm of 125 mm pipe, cut from the penstock, for the pipe piece.
- **Forebay (line 10).** Tub, 125 mm tank connector, 6 mm stainless mesh, aluminium angle and rivets.
- **Rectifier, controller, resistors, wiring (lines 13 to 16).** As Table 2.
- **Fixings (line 19).** Stainless or galvanized: 2 m of M10 threaded rod, 24 M10 nuts, 16 penny washers 30 mm, four M10 x 80 bolts, eight M6 x 25 bolts with nuts and washers, four M6 x 20 screws, four M5 x 16 screws, four M4 x 12 screws, four M5 and four M4 heat-set inserts, four M12 anchors, M8 bolts for the stands.

## 4. Putting it together

In each picture the parts already fitted are grey and the part being fitted is in colour, with an arrow showing the way it goes in.

### Step 1: frame onto the pad

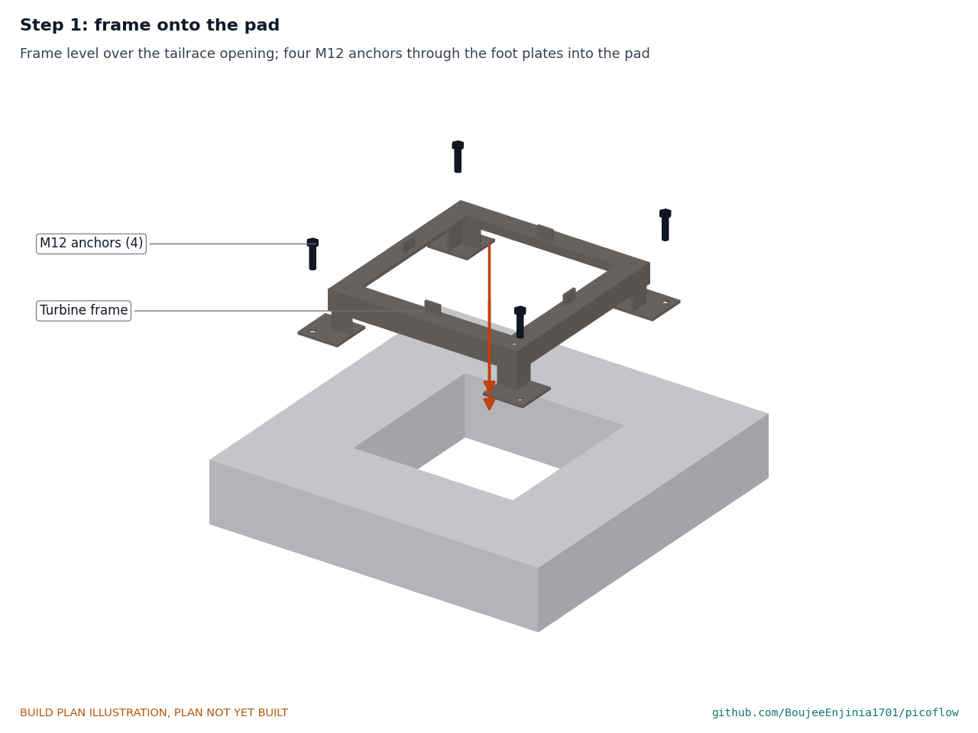
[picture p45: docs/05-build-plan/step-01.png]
Step 1


Set the frame level over the tailrace opening (shim the feet if needed) and fix it with four M12 anchors through the foot plates.

### Step 2: tie rods into the frame

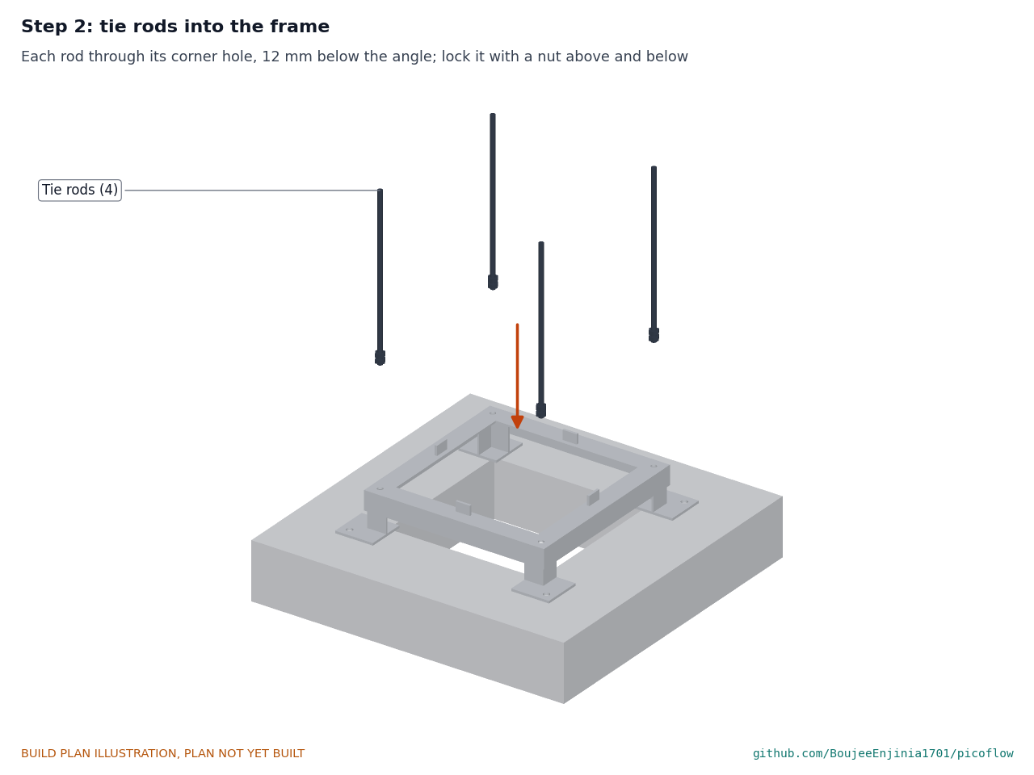
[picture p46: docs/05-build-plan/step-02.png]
Step 2


Each rod through its corner hole with 12 mm below the angle; lock it with a nut above and a nut below, tight. The rods stand upright.

### Step 3: nozzles onto the housing (on the bench)

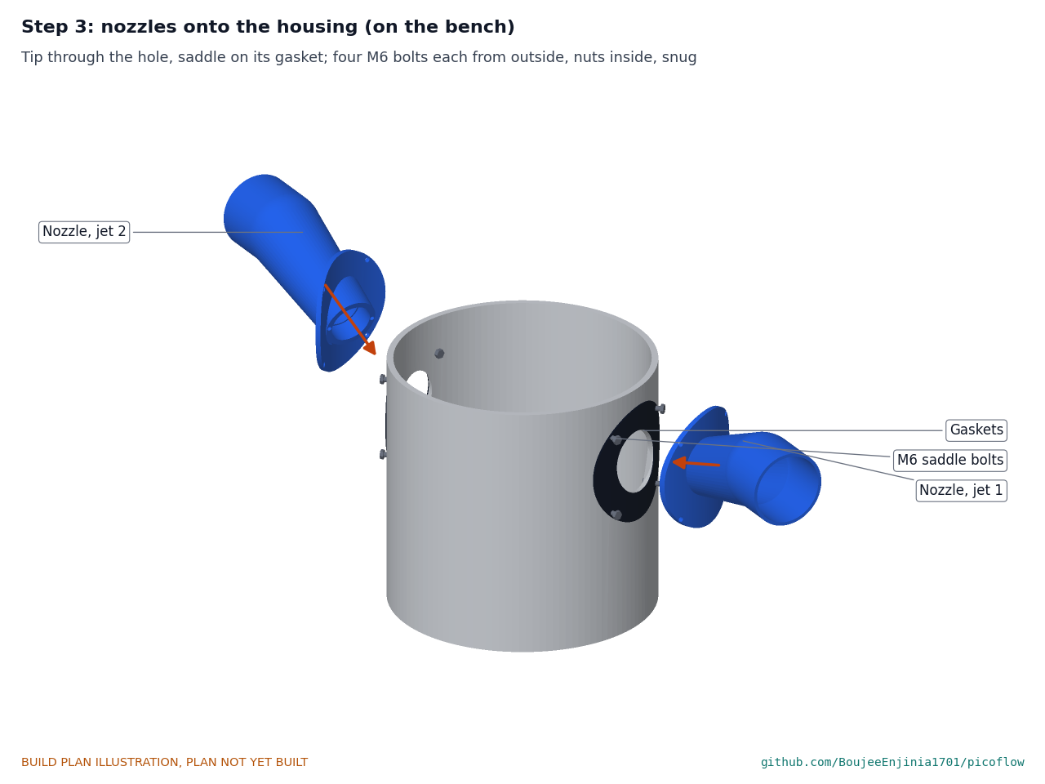
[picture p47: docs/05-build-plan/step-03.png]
Step 3


Lay the gasket on the saddle, pass the tip through the hole from outside and fit four M6 bolts from outside with washers and nuts inside. Tighten evenly until the gasket is just squeezed.

### Step 4: inserts into the nozzle tips

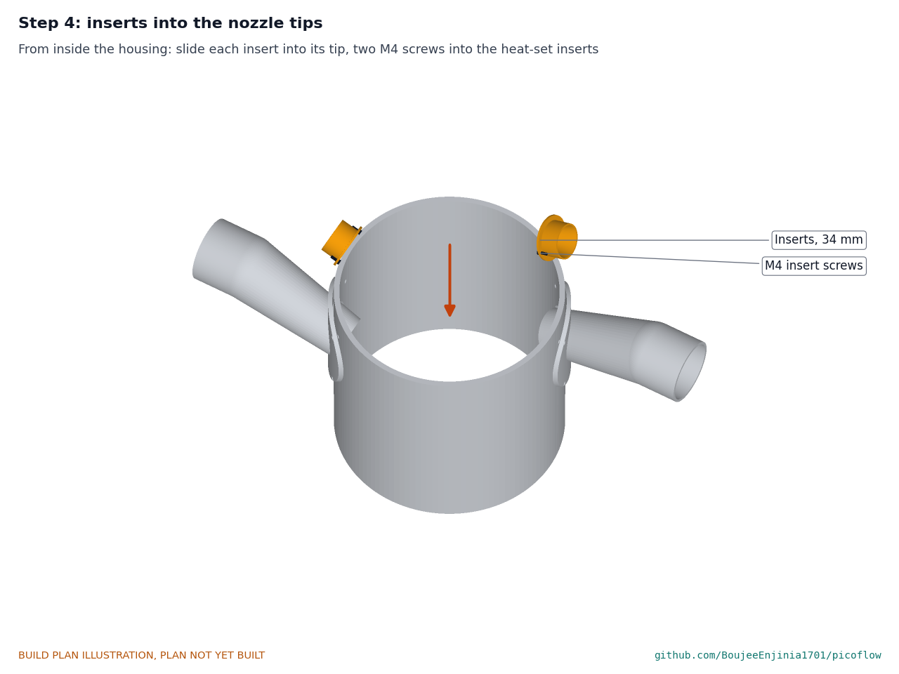
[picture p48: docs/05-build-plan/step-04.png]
Step 4


From inside the housing, slide each 34 mm insert into its tip and fit two M4 screws into the heat-set inserts.

### Step 5: housing onto the frame

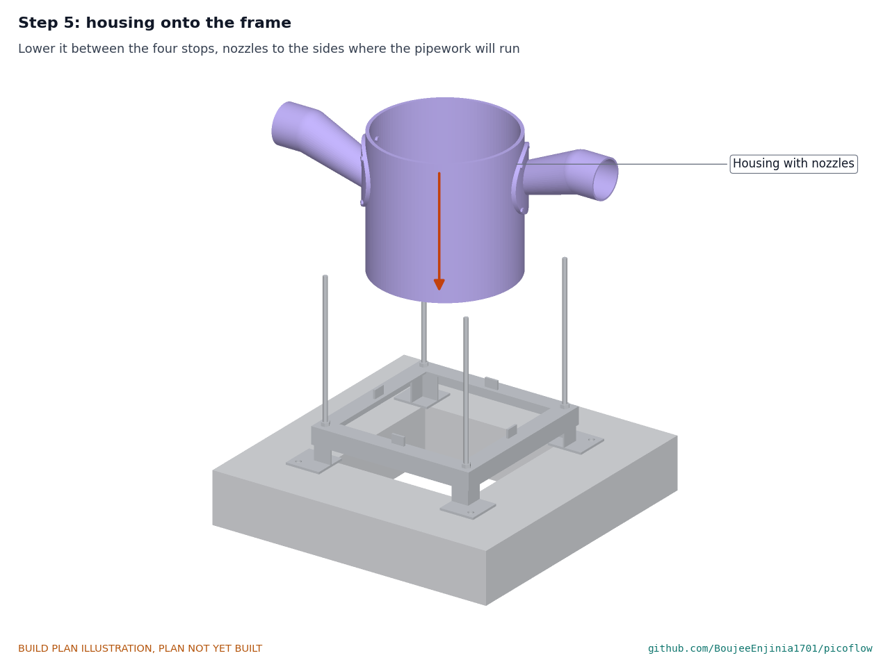
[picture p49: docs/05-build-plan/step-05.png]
Step 5


Lower the housing between the four stops with jet 2's nozzle toward the penstock side and jet 1's toward the far side.

### Step 6: bearings onto the lid (on the bench)

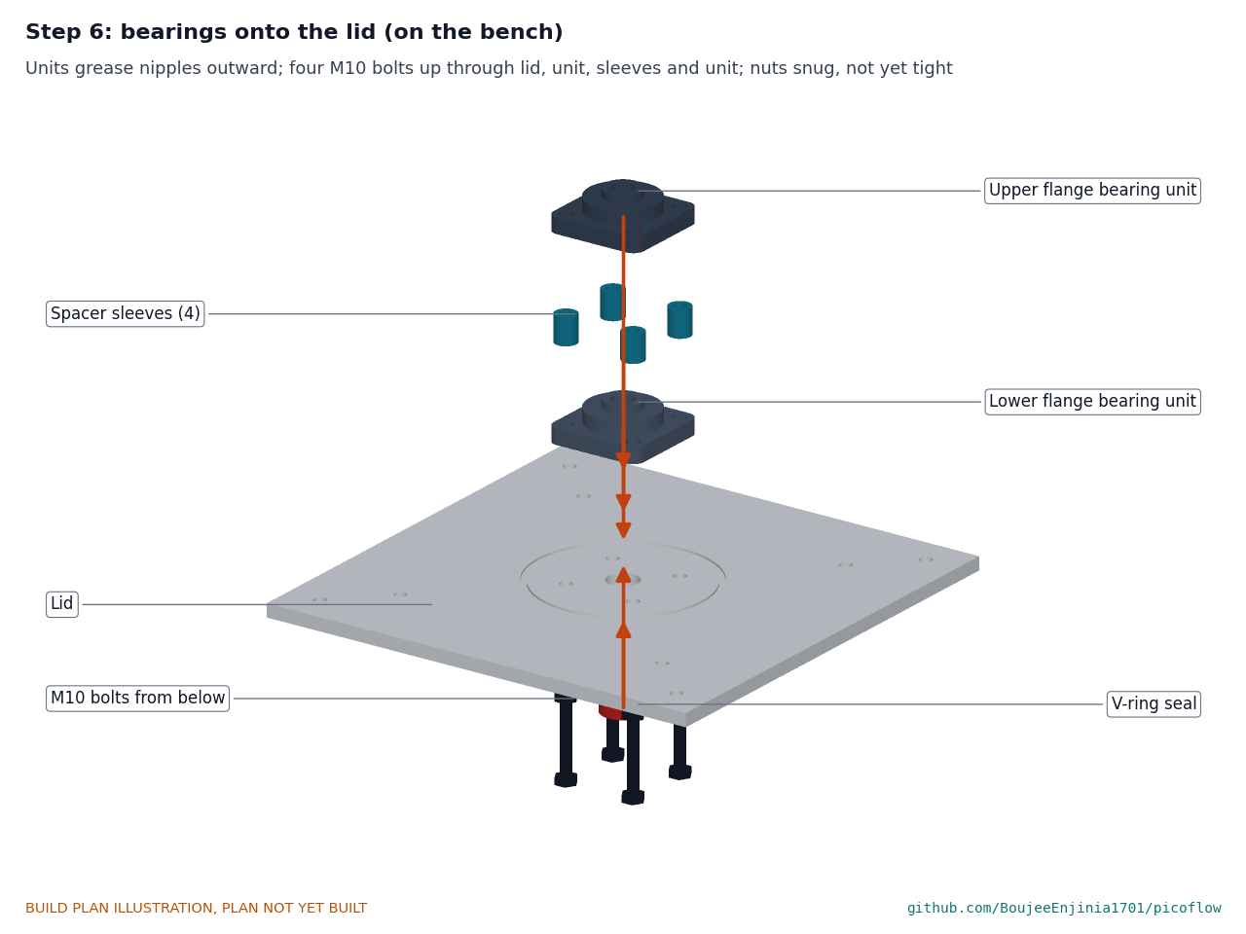
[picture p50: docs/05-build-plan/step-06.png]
Step 6


Put the four M10 bolts up through the lid from below, then the lower unit, the four sleeves and the upper unit, with both units the same way up. Fit the nuts snug, not yet tight. Keep the V-ring by the lid; it goes onto the shaft in step 8.

### Step 7: clamping hub onto the runner (on the bench)

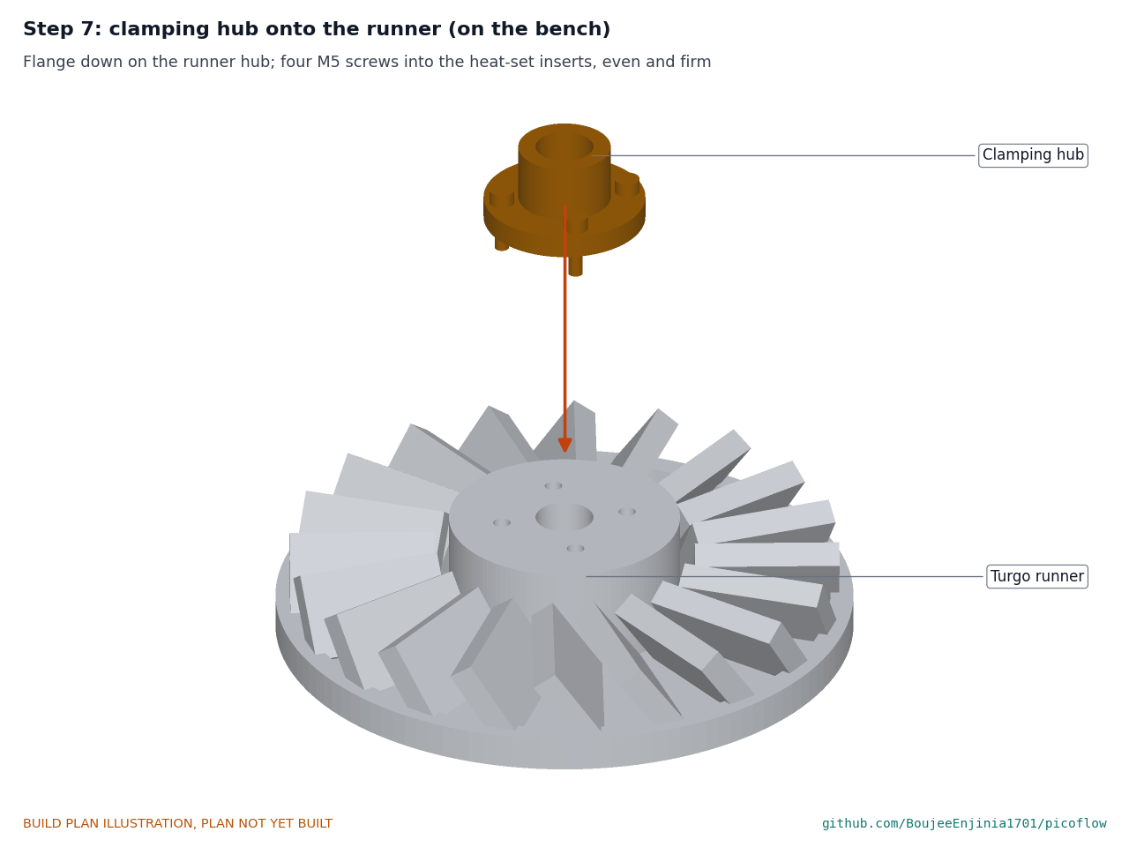
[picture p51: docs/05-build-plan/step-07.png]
Step 7


Flange down on the runner hub; four M5 screws into the heat-set inserts, even and firm.

### Step 8: shaft through the bearings

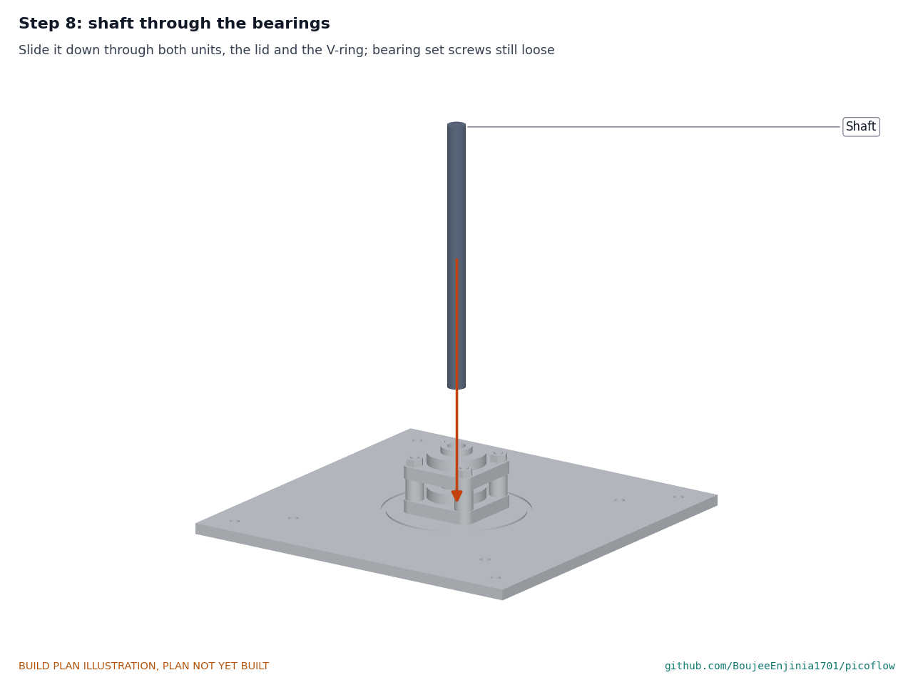
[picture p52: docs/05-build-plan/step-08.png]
Step 8


With the lid on trestles, slide the shaft down through both units and the lid, and push the V-ring onto it under the lid. Tighten the four bearing bolts. Leave the bearing set screws loose.

### Step 9: runner onto the shaft

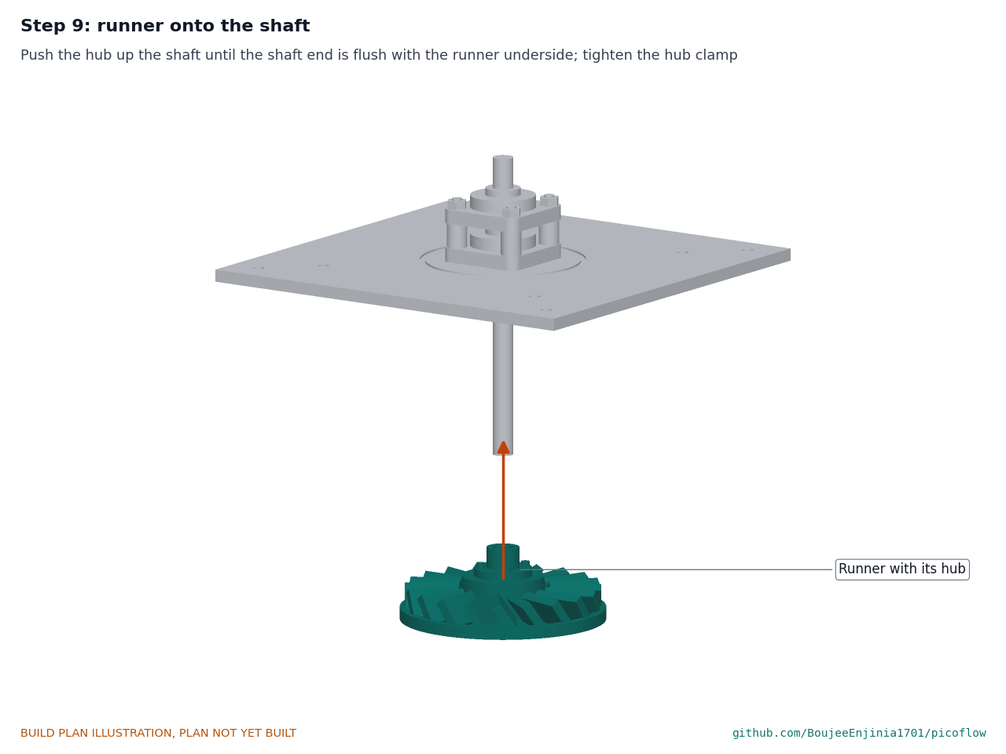
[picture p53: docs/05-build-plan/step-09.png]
Step 9


Slide the runner's hub up the shaft until the shaft end is flush with the runner underside; tighten the hub clamp screw. Set the height so the top of the upper bearing is 30 mm below the shaft top, then spot and tighten the bearing set screws. Slide the V-ring up until its lip just touches the lid.

### Step 10: lid assembly onto the housing

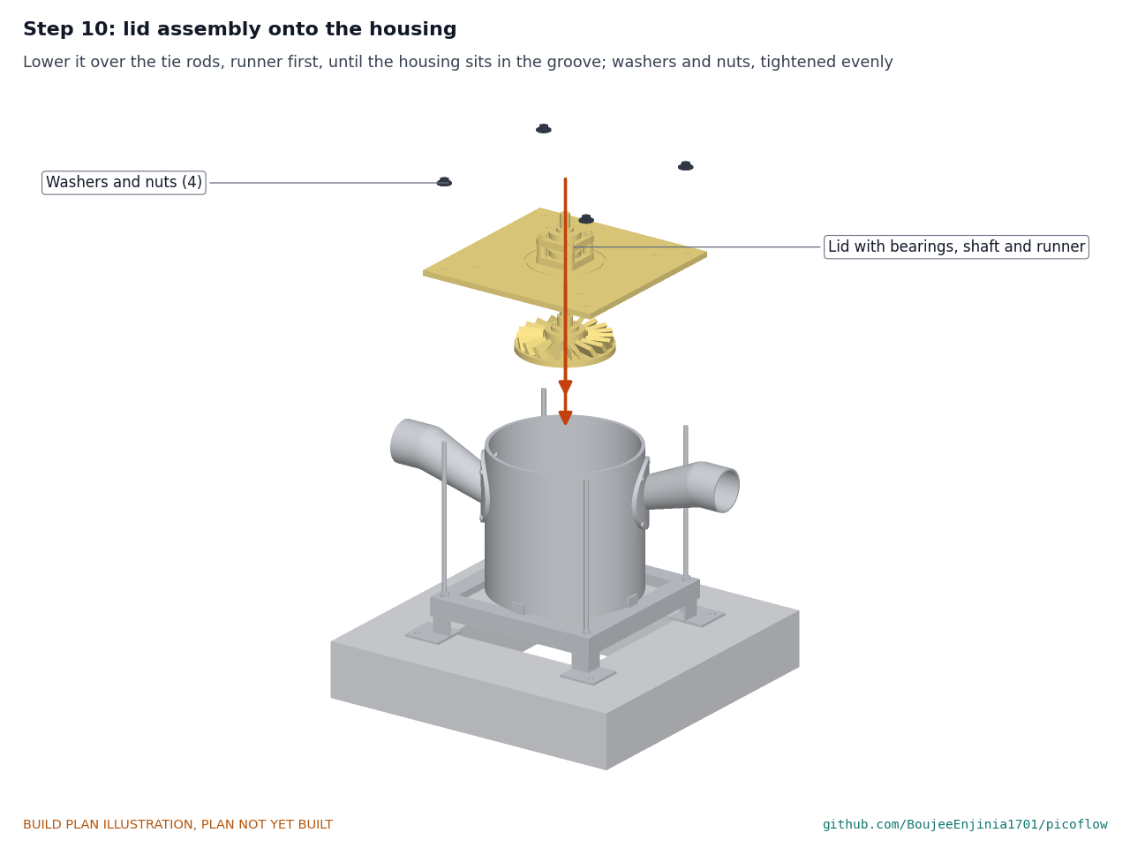
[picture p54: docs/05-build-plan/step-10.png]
Step 10


With a helper, lower the lid with its bearings, shaft and runner over the tie rods, runner first, until the housing sits in the groove. Fit a 30 mm washer and nut on each rod and tighten them evenly in a cross pattern. **Hold point:** turn the runner by hand through the lid hole: it turns freely and touches nothing.

### Step 11: guard and posts onto the lid

Step 11

Stand the guard in its groove. Put each post rod up through the lid from below with a 30 mm washer and nut under the lid, then slide a post over it.

### Step 12: generator onto the plate (on the bench)

Step 12

Stand the generator on the plate with its spigot in the centre hole and fit four M6 screws from below into its face.

### Step 13: coupling onto the shaft

Step 13

Fit the lower coupling hub on the shaft 10 mm above the upper bearing, and the upper hub on the generator shaft, with the spider between them; tighten the hub screws once the jaws are engaged in step 14.

### Step 14: generator and plate onto the posts

Step 14

Lower the plate over the post rods, engaging the coupling jaws, until it sits on the posts over the guard. Fit a washer and nut on each rod. Check the shaft turns by hand with the generator, then tighten the coupling hubs.

### Step 15: pipe stands

Step 15

Set the three stands on the pad under the line of the pipework, clips 290 mm up to their lowest point; fit the anchors loosely.

### Step 16: pipework onto the stands and nozzles

Step 16

Lay the solvent-welded pipework in the clips with the tee on the penstock side. Slide the flexible couplings over the nozzle spigots and pipe ends and tighten the band clamps snug. Then tighten the stand anchors and clips.

### Step 17: inlet valve and penstock

Step 17

Solvent weld the pipe piece into the free end of the tee's 125 mm run, then the valve onto the pipe piece, stem straight up; solvent weld the penstock into the valve's upstream socket and support it within 300 mm of the valve. Let the joints cure for the time on the cement tin, then close the valve fully.

### Step 18: forebay (at the top of the drop)

Step 18

Fit the outlet connector, bed the tub level at the top of the drop with its overflow notch upstream, join the penstock, and set the screen frame on the rim.

### Step 19: equipment post and electrical boxes

Step 19

Set the post anchor on ground above flood level, at least 1 m from the bank; fit the post, the rectifier and controller boxes on the face toward the turbine and the resistor guard on the side. Wire as Figure 31. **Hold point:** safety stop S4 in section 6.

## 5. First checks

These are the checks a TRL 4 test report would record; this plan only lists them. Requirement numbers are those of PCF-REQ-001.

*Table 3. First checks.*

| Check | Requirement | How | Pass when |
| --- | --- | --- | --- |
| Setting height | R13 | Measure from normal tailwater (or the pad top) to the centre of a nozzle tip | 300 mm or less (280 mm in the model) |
| Parts fit the printer | R9 | Print the runner and both nozzles on a 220 x 220 x 250 mm printer | Each prints in one piece; runner in 24 h or less |
| Free running | R11 | Turn the runner by hand with the generator coupled | Turns smoothly; nothing rubs |
| Screen and inserts | R10 | Gauge the screen mesh and the smallest insert | Mesh 6 mm or less; smallest insert 20 mm or more |
| Valve closing | R17 | Count the turns from open to closed | About ten turns, so it cannot close in under 10 s |
| Clamp | R8 | Bench supply on the DC bus, generator disconnected, raised slowly from 30 to 50 V and back | Clamp switches in at 48 V and out at 40 V, whatever the charger does |
| Diversion | R7 | Bench supply in place of the generator; disconnect the battery | The dump load takes the output within 1 s |
| Output at low flow | R1, R3 | Admit water slowly with the valve; measure head, flow and power into the battery | The bus charges the battery; output recorded against head and flow (80 W at 2.0 m and 10 L/s is the target) |
| Service time | R11 | Time a runner or insert change and a bearing change with hand tools | 30 min and 60 min or less |
| Mass | R14 | Weigh the turbine unit (frame, housing, lid, rotor, bearings, plate, guard, generator, coupling, fixings) | 25 kg or less (24.5 kg estimated); no single item over 15 kg |

## 6. Safety stops

Stop at each point. Carry on only when everything listed is true.

- **S1. Before any work in or beside the stream.** Flow is low, a second person is present, the intake is closed or diverted, and nobody stands on the weir crest.
- **S2. Before the lid goes on (step 10).** No tools, nuts or offcuts inside the housing; every saddle nut tight; the runner turns freely by hand.
- **S3. Before the generator plate goes on (step 14).** The guard is in its groove; the coupling hubs are tight on both shafts.
- **S4. Before any wire is connected to the battery.** The DC side is enclosed in its boxes; the clamp check of section 5 has passed on a bench supply; the battery fuse is out; the isolator is off; the resistor guard is mounted with clear air above it.
- **S5. Before water is admitted.** The generator is wired to the rectifier and the clamp and dump load are connected; nobody is near the runner, coupling or resistors; the valve is opened slowly, a turn at a time.
- **S6. Before opening the housing or removing the plate.** The valve is fully closed (over at least ten turns), the runner has stopped, and the isolator is off. The coupling spider is checked only in this state.
- **S7. Never.** Never weld galvanized steel; never fit an acrylic guard or a window in the housing; never fit a quarter-turn valve; never run with the clamp or dump load disconnected; never leave the screen uncleared, since a nozzle blocked all at once can add about 18 m of head to the drainage pipe.

## 7. Tools, skills and workspace

**Tools.** Hacksaw or bandsaw; angle grinder with cutting and flap discs; welder (or a local fabricator's welding); bench drill or a drill in a stand; drills 3 to 13 mm; jigsaw with fine plastic and metal blades; router with a 6 mm straight bit and a trammel jig; files; deburring tool; steel rule, square, calipers and a 45° mitre square; disc sander; 3D printer with a 220 x 220 x 250 mm bed that prints PETG; soldering iron for heat-set inserts; spanners and sockets 8 to 19 mm; hex keys; masonry drill for the anchors; spirit level; crimper and wire strippers; multimeter; bench power supply to 60 V with a current limit; scale to 30 kg; stopwatch.

**Skills.** A fabricator for the frame and stand welds; basic metalwork and plastics work; 3D printing; solvent welding of PVC; extra-low-voltage DC wiring. All circuits are DC below 60 V in normal running and below 100 V on a double fault; no mains wiring is part of this build.

**Workspace.** A bench about 1.5 x 0.8 m; a ventilated place for welding, grinding and printing; trestles to hold the lid assembly at waist height; at the site, a level pad over the tailrace and firm ground for the stands and post.

**Personal protective equipment.** Safety glasses for cutting, drilling and grinding; welding helmet and gloves for welding; hearing protection when grinding; gloves for sheet and mesh edges; a life jacket and non-slip boots for work beside the stream.

## 8. Where the numbers come from

- Model and constructability checks: `cad/src/model.py` (`python cad/src/model.py --check`, 74 checks); STEP and STL exports in `cad/step/` and `cad/stl/`, including `picoflow-nozzle`, `picoflow-runner`, `picoflow-insert-pair-34mm` and `picoflow-saddle-gaskets`.
- Pictures: `cad/src/build_plan_media.py`, using `.kit/build_views.py`; written to `docs/05-build-plan/` and `cad/drawings/PCF-DWG-101` to `PCF-DWG-114`. Hole template: `docs/05-build-plan/nozzle-hole-template.pdf`.
- General arrangement: `cad/drawings/PCF-DWG-001.pdf`, Rev P5.
- Calculations: `docs/04-calcs/01-sizing.md` (PCF-CAL-001) and `docs/04-calcs/sizing.py`.
- Bill of materials: `bom/bom.csv`.
- Decisions: `docs/decisions/0003-design-for-construction.md` (PCF-DDR-003), with PCF-DDR-001 and PCF-DDR-002.
- Requirements: `docs/03-requirements.md` (PCF-REQ-001 v0.7).

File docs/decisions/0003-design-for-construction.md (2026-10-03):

---
doc_id: PCF-DDR-003
title: PicoFlow design for construction
project: PicoFlow
doc_type: Design decision record
version: "0.4"
status: Draft
date: '2026-10-02'
author: Amish Chadha
license: CERN-OHL-S-2.0
revisions:
- version: "0.1"
  date: '2026-10-01'
  author: Amish Chadha
  change: Changes that make the concept physically buildable, with the reason for each; made under Amish's 2026-09-30 instruction and open for his review
- version: "0.2"
  date: '2026-10-01'
  author: Amish Chadha
  change: A2 accepted by Amish as recommended (full-bore inlet valve); A1 and A3 stay open
- version: "0.3"
  date: '2026-10-02'
  author: Amish Chadha
  change: "A1 and A3 accepted by Amish on 2026-10-02 (design for construction; welded frame from bare steel, galvanized or painted after welding)"
- version: "0.4"
  date: '2026-10-02'
  author: Amish Chadha
  change: "Appearance model updated to the accepted design (no window, one-piece housing, PVC guard); photoreal renders still to be remade on Amish's Mac"
---

# 0003: Design for construction

- **Date:** 2026-10-01
- **Status:** Draft. The changes in Table 1 were made under Amish's 2026-09-30 instruction to make the design physically buildable; open for his review. A2 in Table 3 is accepted: Amish, 2026-10-01: "picoflow - i agree with the recommendation", so option (a), a full-bore valve matched to the 125 mm penstock, re-priced, is decided and recorded in the design decisions register (PCF-DEC-001). A1 and A3 were accepted by Amish on 2026-10-02 ("i approve your recommendations for all 555 open decisions."), which accepts every change in Tables 1 and 2 (P11's valve fittings already superseded by A2) and the welded frame, made from bare steel and galvanized or painted after welding; both are recorded in PCF-DEC-001. The record stays Draft.

## Context

On 2026-09-30 Amish asked for every repo to have an illustrated prototype build plan and wrote: "If you are realising that the design cannot be built as per concept - fix the design assumptions to match and be physically feasible as you draw the illustrations." The TRL 3 model of PCF-DDR-002 showed what PicoFlow does and was sized by calculation (PCF-CAL-001 v0.2), but it was a massing model. Checking it with build123d found parts that float, overlap or have no fixing:

- the 315 mm housing sat inside the 340 mm opening of the frame ring, 12.5 mm clear of it, so nothing carried it;
- each nozzle cut about 25 cm³ into the housing wall, and nothing held a nozzle in place;
- with the lid lifted for service, the runner could not pass the nozzle tips;
- the generator floated 5 mm above its plate;
- the inlet valve was drawn as a solid block on the 125 mm line, although the bill of materials lists a 90 mm valve;
- the reducing tee, elbows and nozzle inlets were placed closer together than real fittings allow.

The changes below keep what PicoFlow does: the same runner, jets, setting height (nozzle centerline 280 mm above tailwater), generator, housing pipe, penstock, valve type, electrics and safety measures. Nothing here changes the pitch or the safety case. Every change is in `cad/src/model.py`, which now builds each component as a separate part and runs 69 constructability checks (`python cad/src/model.py --check`): parts that must touch do touch, parts that must stay apart are apart by at least the stated clearance, and a scan of every pair of components finds no unintended overlap. All 69 pass.

## Decision

*Table 1. Changes made to the model, the BOM and the calculations.*

| # | Problem in the concept | Change made | Why this way |
| --- | --- | --- | --- |
| P1 | Frame drawn as solid square bars, 420 mm square with a 340 mm opening; the 315 mm housing did not rest on it. No feet or fixing to the pad. | A 380 mm square of 40 x 40 x 4 mm angle, horizontal legs inward, welded at mitred corners; the housing wall stands on the horizontal legs. Four 70 mm angle legs welded inside the corners, 80 x 80 x 5 mm foot plates with one M12 anchor each, and four flat bar pipe stops 1 mm outside the housing. | The inner edge of the angle lines up with the housing bore, so the wall bears on its full 7.7 mm and the water falls clear. Nozzles stay 280 mm above tailwater (R13). |
| P2 | Housing, lid and frame were not joined. | Four M10 tie rods, locked to the frame corners by two nuts each, pass up beside the housing and through the lid corners; washers and nuts on the lid clamp the lid onto the housing and the housing onto the frame. A 3 mm groove under the lid locates the housing top (housing cut to 303 mm). | One set of rods holds the whole stack; undoing four nuts frees the lid for service. |
| P3 | Bearing housing drawn as a plain cylinder bored only for the shaft, with an integral 120 mm square flange: no bearing seats, no retention, and it needs a lathe and a large block. | Two bought 4-bolt flange bearing units, 20 mm bore (UCF204 class, sealed 6204-class inserts), stacked on four 24 mm spacer sleeves and clamped to the lid by four M10 bolts with heads under the lid. A rubber V-ring on the shaft under the lid keeps spray off the lower seal. | Flange units come with seats, seals and set-screw locking, need no machining and are replaced in minutes (R11). Load rating 12.8 kN: bearing L10 8.0 x 10^6 h at the worst load (was 8.7 x 10^6 h); R12 bearing part still met. |
| P4 | Runner fixed by a "keyed hub and clamp nut" with no keyway or thread in the model. | A bought clamping shaft hub (20 mm bore, 56 mm flange) grips the shaft; four M5 screws hold the runner to it through heat-set inserts in the runner hub. The shaft ends flush with the runner underside. | No keyway or thread to machine; height is set by sliding the hub on the shaft. |
| P5 | Nozzles were cones that overlapped the housing wall, had no fixing, and met the horizontal 90 mm branches at 20 degrees with no fitting. | Each printed nozzle has a 60 mm horizontal 90 mm spigot, a gentle 20 degree bend and its cone, plus a 6 mm saddle shaped to the housing that sits on a 2 mm EPDM gasket and is held by four M6 bolts through the wall. The wall hole, cut from a full-size template, clears the nozzle by 2.5 mm. A 90 mm flexible coupling joins the spigot to the pipe. Both nozzles are the same part. | The saddle fixes the jet's aim to the housing and seals the hole; the coupling lets the printed nozzle come off without cutting pipe. The nozzle prints standing on its spigot in a 167 x 130 x 244 mm space (R9). |
| P6 | With the lid lifted for service, the runner hit the nozzle tips. | Nozzle exit moved from 85 to 115 mm before the strike point, so the tip sits at the inside of the wall, 19 mm outside the runner's lift path. The runner is lowered 11 mm (mid-plane 224 mm, underside 199 mm above tailwater) so the jet still meets the top of the buckets at the pitch circle. | Runner and inserts are reached by lifting the lid assembly, as R11 intends; the nozzle centerline stays 280 mm above tailwater (R13). The free jet is about 120 mm long, under four jet diameters. |
| P7 | Generator drawn 5 mm above its plate. | Generator sits on the plate, four M6 screws up through the plate into its face (screw circle to match the unit bought). | It needs a fixing; screws from below leave the top clear. |
| P8 | Posts were solid bars with no fixing; at 120 mm offset the washers under the lid would hit the housing. | Each post is a 20 x 2 mm steel tube on an M10 rod, with a 30 mm washer and nut under the lid and a washer and nut on the plate; posts moved to 125 mm each way. | The rod clamps lid, post and plate together; the washers now clear the housing by 4.3 mm. |
| P9 | The 110 mm coupling guard had no fixing and could not pass the bearing bolts. | A 146 mm length of 160 mm PVC pipe stands in a 2 mm groove on top of the lid and stops 1 mm under the generator plate, covering both bearing units and the coupling. | Fixed by the plate, nothing to screw; nothing that turns can be reached while the plate is on. |
| P10 | The penstock entered the side branch of a 125 x 90 tee, which standard tees do not offer; jet 2's elbow sat inside the tee and its reducer; there was no room between the last elbows and the nozzles. | Penstock moved to the jet 2 line (75 mm off the turbine axis) and into the run of a 125 x 90 reducing tee. Jet 2 goes straight through the tee and a 125 x 90 reducer; jet 1 leaves the 90 mm branch and runs round the housing through three elbows, the far corner moved from 330 to 460 mm. Five pipe lengths are given by the model (275, 970, 135, 100 and 110 mm). | Every fitting is a standard one with its socket depth allowed for. Branch lengths from the model: jet 1 1.67 m, jet 2 0.23 m. |
| P11 | The 90 mm valve of BOM line 8 was drawn as a solid block on the 125 mm line, and the calculation took it as full bore. | A 125 x 90 reducer, two short nipples and a 90 x 125 expander join the 90 mm valve into the 125 mm line. Their loss, 0.084 m at the design point, is now in PCF-CAL-001. Superseded on 2026-10-01 by A2 (a): a full-bore 125 mm PVC-U gate valve with solvent-weld sockets, joined to the tee by a 175 mm piece of penstock pipe (see Consequences). | The valve as bought can only be joined this way. The valve bore itself was open decision N6; see Table 3. |
| P12 | The branch pipework (about 6 kg with fittings, more with water) had no support. | Three pipe stands of 40 x 40 x 4 mm angle with foot plates and 90 mm pipe clips on M8 bosses (new BOM line 18). | Holds the pipework at the nozzle height without loading the printed nozzles. |
| P13 | The forebay had no outlet fitting or screen frame. | A 125 mm tank connector in the downstream end and a 6 mm stainless mesh riveted to an aluminium angle frame resting on the rim. | Lets the penstock join the tub and the screen lift off for cleaning. |
| P14 | Fixings were not listed. | New BOM line 19 for rods, bolts, nuts, washers, heat-set inserts and anchors. | Every joint above needs them. |

*Table 2. Knock-on changes.*

| Item | Change | Reason |
| --- | --- | --- |
| Hydraulics | Valve reducer and expander add 0.084 m of loss; jet 2's straight path through the tee cuts its branch loss from 0.055 to 0.020 m; jet 1 has three elbows, not four. Pipe and branch loss is 20.3 % of head with the design inserts (was 17.0 %). Design-point insert 34 mm (33.7 mm for exactly 10 L/s, rounded; was 33 mm). Into the battery 82.5 W at 10.16 L/s, 81.7 W at exactly 10 L/s; water to wire 41.4 %; 1.98 kWh a day. R3, R5 and R6 still met; the margin on R3 is now 1.7 W at exactly 10 L/s. | Follows the model (P10, P11). |
| Other requirements | R1, R2, R4, R8, R17 recalculated and still met: 25.5 W at 1.0 m and 7 L/s; 1.3 to 11.0 L/s at 1.0 m and 1.9 to 15.6 L/s at 2.0 m; clamped bus 38.7 V at most; surge peak 33.4 kPa. | Small changes in flow split and losses. |
| Mass | Turbine unit (items 1 to 6 and 11, with their fixings) 24.5 kg, under R14's 25 kg. To keep it there the generator plate is 8 mm (was 10 mm), the foot plates 5 mm and the post tube 20 x 2 mm. | Tie rods, foot plates, bearing units and fixings add about 2 kg over the TRL 3 estimate of 22.2 kg, which left fixings out. |
| Cost | BOM lines 2, 3, 7, 8, 10 and 12 repriced and lines 18 and 19 added: turbine kit USD 534 with a new generator, USD 84 over the USD 450 value-engineering target; USD 464 with a salvaged motor. | Parts added for construction; `budget_usd` is unchanged. |
| Drawing | PCF-DWG-001 Rev P3; making sketches PCF-DWG-101 to 114 added. | Follows the model. |
| Documents | PCF-CAL-001 v0.3, PCF-REQ-001 v0.5 and PCF-PRC-001 v0.5: numbers updated. No performance or safety requirement changed status; R15 is now reported against its value-engineering target (USD 84 over) rather than as met. | Follows the model and Amish's 2026-10-01 instruction on budgets. |

*Table 3. Items for Amish: A2 accepted as recommended on 2026-10-01; A1 and A3 accepted as recommended on 2026-10-02.*

| # | Question | Options | Recommendation |
| --- | --- | --- | --- |
| A1 | Accept the design-for-construction changes P1 to P14. | (a) accept; (b) accept with changes. | (a), noting that P11's valve fittings are replaced by the full-bore valve of A2. Accepted by Amish, 2026-10-02. |
| A2 | Inlet valve bore (N6, now quantified). The 90 mm valve with its reducer and expander costs 0.084 m of head; at exactly 10 L/s output is 81.7 W, 1.7 W over R3. A full-bore valve on the 125 mm line gives 85.6 W and 43.6 % water to wire. | (a) full-bore valve matched to the penstock, re-priced in the kit; (b) keep the 90 mm valve and its fittings. | (a), because R3 now rests on a 1.7 W margin and the runner efficiency is still unmeasured. Accepted by Amish, 2026-10-01. |
| A3 | Frame made by welding. | (a) welded by a local fabricator, as modelled; (b) a bolted frame with corner gussets, more parts but no welding. | (a): simplest and stiffest; one fabricator visit. Accepted by Amish, 2026-10-02: welded from bare steel, then hot-dip galvanized or painted; never welded after galvanizing. |

## Consequences

- `design_state: constructable` in `project.yaml`. The build plan PCF-BLD-001 shows every component and step in pictures generated from the model (`cad/src/build_plan_media.py`); open items are in the design decisions register PCF-DEC-001.
- Requirement status (PCF-CAL-001 v0.3): none not met, 1 at risk (R12, printed runner life), 3 not verifiable at TRL 3, 12 met, and R15 over its value-engineering target by USD 84.
- The appearance model `cad/src/product_model.py` was updated on 2026-10-02 to the accepted design (one-piece housing, no window, PVC guard) and its render scenes exported. The photoreal renders (`media/render-*.png`), `media/card.png` and `media/social-preview.png` still show the earlier design until they are remade on Amish's Mac, where Blender is.
- With A2 accepted (2026-10-01), the 90 mm valve, reducer, expander and nipples are replaced in the model, BOM line 8 and the build plan (section 3.14, step 17, joint 13) by a full-bore 125 mm PVC-U gate valve with solvent-weld sockets, about 330 mm long and 5.5 kg (catalogue class, to confirm), joined to the tee by a 175 mm piece of penstock pipe. The model now runs 74 constructability checks, all passing. PCF-CAL-001 v0.4: 85.6 W into the battery at exactly 10 L/s, 5.6 W over R3 (was 81.7 W and 1.7 W); 87.8 W with the 34 mm inserts; water to wire 43.6 % at 10 L/s. The kit is USD 614, USD 164 over the USD 450 value-engineering target (line 8 from USD 40 to USD 120, an estimate to be quoted). The turbine unit stays 24.5 kg; the pipework carried separately is 9.8 kg (was 6.3 kg). PCF-DWG-001 is Rev P4.
- With A1 and A3 accepted (2026-10-02), the frame and pipe stands are welded from bare steel and galvanized or painted afterwards, never welded after galvanizing; the build plan states this, and the BOM descriptions of lines 11 and 18 still say galvanized angle until they are revised.
- Bought parts are chosen at TRL 4; their sizes (flange units, generator face, fitting socket depths, valve bore) must be checked then and the model moved to suit.

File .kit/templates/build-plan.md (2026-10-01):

---
doc_id: PRJ-BLD-001
title: Project prototype build plan
project: Project name
doc_type: Build plan
version: "0.1"
status: Draft
date: YYYY-MM-DD
author: Amish Chadha
license: CERN-OHL-S-2.0
revisions:
  - version: "0.1"
    date: YYYY-MM-DD
    author: Amish Chadha
    change: First build plan; design made constructable
---

# Project prototype build plan

**Plan, not yet built.** How to build the first proof-of-concept prototype, component by component. Building and testing to it is TRL 4 work. Decisions still to be made are kept in the design decisions register (`docs/06-design-decisions.md`), not here.

## 1. What you are building

Every component, pulled apart and numbered in build order

One short paragraph: what the prototype is, how many components, which are made and which are bought, and the main ways they are made.

## 2. What changed to make it buildable

| Component | The concept had | The buildable design has | Why |
| --- | --- | --- | --- |

## 3. Making the components

### 3.1 Component name

Making sketch

**What it is and what it is made from.**

**How to make it.**

1. Mark out ...
2. Cut ...

**How it fits the parts next to it.**

Close-up of the joint

**Check before moving on.**

## 4. Putting it together

### Step 1: ...

Step 1

## 5. First checks

| Check | Requirement | How | Pass when |
| --- | --- | --- | --- |

## 6. Safety stops

## 7. Tools, skills and workspace

## 8. Where the numbers come from

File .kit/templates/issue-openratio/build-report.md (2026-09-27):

---
name: Build report
about: Tell us what happened when you built, printed or tested part of this design
title: "Build report: "
labels: build-report
---

This is a research and educational prototype, not a medical device. It is a TRL 3 concept and is not released for fabrication. If you build any part of it, you do so at your own risk. Reports help everyone.

**What you built** (part, sub-assembly or test)

**Materials, tools and settings**

**What worked**

**What did not work, with photos or measurements if you have them**

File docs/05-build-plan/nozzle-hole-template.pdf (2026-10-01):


<- the nozzle's spigot runs off this way (left and up)

# PicoFlow nozzle hole template (one per nozzle)

Print the PDF at 100 % (actual size) on A4 and check the 50 mm bar. Mark a line round the housing
208.6 mm up from its bottom end. Seen from outside, wrap the sheet on the pipe with UP upward and the green line on your mark. Solid line: the hole to cut. Small circles: 6.6 mm bolt holes. Dashed circle: the saddle outline. The second hole is the same, half way round the pipe. Distances are round the pipe surface.

50 mm

BUILD PLAN ILLUSTRATION, PLAN NOT YET BUILT | github.com/BoujeeEnjinia1701/picoflow

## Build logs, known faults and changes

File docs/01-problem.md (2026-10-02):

---
doc_id: PCF-PRB-001
title: PicoFlow problem statement
project: PicoFlow
doc_type: Problem statement
version: "0.5"
status: Draft
date: '2026-10-02'
author: Amish Chadha
license: CERN-OHL-S-2.0
revisions:
- version: "0.1"
  date: '2026-09-24'
  author: Amish Chadha
  change: Initial scaffold
- version: "0.2"
  date: '2026-09-25'
  author: Amish Chadha
  change: Populate to TRL 2 (users, site context, constraints, out of scope, prior work with sources)
- version: "0.3"
  date: '2026-09-25'
  author: Amish Chadha
  change: Apply Amish's 2026-09-25 decisions (PCF-DDR-001) on budget and battery voltage; output range from PCF-CAL-001
- version: "0.4"
  date: '2026-09-25'
  author: Amish Chadha
  change: Recommendations accepted by Amish (DDR-002)
- version: "0.5"
  date: '2026-10-02'
  author: Amish Chadha
  change: "First site and partner selection rule recorded from the decisions of 2026-10-02"
---

# PicoFlow problem statement

Homes near small streams with only 1 to 3 m of usable drop have water running past them all day and night, yet the turbines they can buy for that head are either cheap closed units that wear out in two or three years or professional machines that cost several times a household's budget. PicoFlow aims to be an open, printable, repairable pico hydro turbine for 1 to 3 m of head that charges a household battery with roughly 26 to 156 W, around the clock (PCF-CAL-001 v0.2).

## The problem

About 666 million people had no electricity in 2023, and 85 % of them live in sub-Saharan Africa ([World Bank, Tracking SDG 7: The Energy Progress Report 2025](https://www.worldbank.org/en/topic/energy/publication/tracking-sdg-7-the-energy-progress-report-2025)). Many live in hilly, well-watered areas where a stream passes close to the house. Pico hydro, meaning hydro generation under 5 kW ([Wikipedia, Pico hydro](https://en.wikipedia.org/wiki/Pico_hydro)), turns that stream into continuous power: unlike solar, it runs 24 hours a day, so 83 W of hydro delivers about as much daily energy as 590 W of solar panels (estimate at 4.5 peak sun hours and 75 % system efficiency, see PCF-CAL-001).

The difficulty is head. Most small streams offer a drop of only 1 to 5 m over a practical pipe length, and low-head sites are by far the most common kind ([DFID project R8150, Vietnam country report](https://assets.publishing.service.gov.uk/media/57a08cf340f0b652dd001676/R8150-Vietnam.pdf)). Turbines for that range fall into two groups:

1. **Cheap closed units.** In Vietnam alone, 100,000 to 120,000 low-head propeller units were sold over 10 to 15 years at $20 to $30 for 100 W, but only about 30,000 were still running, because most become unusable after 2 to 3 years. Lower bearings, generator windings and seals fail, and a year of repairs on a 100 W unit costs about as much as the unit ([DFID R8150](https://assets.publishing.service.gov.uk/media/57a08cf340f0b652dd001676/R8150-Vietnam.pdf)). The bearings and generator sit in or near the water, which is the root of the failures.
2. **Durable commercial units.** Well-engineered pico turbines exist for this range, for example the PowerSpout LH propeller turbine for 1 to 5 m of head and 14 to 55 L/s ([PowerSpout LH](https://www.powerspout.com/pages/low-head-lh-info)) and the PowerSpout TRG Turgo for 2 to 30 m and 8 to 16 L/s ([PowerSpout TRG](https://www.powerspout.com/pages/turgo-trg-info)). They are sound machines but are priced and shipped for well-off off-grid owners, and their parts come from one supplier.

The gap is a turbine for 1 to 3 m of head and 5 to 15 L/s that is cheap enough for a household, keeps its bearings and generator out of the water, and can be built and repaired from printed parts and generic components.

Research shows the technical route exists. A single-jet Turgo turbine, normally a medium- to high-head machine, reached 91 % jet-to-mechanical efficiency at 3.5 m of head and 87 % at 1.0 m in laboratory tests at the University of Bristol ([Williamson, Stark and Booker, "Performance of a low-head pico-hydro Turgo turbine," Applied Energy 102 (2013)](https://research-information.bris.ac.uk/en/publications/performance-of-a-low-head-pico-hydro-turgo-turbine)). The same group designs its low-head Turgo to be made "in rural workshops with a minimal amount of tooling" ([University of Bristol, Pico hydropower](https://www.bristol.ac.uk/research/groups/em/electromechanical-power-conversion/pico-hydropower/)). What is missing is an open reference design that a household or local workshop can build with a 3D printer, PVC pipe and an off-the-shelf motor.

## Users and context

| User | Need | Context |
| --- | --- | --- |
| Off-grid household near a stream | Lights, phone charging, radio, a small TV or fridge, all day and night | Stream within 50 m of the house; 1 to 3 m of drop available over 10 to 30 m of pipe |
| Local technician or workshop | Build, install and repair the turbine with local tools and parts, and earn from it | 3D printer or access to one; hand tools; PVC plumbing and electrical parts from town |
| Small institution (clinic, school, farm) | A second, continuous source beside solar, especially in the rainy season when solar is weakest | Existing battery bank, possibly 12 V or 24 V |
| Hobbyist or educator | An inspectable, measurable turbine for teaching fluid machinery and power electronics | Workshop or lab with a hose or a garden stream |

### Operating environment

- **Site:** a small stream, irrigation channel or spring outflow; a weir, rock step or pipe run providing 1 to 3 m of gross head; tailrace returning the water to the same stream.
- **Water:** 5 to 15 L/s available through the turbine, with seasonal variation of perhaps 3 to 1 between wet and dry seasons (estimate; site-dependent); leaves, sand and small stones in the flow; floods several times a year.
- **Climate:** 0 to 40 °C ambient, constant spray and humidity at the turbine, sun and UV on exposed parts.
- **Duty:** continuous, 24 hours a day, often unattended for weeks.
- **Load:** a household battery (commonly 12 V) feeding LED lights and small DC or inverter loads.

## Constraints

- Garage-buildable prototype, $450 USD for the turbine kit (raised from $350 by Amish on 2026-09-25, PCF-DDR-001; a salvaged-motor variant costs about $378). The penstock and the battery are site- and household-specific and are costed separately (see `bom/bom-notes.md`).
- Runner and nozzles 3D-printed on a common desktop printer (build volume about 220 x 220 x 250 mm).
- Generator is an off-the-shelf brushless DC (BLDC) motor used as a generator; no custom windings.
- Bearings and generator kept out of the water and the spray.
- Low voltage only (12 V battery system); no mains voltage in the kit.
- Water is diverted briefly and returned to the same stream; local water-use and environmental rules apply and are site-specific.

## Out of scope

- Heads above about 5 m (conventional Turgo and Pelton designs already serve these).
- Mini-grids and multi-turbine networks (a possible later step; the Bristol group has worked on networking identical units).
- Grid-tie inverters and AC mains output.
- Civil works beyond a simple forebay, screen and pipe support.
- The household battery and inverter, which are specified but not designed here.

## Prior work

- **Low-head Turgo research.** Williamson, Stark and Booker tested a single-jet Turgo at 1.0 to 3.5 m of head and reached 87 to 91 % jet-to-mechanical efficiency ([Applied Energy, 2013](https://research-information.bris.ac.uk/en/publications/performance-of-a-low-head-pico-hydro-turgo-turbine)). Benzon, Aggidis and Anagnostopoulos review how the Turgo carries more flow than a Pelton through the same nozzle and spear system ([Applied Energy 166 (2016)](https://ideas.repec.org/a/eee/appene/v166y2016icp1-18.html)).
- **Commercial pico Turgo.** PowerSpout sells a Turgo turbine for 2 to 30 m of head ([PowerSpout TRG](https://www.powerspout.com/pages/turgo-trg-info)) and a separate DIY Turgo rotor, 180 mm outside diameter with a 90 mm running diameter, jets up to 25 mm and a glass-filled nylon body ([PowerSpout DIY Turgo rotor](https://www.powerspout.com/products/diy-turgo-rotor)). That rotor is designed to fit Smart Drive permanent magnet generators, which are direct-drive washing machine motors; this shows a salvaged low-speed BLDC can serve as a hydro generator.
- **Low-head propeller units.** Cheap propeller units dominate the low-head market in Southeast Asia but have short lives ([DFID R8150](https://assets.publishing.service.gov.uk/media/57a08cf340f0b652dd001676/R8150-Vietnam.pdf)); durable propeller units such as the PowerSpout LH exist at higher cost ([PowerSpout LH](https://www.powerspout.com/pages/low-head-lh-info)).
- **Community pico hydro.** Pico hydro schemes of 1.1 and 2.2 kW in Kenya have powered whole villages ([Wikipedia, Pico hydro](https://en.wikipedia.org/wiki/Pico_hydro)), which shows the social value of continuous small hydro.

## Open questions

- Which first site type, region and co-design partner: a household stream in East Africa, a hill farm in Southeast Asia, or a teaching rig? Selection rule decided 2026-10-02 (PCF-DEC-001): hilly off-grid communities with streams of 5 to 15 L/s and 1 to 3 m of head, confirmed by dry-season flow measurements; first candidate type to approach, a micro-hydro NGO such as Practical Action's energy programmes in Nepal or Peru.
- How common are 1 to 3 m sites with 5 to 15 L/s in the dry season, compared with the larger flows propeller turbines need? This sets whether a Turgo or a propeller is the better low-head choice for the target users.
- Battery voltage: 12 V, decided by Amish on 2026-09-25 (PCF-DDR-001). Whether 24 V households need a variant is left for later.
- Which water-use and fisheries rules apply to small diversions in the first target country?

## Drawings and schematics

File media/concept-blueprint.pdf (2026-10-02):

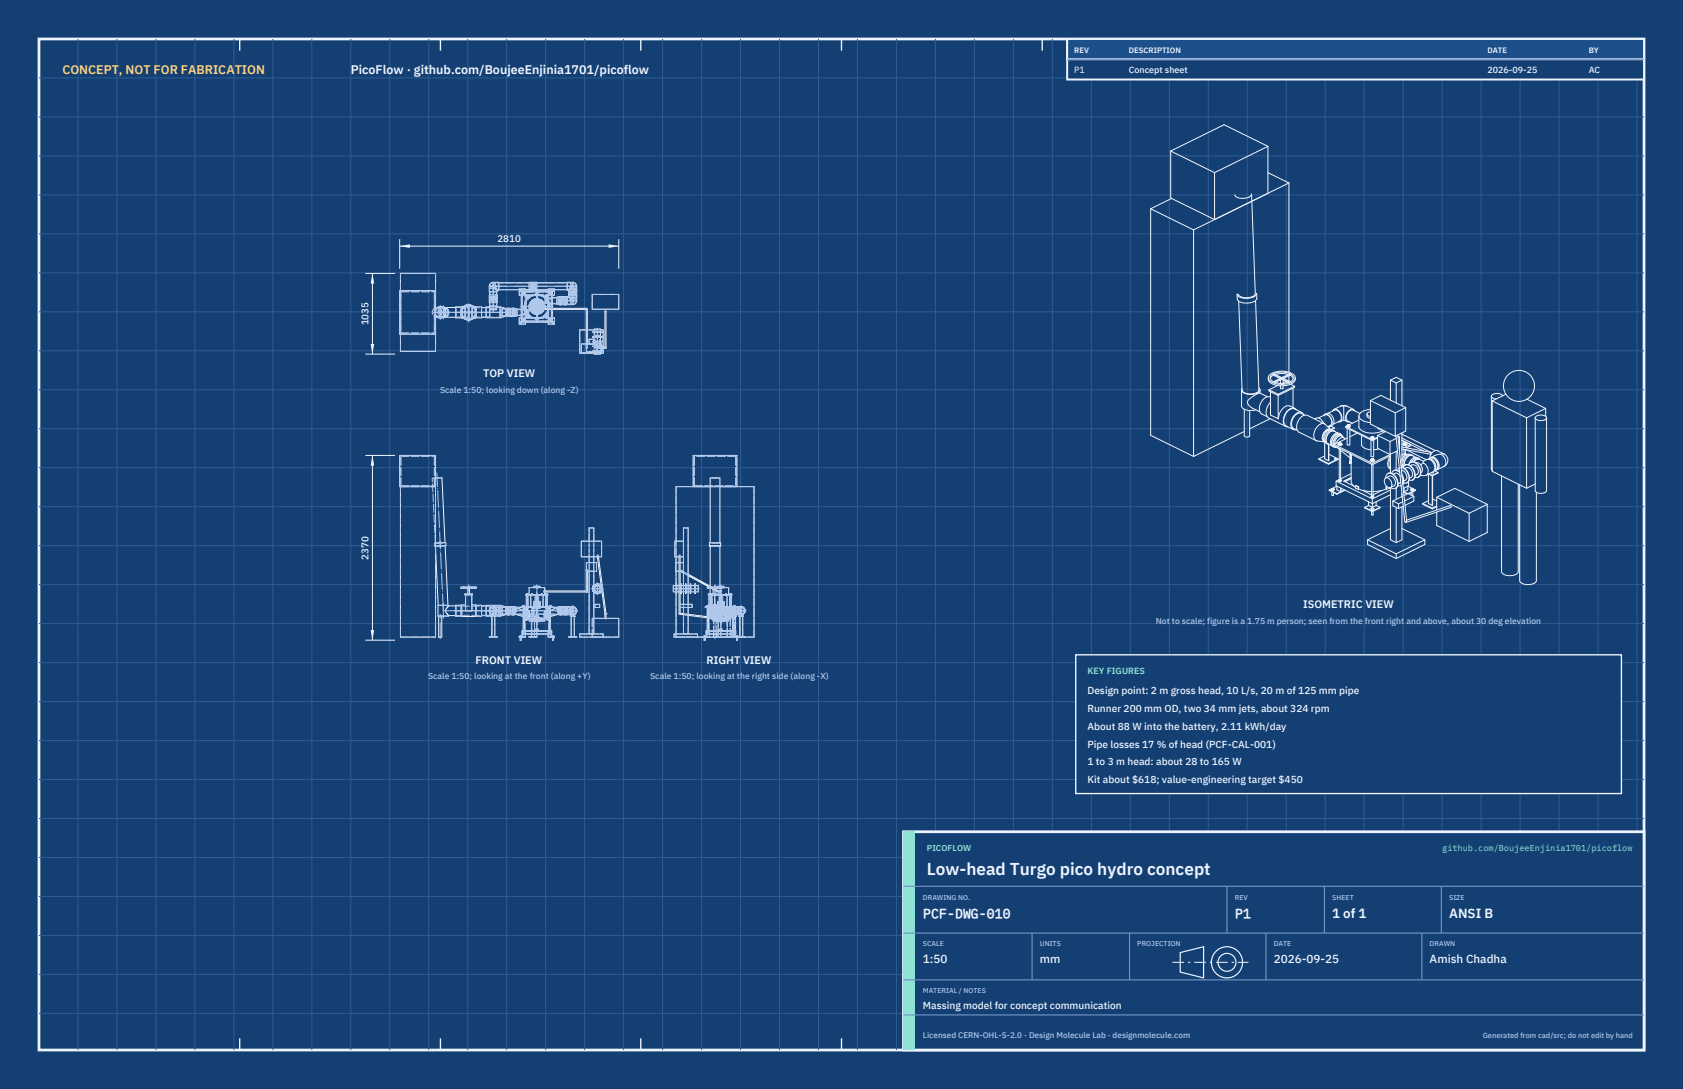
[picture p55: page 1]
CONCEPT, NOT FOR FABRICATION; PicoFlow · github.com/BoujeeEnjinia1701/picoflow; FRONT VIEW; TOP VIEW; RIGHT VIEW; ISOMETRIC VIEW; REV; DESCRIPTION; DATE; Concept sheet; PICOFLOW; github.com/BoujeeEnjinia1701/picoflow; DRAWING NO. PCF-DWG-010; REV P1; SHEET 1 of 1; SIZE ANSI B; SCALE 1:50; UNITS mm; PROJECTION; DRAWN Amish Chadha; Licensed CERN-OHL-S-2.0 · Design Molecule Lab · designmolecule.com; Generated from cad/src; do not edit by hand

Scale 1:50; looking down (along -Z)

Not to scale; figure is a 1.75 m person; seen from the front right and above, about 30 deg elevation

KEY FIGURES
Design point: 2 m gross head, 10 L/s, 20 m of 125 mm pipe
Runner 200 mm OD, two 34 mm jets, about 324 rpm
About 88 W into the battery, 2.11 kWh/day
Pipe losses 17 % of head (PCF-CAL-001)
1 to 3 m head: about 28 to 165 W
Kit about $618; value-engineering target $450

Scale 1:50; looking at the front (along +Y)

Scale 1:50; looking at the right side (along -X)

Low-head Turgo pico hydro concept

MATERIAL / NOTES
Massing model for concept communication

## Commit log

2026-09-24 Initial scaffold: standard open hardware layout, CERN-OHL-S v2 + MIT licenses
    Claude-Session: https://claude.ai/code/session_01XuhhSU4W6fYhgCfURbrkut
    [bom.csv]
2026-09-25 Adopt portfolio kit v1.3.0: session commands, scale figure, 3D viewer, flow diagrams
    Adds .claude/commands (/populate, /advance-trl3, /rein-in, /refresh-media)
    so every Claude Code session starts from the standard prompts, and extends
    concept media with a 1.75 m scale figure, an interactive glTF viewer and
    system or energy flow diagrams. TRL cap 3 unchanged.
    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
2026-09-25 Kit v1.3.1: renderer fixes from the TremorTrace pilot
    Context scale parts for small objects, cutaway exclusions, and text
    labels in flow diagrams.
    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
2026-09-25 Populate picoflow to a strong TRL 2 with concept media (batch 3)
    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
    [bom.csv]
2026-09-25 Advance picoflow to TRL 3 (batch 3)
    Decisions approved by Amish 2026-09-25 recorded in DDR-001. TRL 4 is on hold.
    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
    [bom.csv, picoflow-bearing_mount.step, picoflow-bearing_mount.stl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]
2026-09-26 Accept all recommendations (DDR-002), switch footer to designmolecule.com, add README write-up with new inspiration point
    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
    [bom.csv, picoflow-bearing_mount.step, picoflow-housing.step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]
2026-09-27 Product appearance model and photoreal renders
    Adds cad/src/product_model.py (appearance model for renders only, all main
    dimensions from model.py) and Blender renders in media/render-*.png,
    captioned with the project, repository and viewing direction. README leads
    with the product render; trl stays 3.
    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
2026-10-01 Image quality pass: legible exploded views, flow diagrams and drawing sheets
    Kit 1.6.1 image layout: the parts list sits in its own column, number bubbles sit on visible parts and never overlap, small parts get a leader, pictures are cropped to the subject, flow labels keep numbers with their units, and sheet captions and the revision table no longer overprint. Concept images, blueprint and general arrangement sheet regenerated; repo-specific labels moved clear of other text and lines.
2026-10-01 Kit 1.7.0: constructable design, illustrated build plan and design decisions register
    The design is now constructable: every part can be made and fits its neighbours, with each change recorded in a Design for construction decision record (made under Amish's 2026-09-30 instruction; ope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
    FlexHand also credits Dr. Geeti Chadha as a contribut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
    [bom.csv, picoflow-bearing_mount.step, picoflow-bearing_mount.stl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]
2026-10-01 PicoFlow full-bore valve, GravitySort bump stop, BioMedical cards
    PicoFlow: Amish accepted the full-bore inlet valve ("picoflow - i agree with the recommendation", 2026-10-01); the 125 mm full-bore gate valve replaces the 90 mm valve and its reducer and expander, output 85.6 W at 10 L/s (5.6 W over R3); model, calculations, build plan, pictures, register and PDFs updated. GravitySort: the accepted adjustable rubber bump stop is now in the model, drawings, build plan pictures and documents ("gravitysort - update the documentation, CAD work and picture renderings"). BreatheBox and DustBadge: social preview cards regenerated with the BioMedical area.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
    [bom.csv, picoflow-bearing_mount.step, picoflow-housing.step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]
2026-10-02 Record Amish's approvals for PicoFlow, GravitySort and PalletPilot
    PicoFlow: clamp resistor changed to 6.8 ohm, 350 W; BOM insert size corrected to 34 mm ("I approve of your recommendations for PicoFlow and GravitySort"). GravitySort: slotted pitman pin and leaning legs that let the table reach the bump stop accepted. PalletPilot: about 40 degrees of steering each way accepted for the prototype, pitch wording corrected, and the TRL 4 aisle test made a go or no-go gate for the drive layout ("i accept your recommendations for PalletPilot"). PDFs regenerated.
    [bom.csv]
2026-10-02 Record Amish's approval of the open-decision recommendations
    Amish approved the recommendation on every open decision in the design decisions register ("i approve your recommendations for all 555 open decisions.", 2026-10-02). Each decision is moved to Decisio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
2026-10-03 Carry approved follow-ups into the design and redo photoreal renders
    Amish approved the follow-up actions from the open-decision sign-off ("APPROVED CHANGES, COMPLETE THESE", 2026-10-02), the design-for-construction change tables in ten repos, the last wave's open dec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
    [bom.csv]

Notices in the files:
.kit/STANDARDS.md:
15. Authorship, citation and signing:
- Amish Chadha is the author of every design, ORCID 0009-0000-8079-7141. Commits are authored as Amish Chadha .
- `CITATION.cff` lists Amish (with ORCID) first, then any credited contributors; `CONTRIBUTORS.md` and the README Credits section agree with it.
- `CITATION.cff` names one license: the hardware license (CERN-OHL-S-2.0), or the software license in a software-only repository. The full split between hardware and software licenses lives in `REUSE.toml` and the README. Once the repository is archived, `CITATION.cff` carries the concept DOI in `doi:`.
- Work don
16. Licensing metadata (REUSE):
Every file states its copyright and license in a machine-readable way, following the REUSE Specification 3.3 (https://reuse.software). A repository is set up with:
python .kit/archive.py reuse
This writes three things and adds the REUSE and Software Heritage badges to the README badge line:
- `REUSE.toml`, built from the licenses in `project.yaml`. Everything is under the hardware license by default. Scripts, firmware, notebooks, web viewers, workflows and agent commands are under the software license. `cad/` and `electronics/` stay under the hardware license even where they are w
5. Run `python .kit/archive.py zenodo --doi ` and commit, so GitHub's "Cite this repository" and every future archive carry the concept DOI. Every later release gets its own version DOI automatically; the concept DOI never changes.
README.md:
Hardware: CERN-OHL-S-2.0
